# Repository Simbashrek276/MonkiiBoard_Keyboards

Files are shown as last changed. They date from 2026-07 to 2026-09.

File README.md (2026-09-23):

# MonkiiBoard Keyboards

Hi! This is the home for the MonkiiBoard keyboards, an open little family of boards you can build, flash and print yourself. There are five of them so far, and each one lives in its own folder with the Arduino code, a 3D printable case and a readme that walks you through it. Remember, for every build (aside from MonkiiPad16 and MonkiiBoard58), there will be 2 build pathways you can take, which are either handwiring or PCB-based builds. For starters, I would recommend choosing the handwiring option for certain keyboard builds, as it would make it much more easier to debug and fix using a multimeter and other tools as well!

## The boards

### MonkiiBoard58
MonkiiBoard58 is the newest and the most ambitious build here! This board packed fifty eight keys in a five by twelve ortholinear grid with a rotary encoder on the left, a ESP23 S3 WROOM U1 (Surface mounted component, not through hole) and no cable to the host at all since it runs wireless off a LiPo battery over Bluetooth (well of course we still have to charge the battery by pluggin the USB_C Receptacle in).

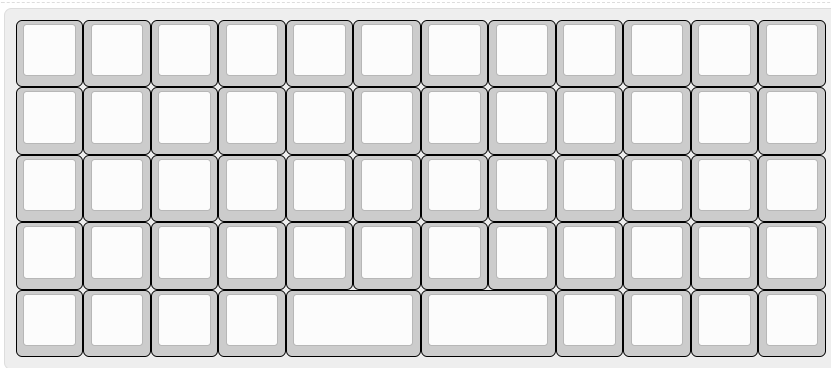
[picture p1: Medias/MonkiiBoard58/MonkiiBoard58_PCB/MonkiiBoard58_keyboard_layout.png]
MonkiiBoard58 layout only


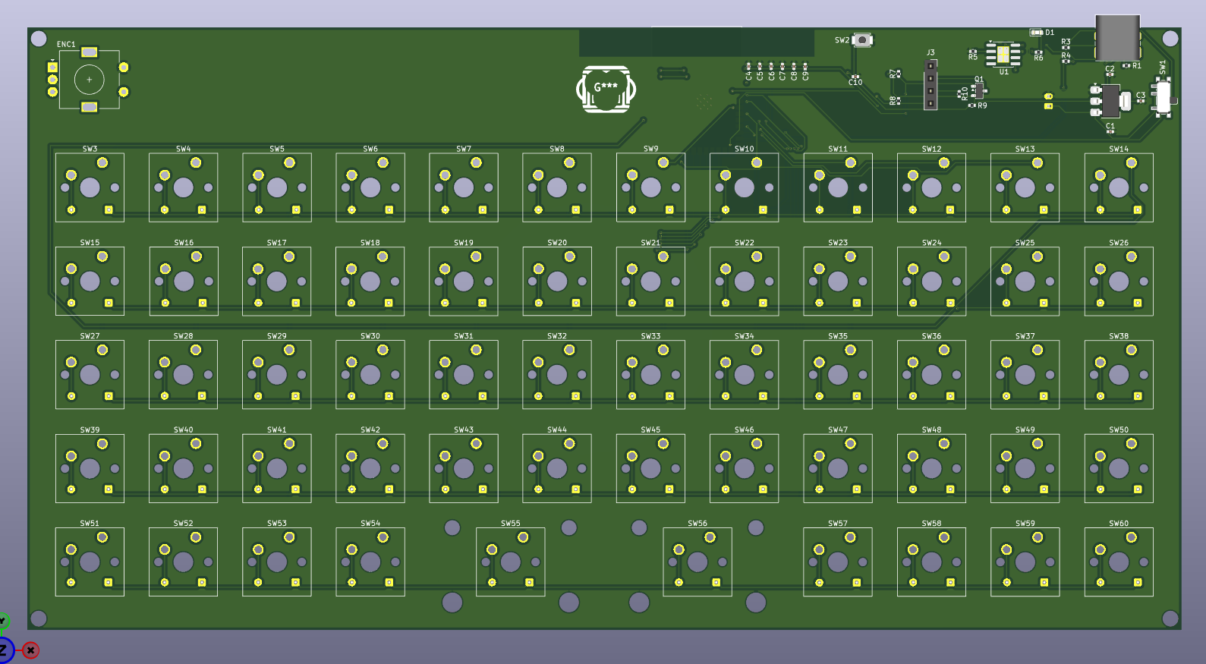
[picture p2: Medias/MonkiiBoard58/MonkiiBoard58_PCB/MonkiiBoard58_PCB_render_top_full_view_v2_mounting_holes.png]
The MonkiiBoard58 PCB rendered from the top, full grid with the OLED window and the encoder visible


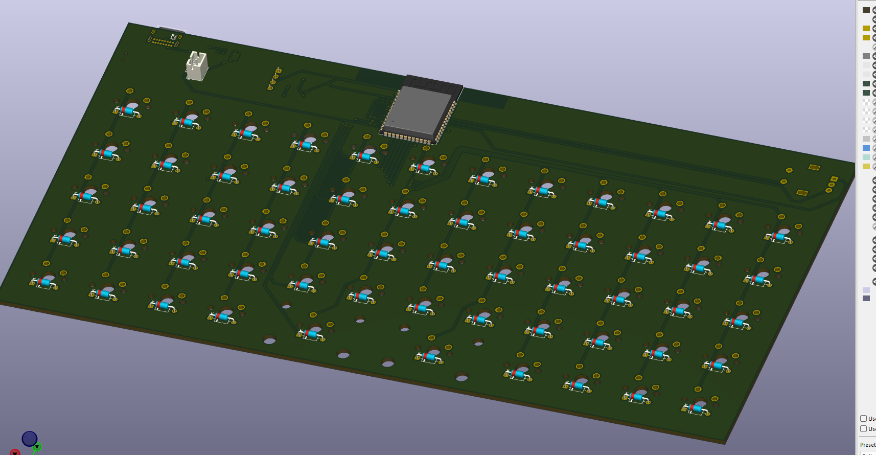
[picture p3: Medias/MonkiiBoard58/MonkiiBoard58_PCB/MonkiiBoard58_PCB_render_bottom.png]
The MonkiiBoard58 PCB rendered from the bottom with diodes (through hole), battery charge port (the white rising component, and the ESP32 S3 WROOM 1)


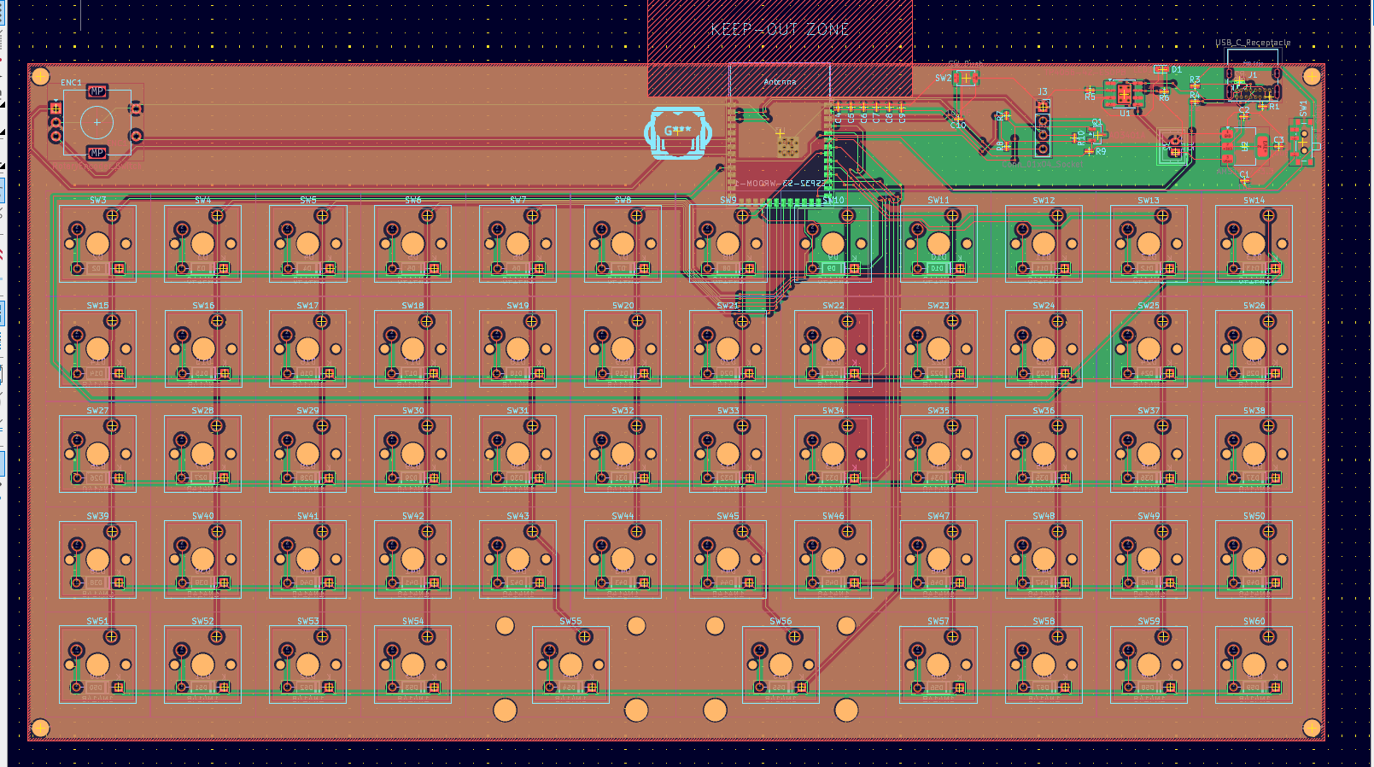
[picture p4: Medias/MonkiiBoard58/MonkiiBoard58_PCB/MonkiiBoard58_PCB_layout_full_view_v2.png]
MonkiiBoard58 PCB


Up to this point, this board only exists as a PCB, no hand wired version, since it carries its own LiPo charger, voltage regulator and a MOSFET power gate for the OLED right alongside the switch matrix. The schematic and layout are finished and the gerbers are ready, but the boards have not gone off to a manufacturer yet, so this is the one board here that has not actually been built in real life.

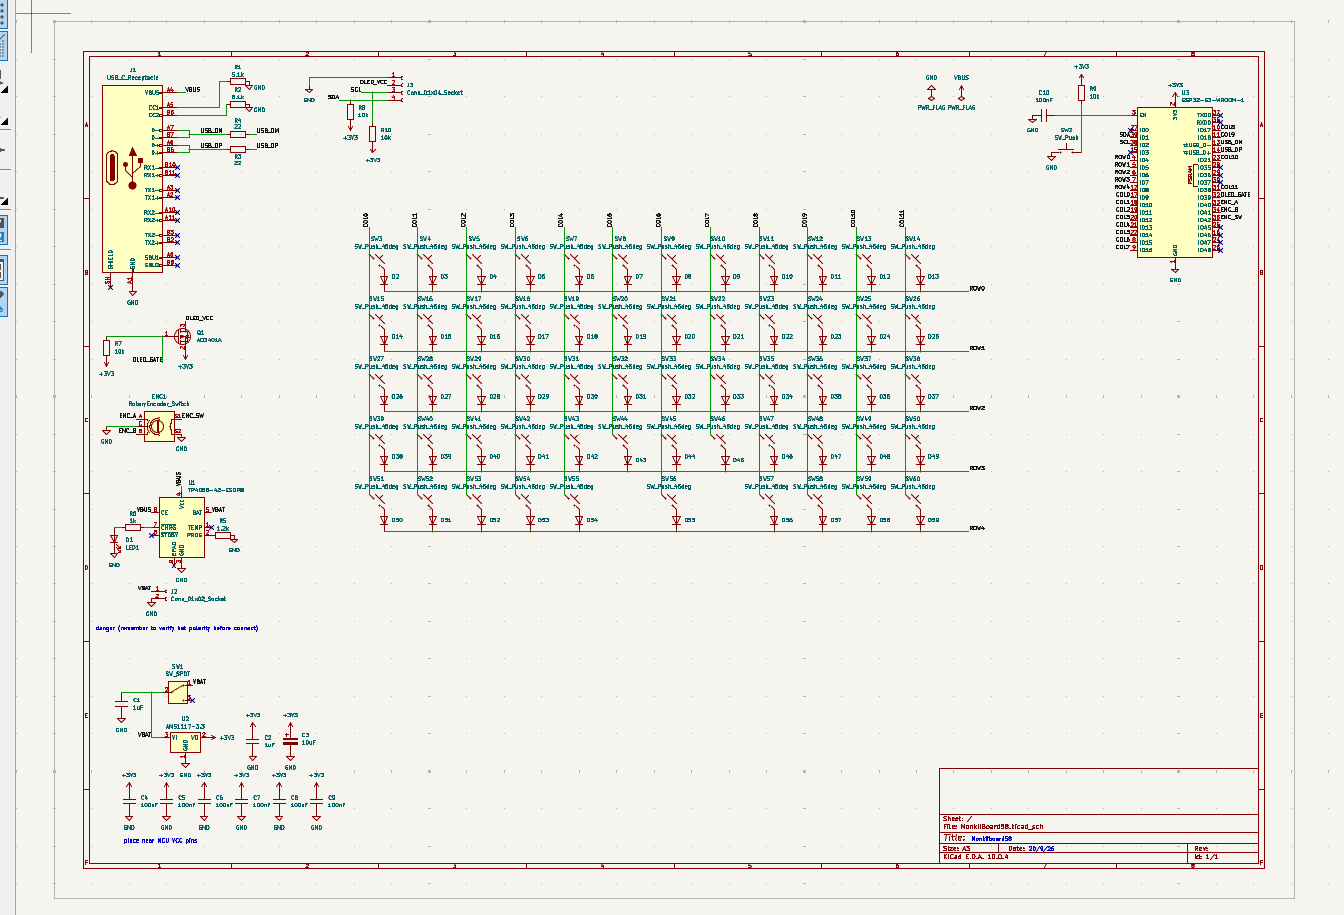
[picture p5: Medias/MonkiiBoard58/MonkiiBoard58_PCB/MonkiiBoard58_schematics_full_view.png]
The full schematic for MonkiiBoard58, matrix, ESP32 S3, OLED, encoder and the power section on one sheet


### MonkiiBoard39
MonkiiBoard39 is MonkiiBoard's second build. THis keyboard has thirty nine keys in a tidy ortholinear 40 percent layout, with sticky modifiers on the bottom row and a Windows key that pops the start menu on a double tap.

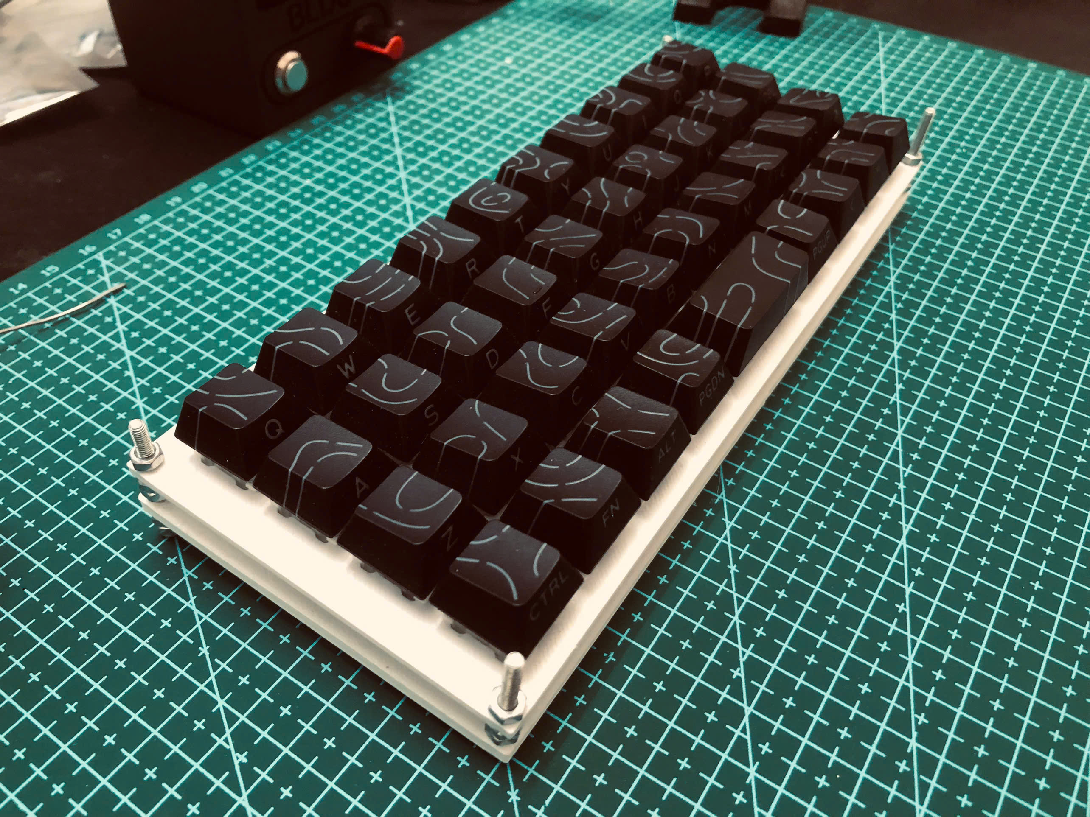
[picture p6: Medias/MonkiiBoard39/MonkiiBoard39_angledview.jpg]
The MonkiiBoard39 seen from an angle


MonkiiBoard39 has a PCB now too, no diodes on this one since the sticky modifiers never need more than one key held down at a time. The schematic below shows all thirty nine switches wired straight into the matrix, with the Pro Micro footprint sitting right in the middle of the board.

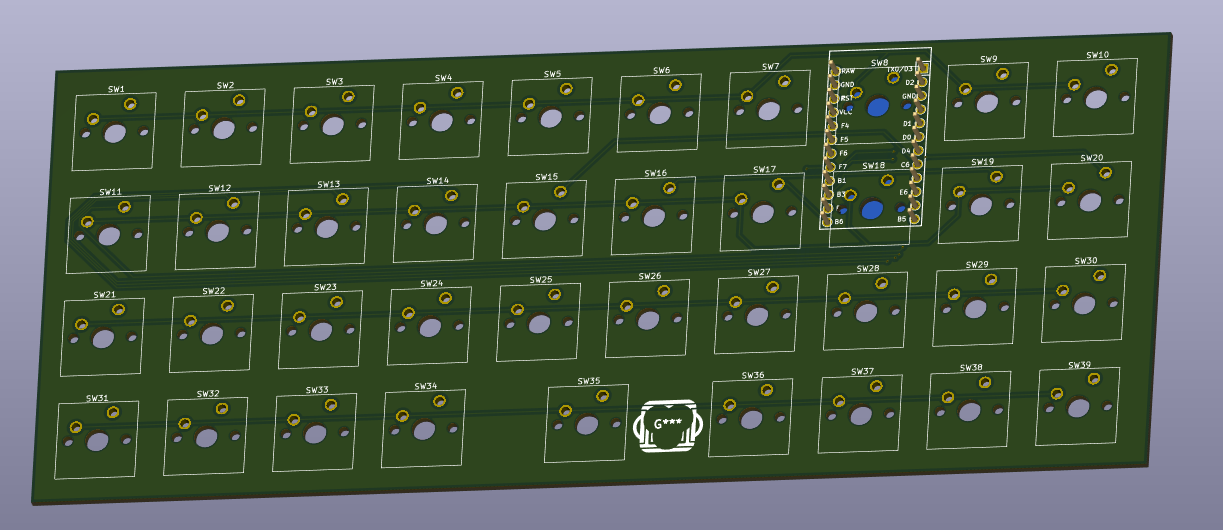
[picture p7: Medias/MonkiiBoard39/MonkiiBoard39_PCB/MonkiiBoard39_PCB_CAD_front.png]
The MonkiiBoard39 PCB rendered in KiCad, thirty nine switches around the Pro Micro footprint


### MonkiiPad20
MonkiiPad20 is our first keyboard with a OLED screen implemented. This macropad is a a twenty key macropad with an OLED screen, two switchable layers and a set of animated robot eyes that appear when you stop using it for a while (approximately 6 - 8 seconds). It is also the only board here that uses diodes (so far).

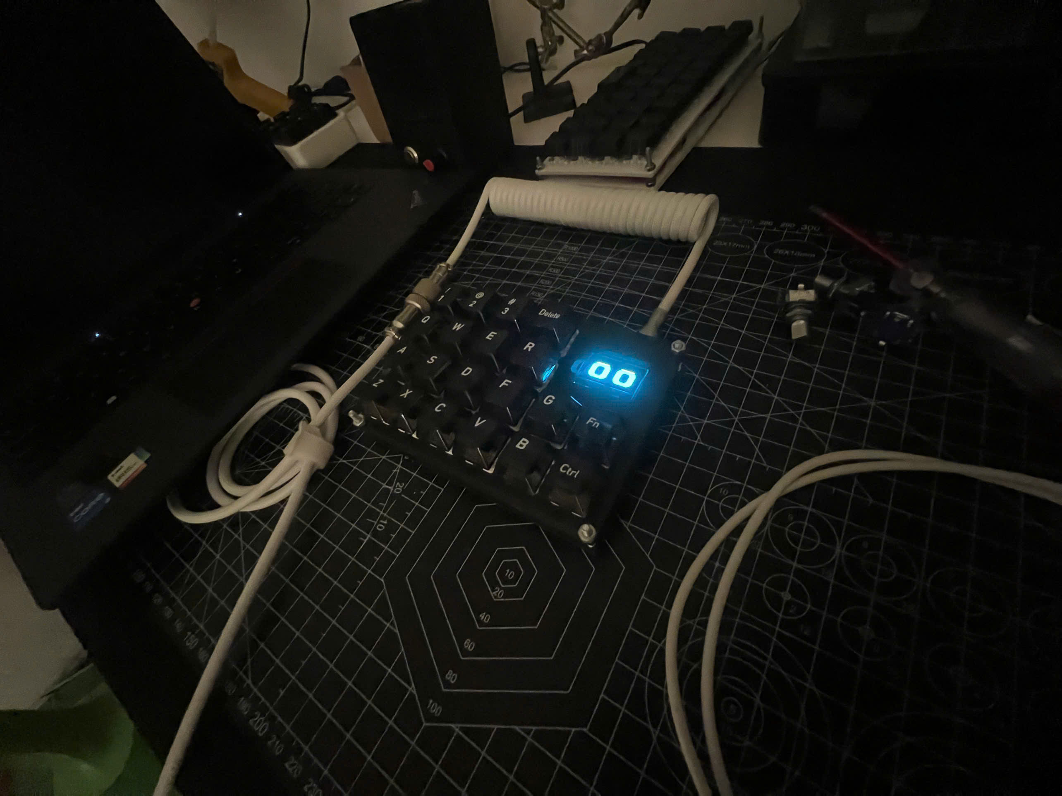
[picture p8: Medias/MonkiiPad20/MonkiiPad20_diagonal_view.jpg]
The MonkiiPad20 with its robot eyes glowing on the OLED


For the MonkiiPad20, we've also made our earliest PCB version 1 for this very macropad (if you choose to go the PCB path instead of the handwiring path)! The image below taken is the PCB, where you can see a silkscreen of our logo, MonkiiBoard, on the front layer.

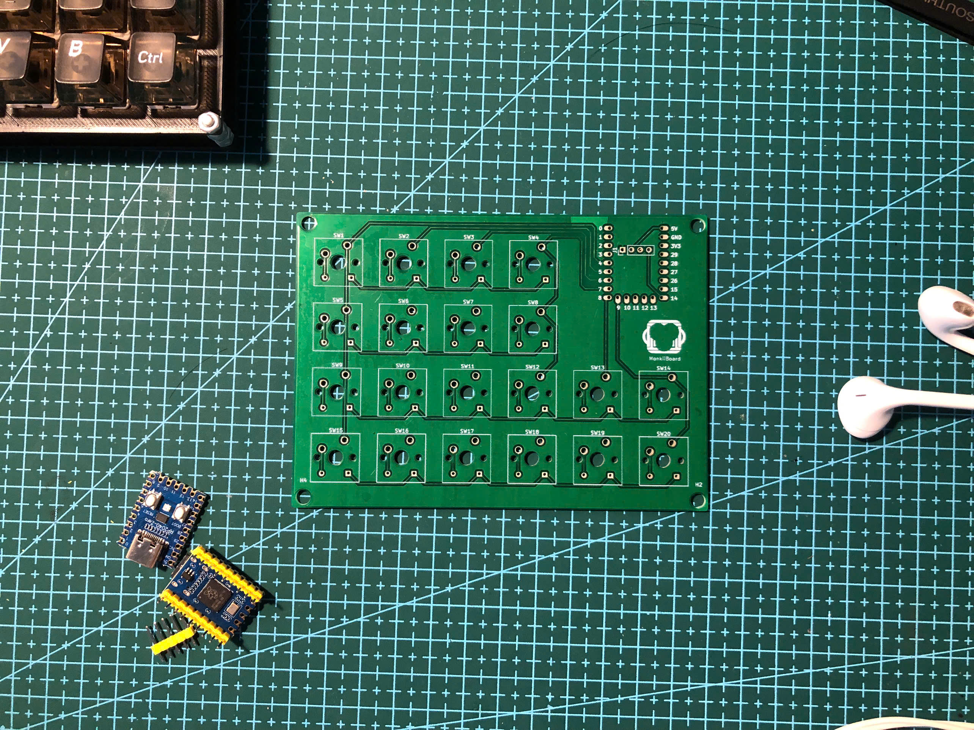
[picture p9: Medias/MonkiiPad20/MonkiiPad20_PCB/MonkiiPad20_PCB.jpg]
The MonkiiPad20's PCB top view


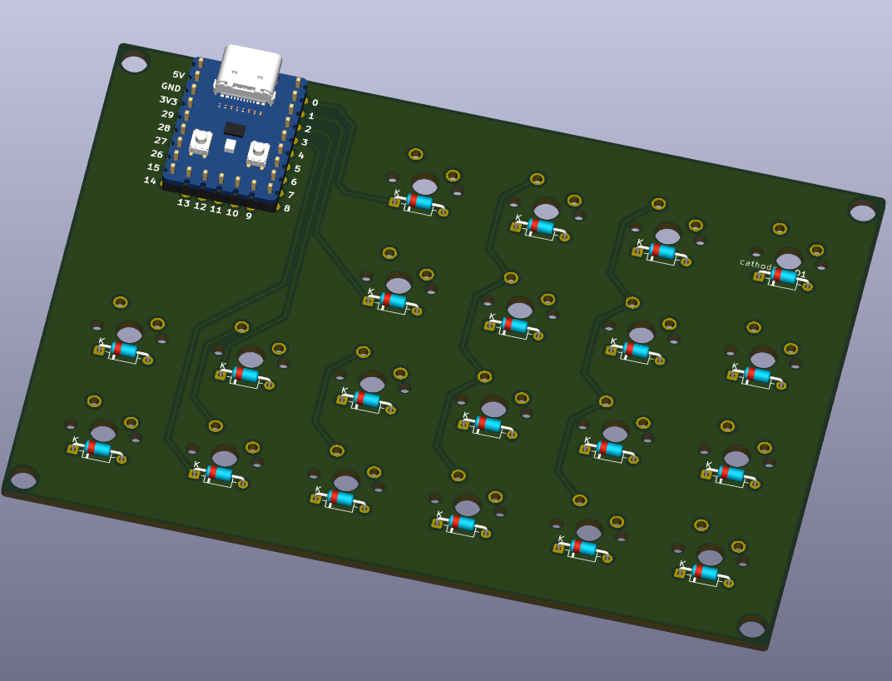
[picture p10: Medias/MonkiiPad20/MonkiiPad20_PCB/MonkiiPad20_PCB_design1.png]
The MonkiiPad20's PCB design on KiCad


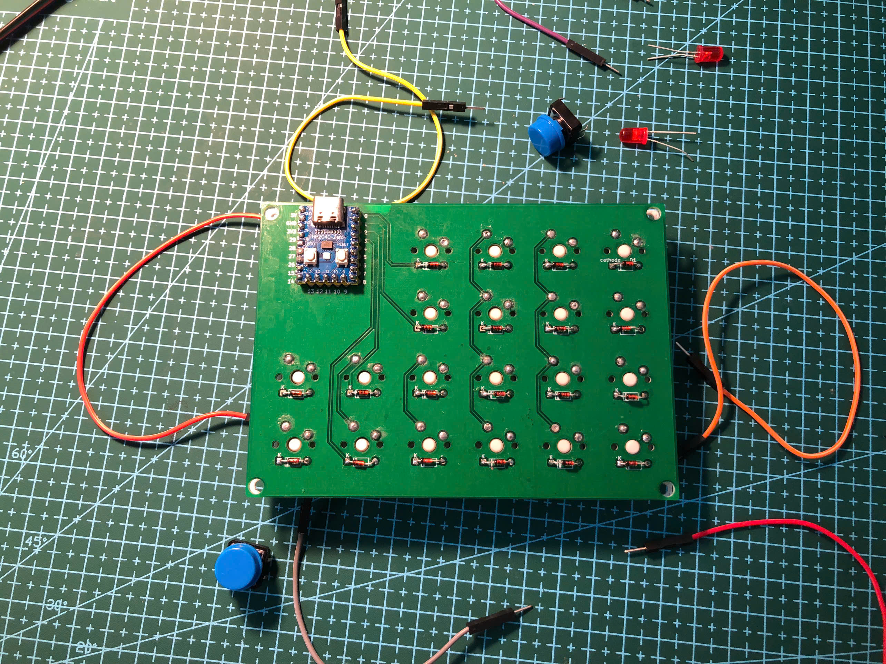
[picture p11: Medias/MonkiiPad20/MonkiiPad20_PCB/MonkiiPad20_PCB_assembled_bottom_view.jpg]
The MonkiiPad20's PCB assembled bottom view


### MonkiiBoard3x3
MonkiiPad3x3 is the first keyboard that we made!! It's a nine key pad that works as a plain number pad until you hold one key (the key "1") to flip it into a macro mode full of arrows and editing shortcuts.

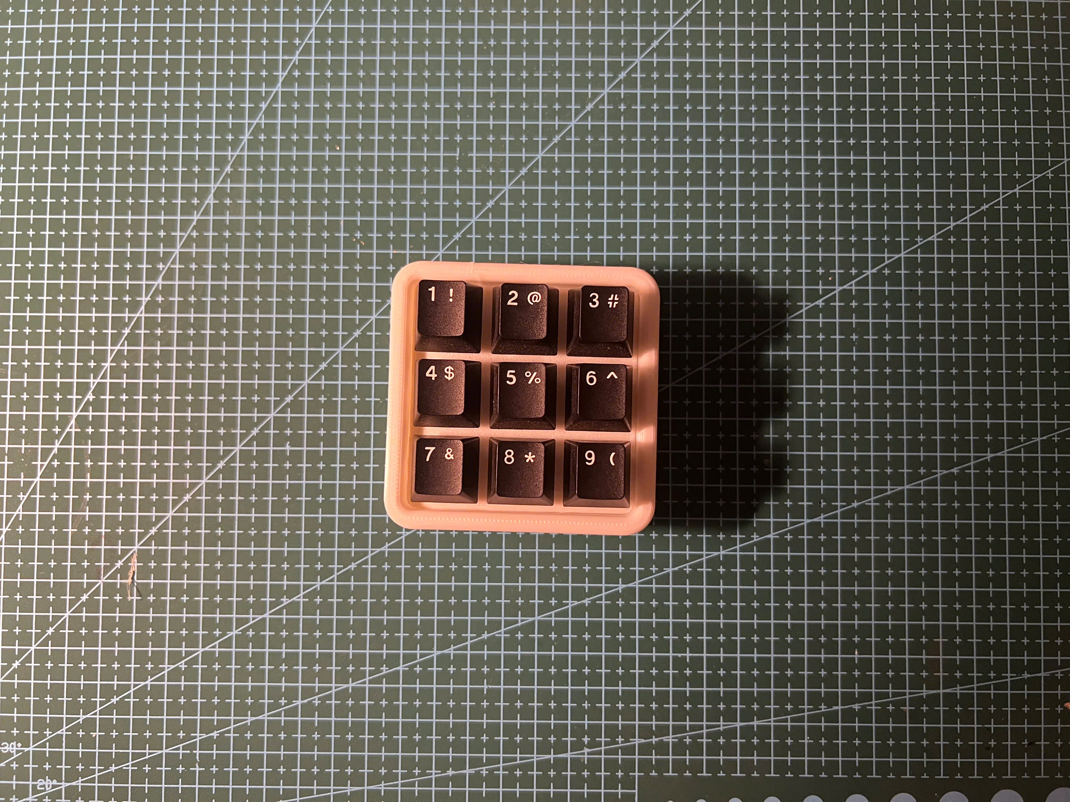
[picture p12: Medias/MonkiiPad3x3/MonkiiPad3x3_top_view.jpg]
The MonkiiPad3x3 numbered one to nine


MonkiiPad3x3 got the same treatment, a little PCB with all nine switches and the Pro Micro packed onto one small board, diode free just like MonkiiBoard39.

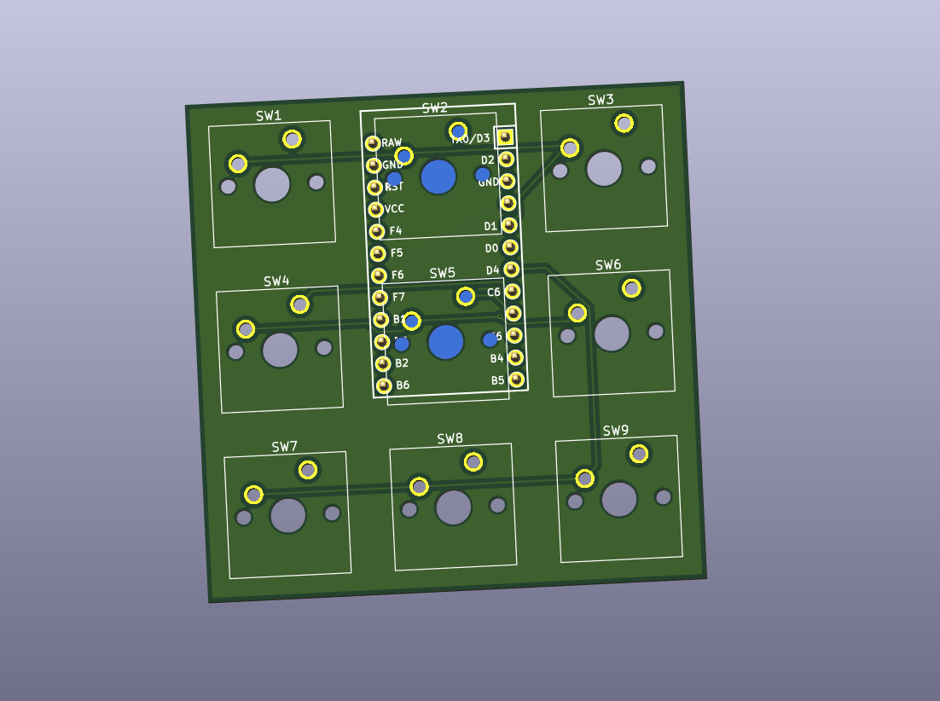
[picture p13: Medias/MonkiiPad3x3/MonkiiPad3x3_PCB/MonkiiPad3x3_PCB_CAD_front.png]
The MonkiiPad3x3 PCB rendered in KiCad, nine switches around the Pro Micro footprint


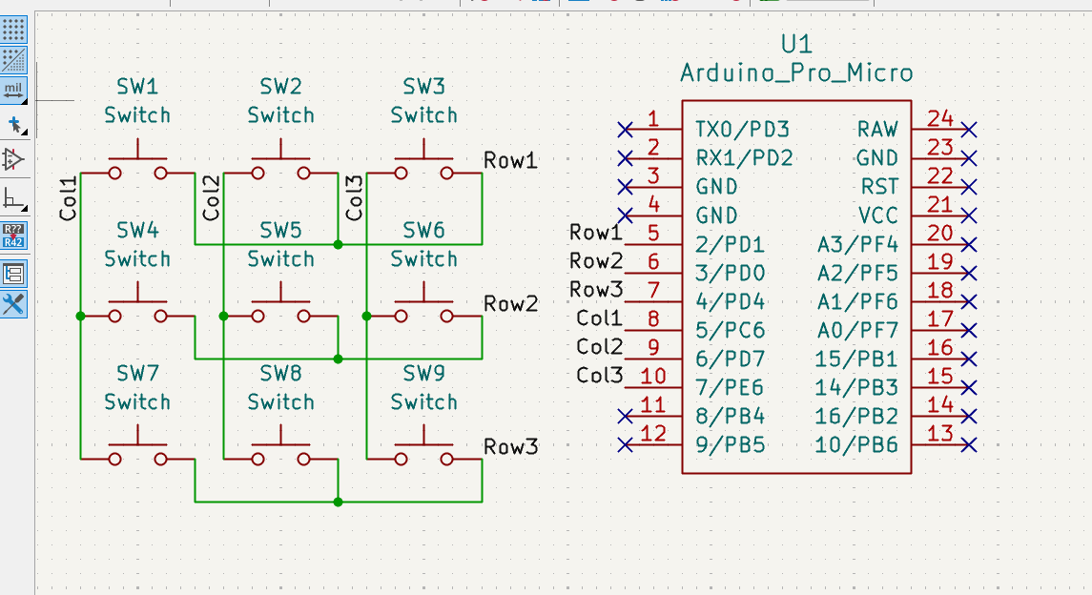
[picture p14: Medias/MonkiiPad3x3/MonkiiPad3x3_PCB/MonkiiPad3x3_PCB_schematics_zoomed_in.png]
The MonkiiPad3x3 schematic, nine switches wired into a three by three matrix with no diodes


### MonkiiPad16
MonkiiPad16 is our upgraded macropad, with a knob! This macropad has 16 keys and a rotary encoder, so instead of a second board or a held down FN key you just SPIN the knob to pick a layer, a numpad by default and a page of editing shortcuts one turn away.

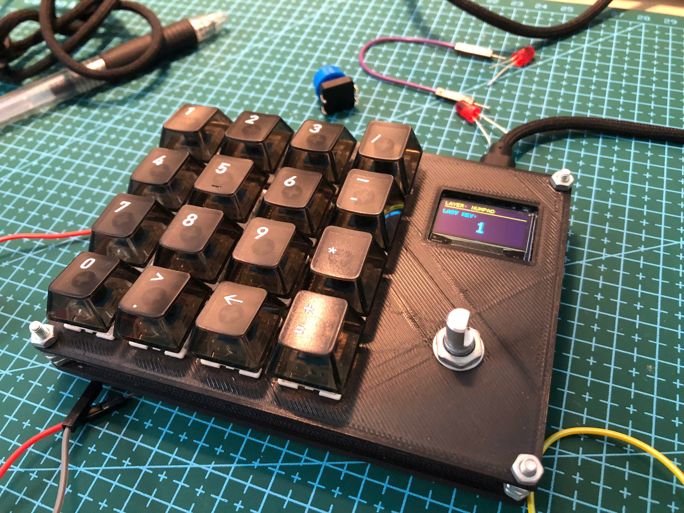
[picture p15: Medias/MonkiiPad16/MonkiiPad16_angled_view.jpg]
The MonkiiPad16 at an angle with the OLED lit up and the encoder knob beside it


## What is in each folder

Every folder is laid out the same way. There is a firmware folder with the Arduino sketch you flash onto the board, a case folder with the print ready STL plates you can drop straight into a slicer, and a readme that covers the wiring, the layout and whatever that particular board likes to do. MonkiiBoard58 is the exception for now, since it has not been built yet its folder only holds the PCB.

## Hand wired or PCB

We designed every board here except MonkiiPad16 and MonkiiBoard58 to be built either hand wired or on its PCB, same firmware and the same layout either way. Hand wiring asks a bit more of you on the materials side, thin gauge wire to run the rows and columns, insulating tape to keep the joints from touching each other, and a steadier hand while you solder everything point to point. The PCB skips all of that since the rows and columns are already routed for you, so it comes down to seating the parts and soldering them to the footprint.

| Needed for | Hand wired | PCB |
| --- | --- | --- |
| Soldering station | Yes | Yes |
| Multimeter | Yes | Yes |
| Solder | Yes | Yes |
| Switches | Yes | Yes |
| Controller board | Yes | Yes |
| Thin wire | Yes | No |
| Insulating tape | Yes | No |
| The PCB itself | No | Yes |

MonkiiPad20 and MonkiiBoard58 are the only boards that need diodes, both 1N4148s, one for every switch. MonkiiBoard39 and MonkiiPad3x3 skip them completely on both their hand wired and PCB builds, and we code the MCUs to enable toggling keys for combinations like Ctrl+C and Ctrl+V instead of holding Ctrl and then press the other button.

## A word on diodes

MonkiiPad20 and MonkiiBoard58 both have a diode sitting under each switch, which is what gives them a clean matrix and proper rollover. The other two boards skip the diodes to keep the build simple and cheap, so they are at their happiest when you press one or two keys at a time. Worth knowing before you start soldering, or before you order parts if MonkiiBoard58 is the one you are building.

## The PCBs at a glance

Four of the five boards now have a PCB option, all designed in KiCad as two layer boards. Here is how they compare.

| Board | Keys | Matrix | Diodes | Controller | Board size |
| --- | --- | --- | --- | --- | --- |
| MonkiiBoard39 | 39 | 4 by 10 | No | Pro Micro (ATmega32U4) | 195 by 80 mm |
| MonkiiPad20 | 20 | 4 by 6 | Yes | RP2040-Zero | 120 by 86 mm |
| MonkiiPad3x3 | 9 | 3 by 3 | No | Pro Micro (ATmega32U4) | 57 by 57 mm |
| MonkiiBoard58 | 58 | 5 by 12 | Yes | ESP32-S3-WROOM-1 N16R8 | 235.45 by 122.95 mm |

MonkiiBoard58 is also the only one of the four running wireless, with its own LiPo charging and voltage regulation on board, and the only one still waiting to actually be manufactured.

Each PCB folder has the full design story, the schematic, the gerbers to get one made, and the raw KiCad project if you want to tune or reroute your own version.

## Getting started

Pick the board you want, open its folder and read through its readme. Wire the matrix to match the pins listed there, flash the sketch from the Arduino IDE, print the plates from the case folder, and you have yourself a keyboard.

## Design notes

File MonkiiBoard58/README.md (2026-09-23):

# MonkiiBoard58

Hi everyone (again haha)! This is the most ambitious board in the family of MonkiiBoard so far. Fifty eight keys in a five row by twelve column ortholinear grid, a rotary encoder on the left, and no wire to the host at all, it runs wireless off a rechargeable LiPo battery over Bluetooth (though you still plug into the USB C receptacle whenever the battery needs a charge).

## PCB only, no hand wired version

Every other board in this family gives you the choice between hand wiring the matrix or ordering the PCB. MonkiiBoard58 does not, this one only exists as a PCB. With a LiPo charger, a voltage regulator, a MOSFET power switch for the OLED and a wireless module all sharing the same board, hand wiring something like this point to point was never really on the table. The schematic and layout are finished and the gerbers are ready, but the boards have not gone off to a manufacturer yet, so this is the one board in the whole family that has not actually been built in real life. Firmware and a case are next once boards are in hand. Like every other board here it is fully open source, so every file in this repository is free to build, copy or change however you like.

## The layout

There are 58 switches fill a 5x12 (row x column) grid, with two positions given up in the middle for the OLED cutout. The encoder sits on the left and a USB C receptacle in the top right corner handles charging.

The keyboard layout diagram showing every switch position across the grid, the OLED gap and the encoder

*This is the pre-rendered keyboard layout before building. I decided to go with 2 spacebars, each 2u in length to suits people who are still used to the normal row staggered layout*

We're planning to have three layers for the firmware. The base layer is a standard qwerty layout, the second is navigation with the arrow keys, home, end and page up and down, and the third holds the function row and media controls. The encoder gets its own behavior per layer too, volume by default, scrolling on the navigation layer and brightness on the function layer, with a push to mute.

## The schematics

I drew the matrix first, fifty eight switches each with their own 1N4148 diode, then moved on to the ESP32 S3 module, the OLED header, the encoder and the whole power section afterward.

The full schematic, every switch, diode, the ESP32 S3, the OLED header, the encoder and the power circuitry all in one sheet

*The board's full schematic*

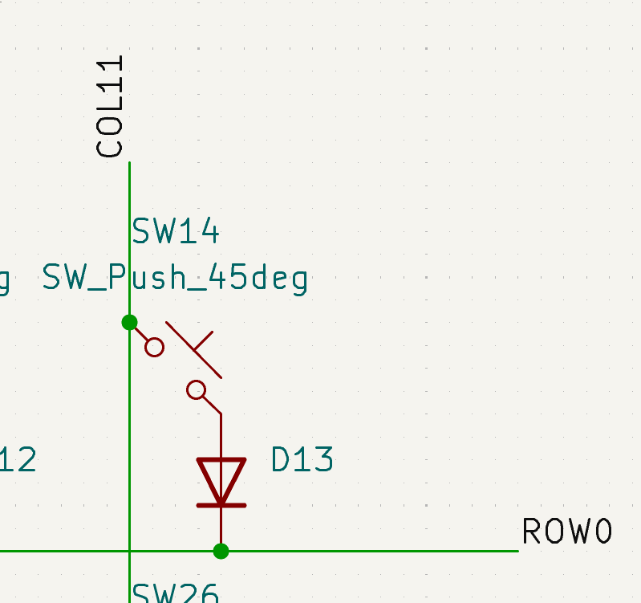
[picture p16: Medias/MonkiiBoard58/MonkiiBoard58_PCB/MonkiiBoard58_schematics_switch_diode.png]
One switch and its diode zoomed in, cathode facing the row line the way the rest of the matrix is wired


*A single switch among the 58 others. As seen, each is paired with a diode to prevent ghosting*

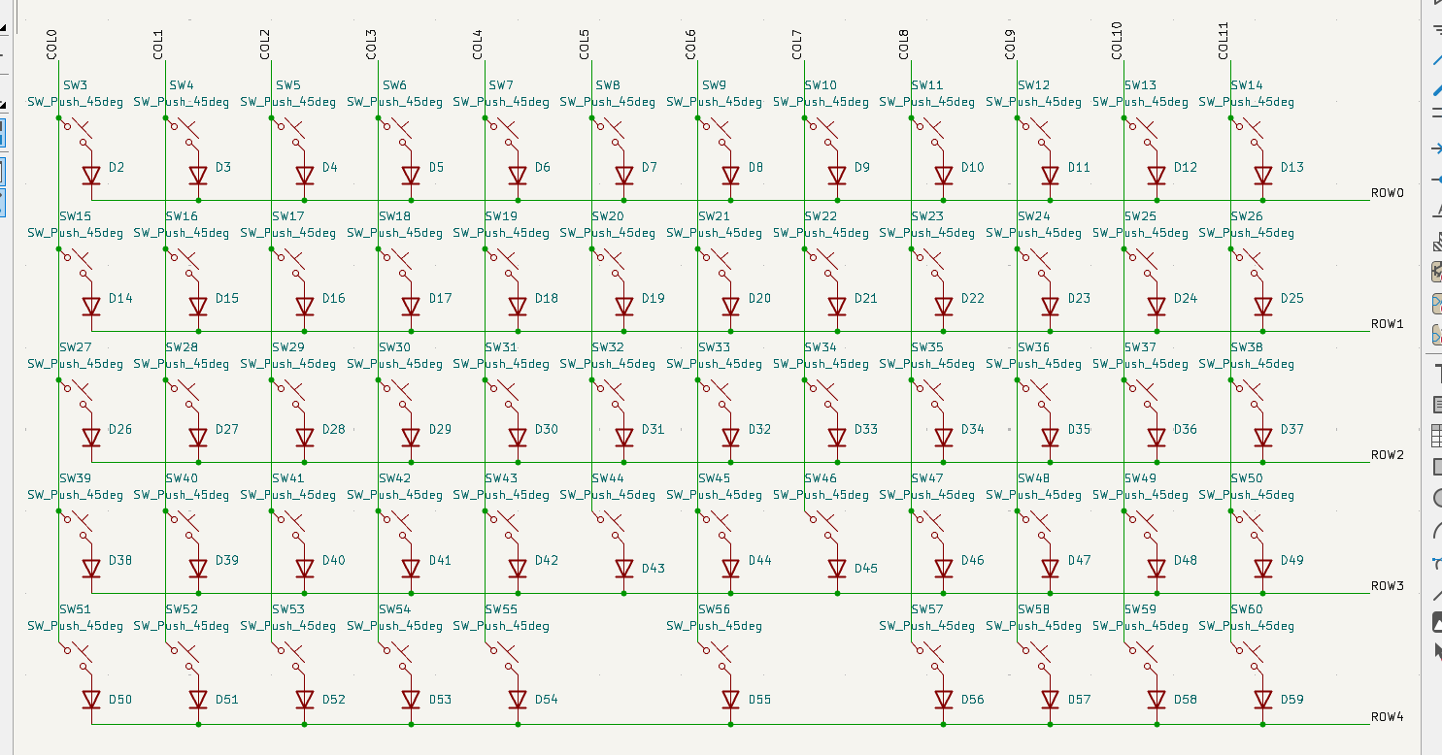
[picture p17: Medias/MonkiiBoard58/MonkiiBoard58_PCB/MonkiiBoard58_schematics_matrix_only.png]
Just the switch and diode matrix on its own sheet, fifty eight of them across five rows and twelve columns


*The switches and diodes matrix*

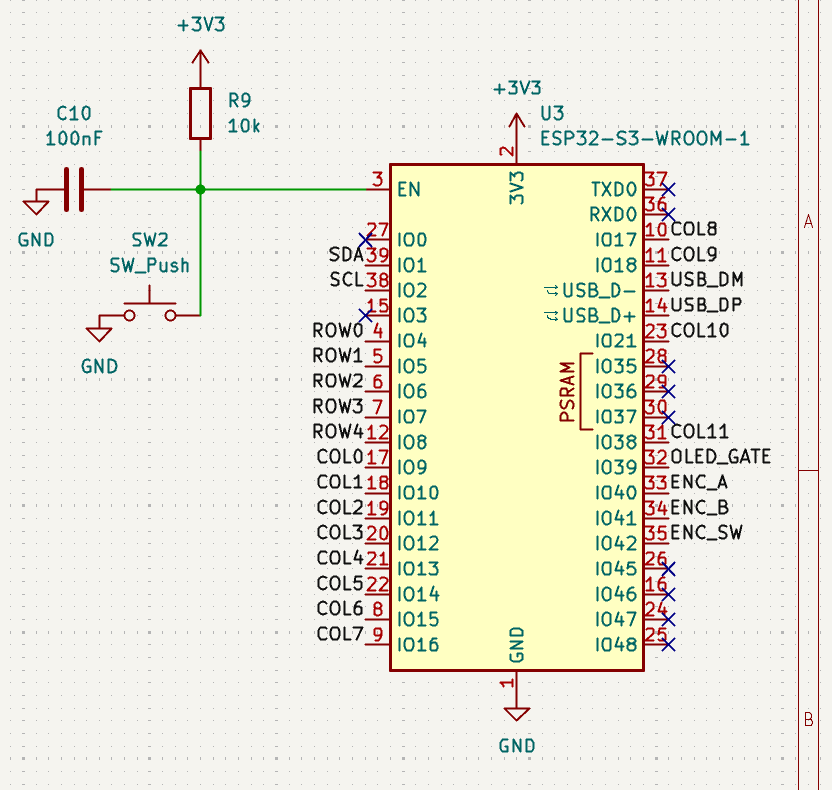
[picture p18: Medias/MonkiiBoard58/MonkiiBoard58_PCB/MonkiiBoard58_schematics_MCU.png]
The ESP32 S3 WROOM 1 module schematic with its decoupling caps and the antenna keep out area marked


*The ESP32 S3 module, a decoupling cap next to every VCC pin and the antenna keep out area marked off.*

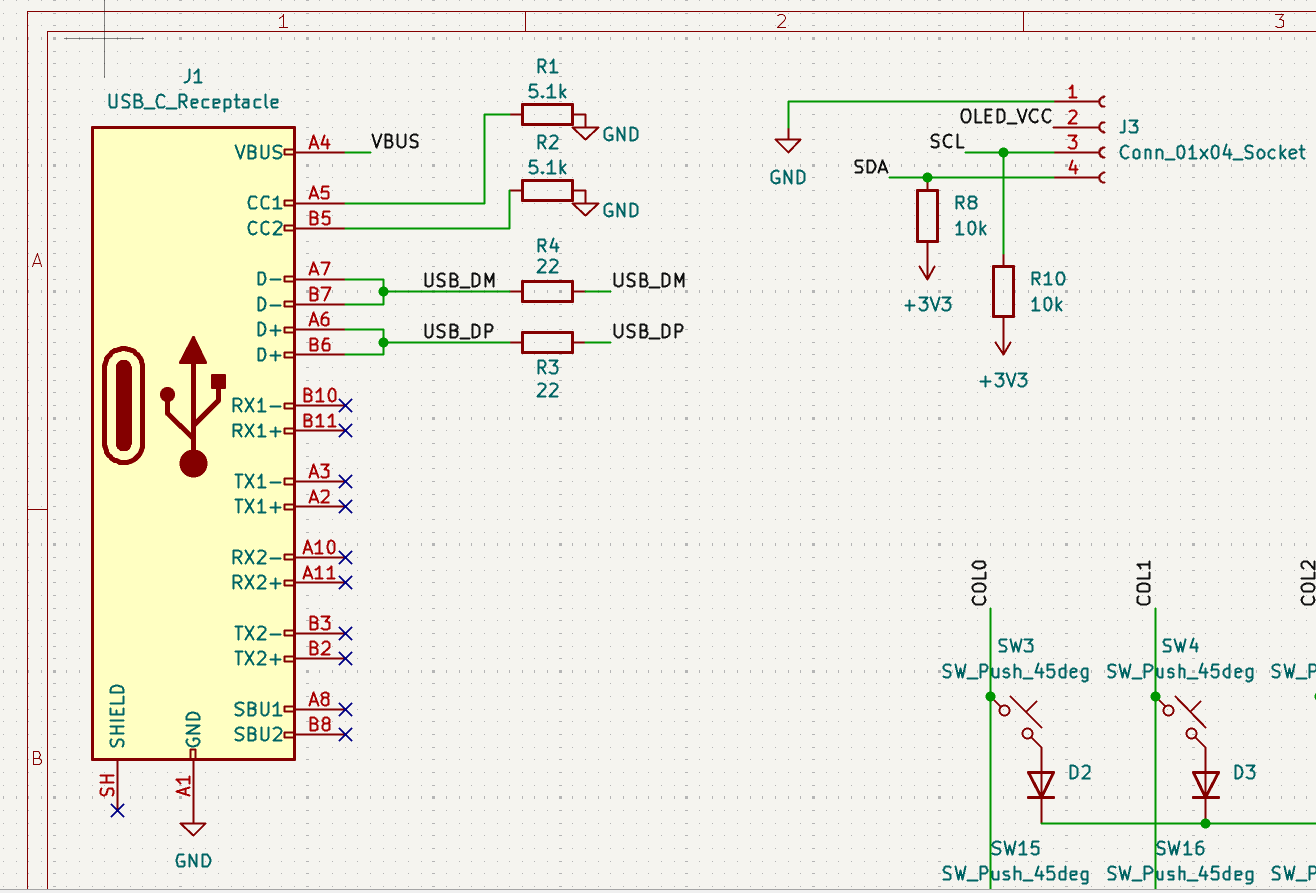
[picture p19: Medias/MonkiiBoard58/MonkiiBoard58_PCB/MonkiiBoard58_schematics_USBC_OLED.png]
The USB C receptacle and OLED header schematic, CC1 and CC2 each with their own pull down and the OLED on its four pin header


*USB C on one side with its own independent CC pull downs. The 4 pins on the top right corner are for the screen, which are for 0.91" OLED SSD1306 (its intake is SDA, SCL, VCC, and GND)*

The power side got its own sheet since there was too much going on to squeeze in next to the matrix. Battery connector, power switch, the AMS1117 regulator and its capacitors all sit together here.

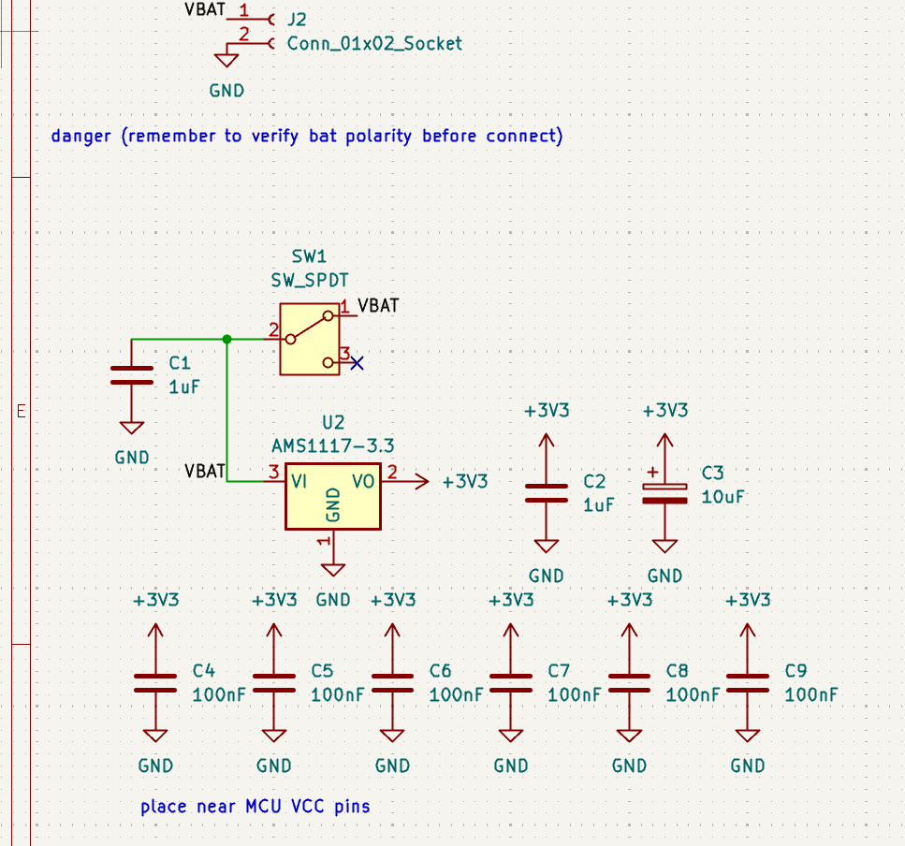
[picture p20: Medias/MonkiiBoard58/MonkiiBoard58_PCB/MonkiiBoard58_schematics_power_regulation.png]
The battery connector, slide power switch, AMS1117 LDO and its bypass capacitors


*Where the board actually gets its power from, the battery connector, the slide switch and the AMS1117 regulator with its capacitors.*

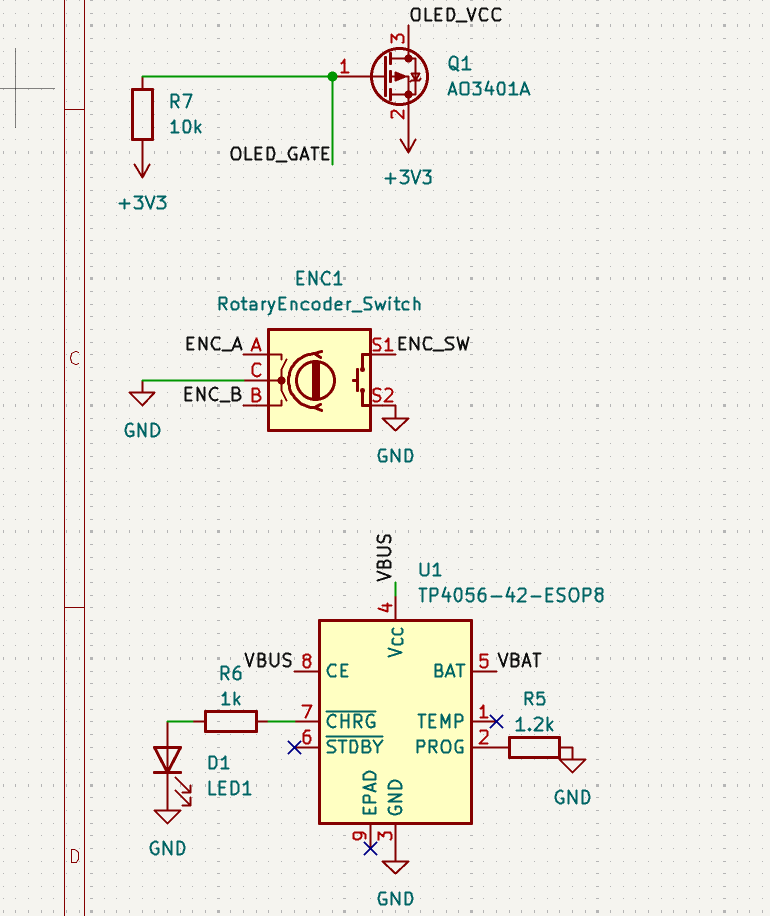
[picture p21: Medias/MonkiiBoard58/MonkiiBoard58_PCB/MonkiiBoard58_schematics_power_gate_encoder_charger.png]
The AO3401A power gate MOSFET, the EC11 encoder and the TP4056 charge circuit sharing one sheet


*The AO3401A that gates power to the OLED, the rotary encoder, and the TP4056 charge circuit all sharing the last sheet.*

## The parts before wiring

Before anything got soldered I laid every part out on the bench to check the footprints against the real components first.

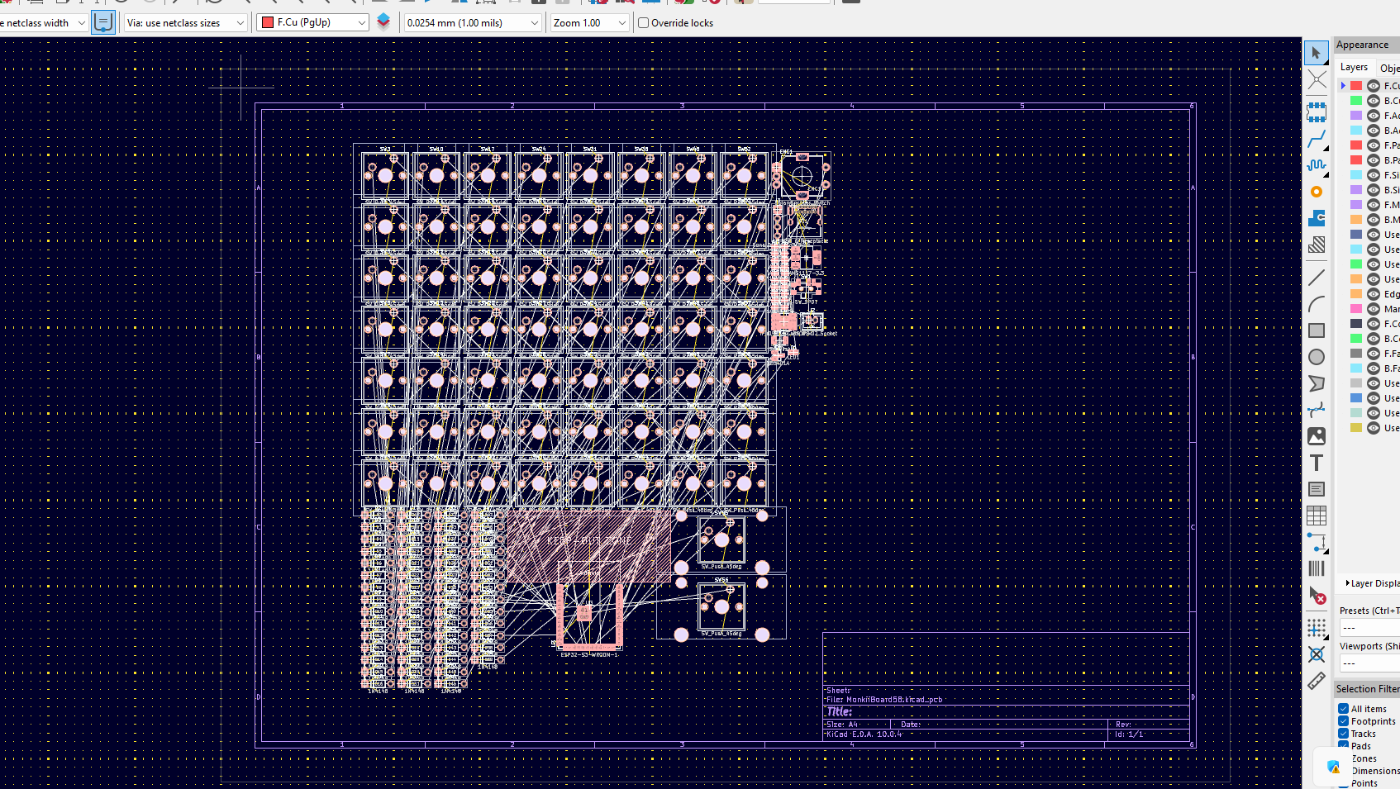
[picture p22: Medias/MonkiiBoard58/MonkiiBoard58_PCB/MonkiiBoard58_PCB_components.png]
Every component laid out before wiring and placing them onto the board


*Every part for this build laid out on the bench before a single one got soldered down.*

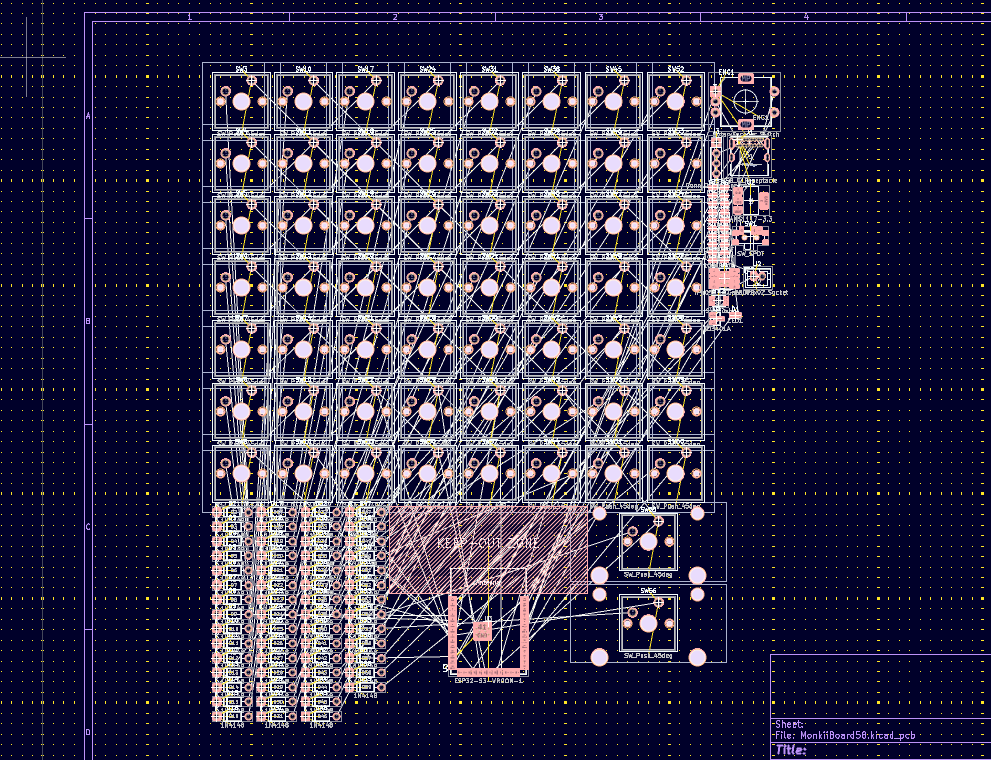
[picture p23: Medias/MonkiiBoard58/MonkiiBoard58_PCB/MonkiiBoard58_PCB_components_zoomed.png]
A closer look at the same parts, zoomed in


*The same layout zoomed in so the smaller SMD parts are actually readable.*

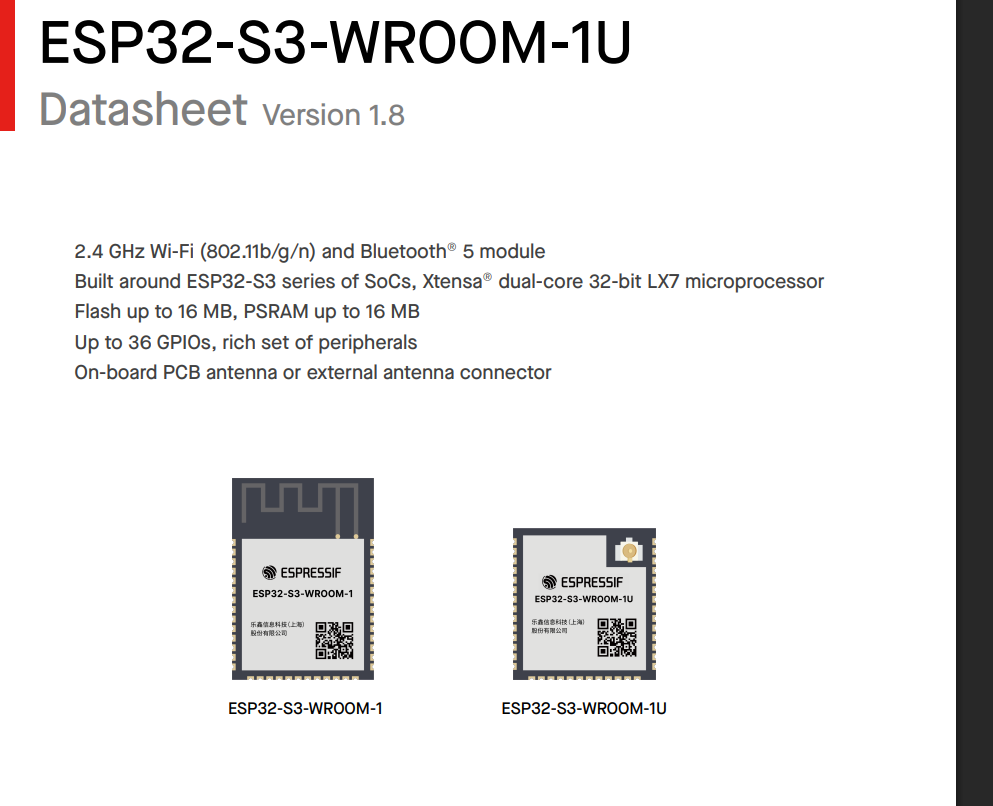
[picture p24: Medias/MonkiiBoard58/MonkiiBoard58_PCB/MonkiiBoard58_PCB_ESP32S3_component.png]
The ESP32 S3 WROOM 1 module itself, the SMD part that runs the whole board


*The ESP32 S3 WROOM 1 module by itself, the one part that everything else on this board answers to.*

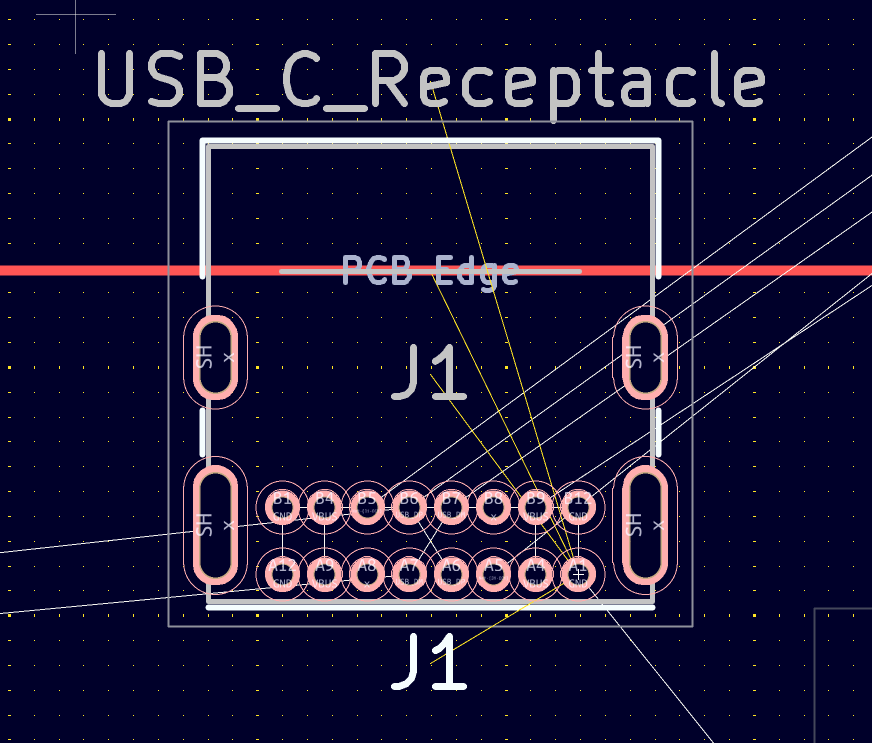
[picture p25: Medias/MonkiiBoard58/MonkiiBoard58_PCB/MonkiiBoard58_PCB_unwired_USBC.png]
The USB C receptacle sitting unwired before it gets connected in


*The USB C receptacle sitting loose, not yet connected to anything.*

## The PCB editor, wired

The first pass at routing did not have a single mounting hole anywhere on the board, which would have left no way to actually screw it into a case later. Version two added four of them, one in each corner.

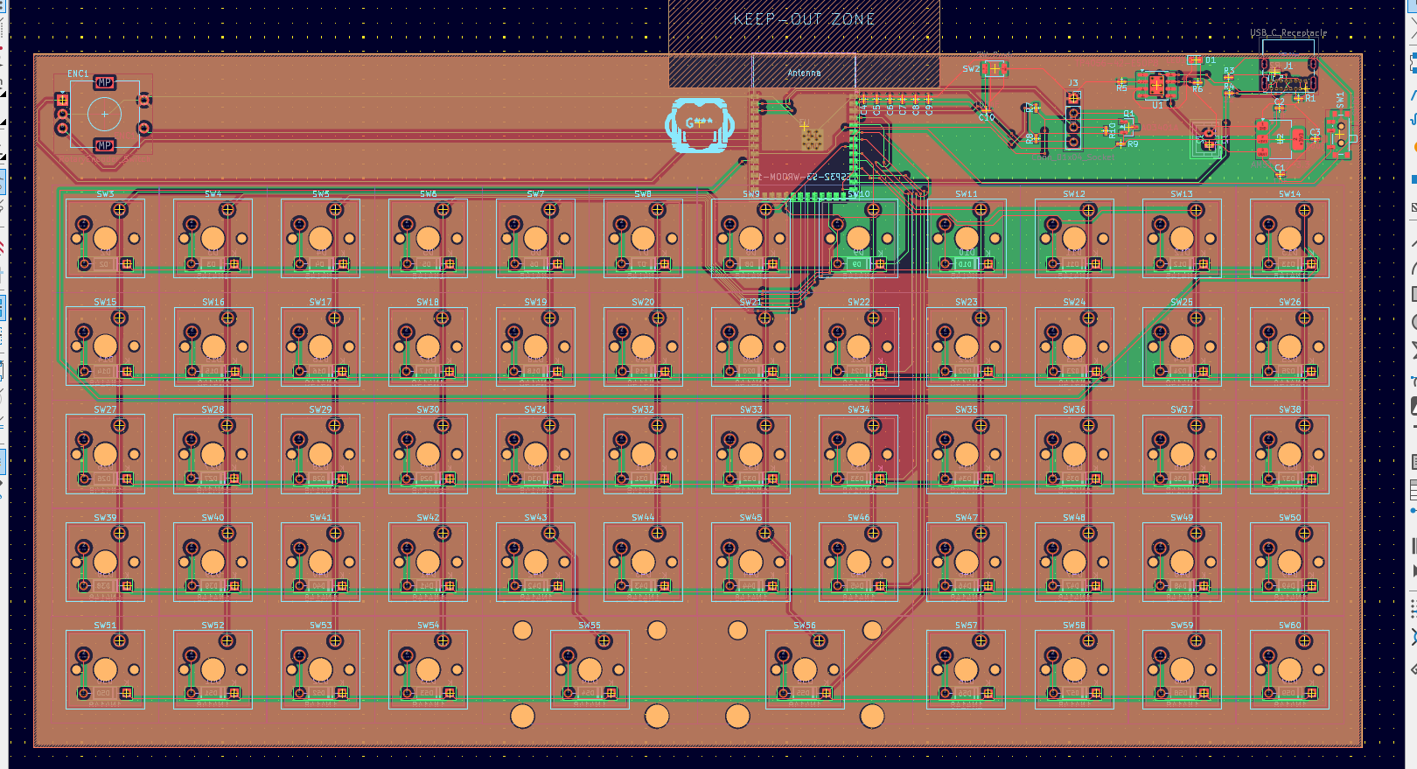
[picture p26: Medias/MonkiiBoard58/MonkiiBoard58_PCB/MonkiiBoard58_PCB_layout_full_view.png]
The routed PCB with GND fill turned on, no mounting holes yet in this version


*The first routed version, GND fill turned on, and not a single mounting hole in sight.*

The same layout with four mounting holes added in the corners

*The fixed version with four mounting holes added in the corners so this can actually be screwed into a case.*

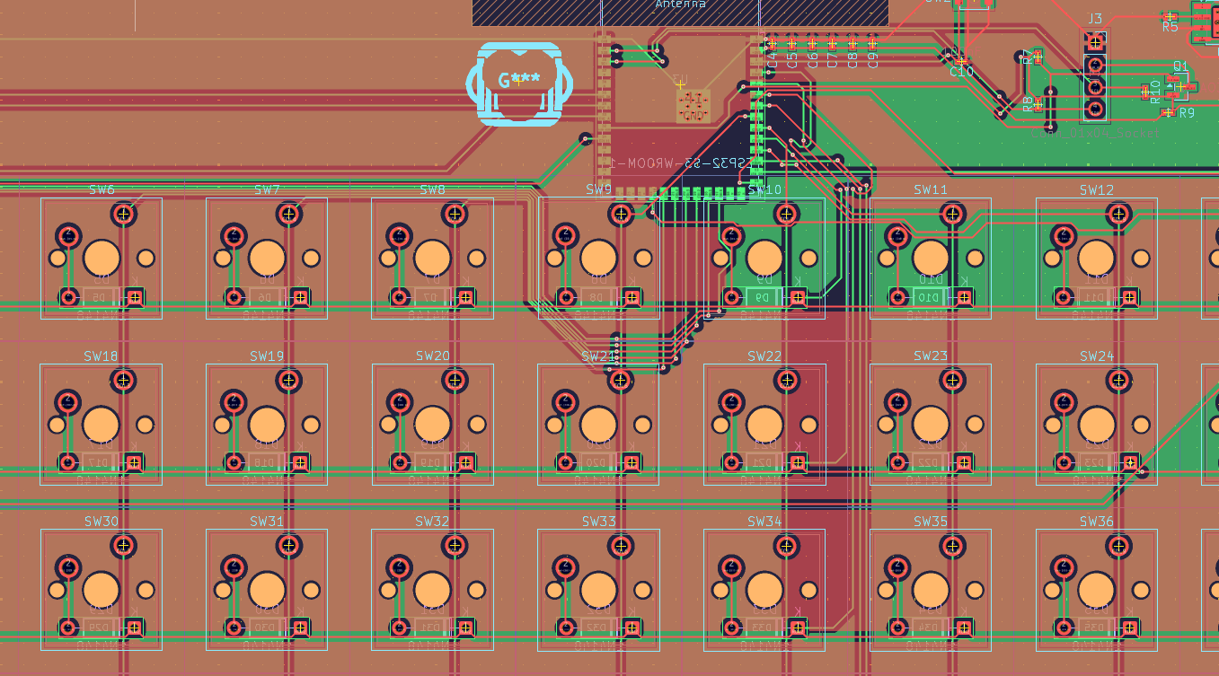
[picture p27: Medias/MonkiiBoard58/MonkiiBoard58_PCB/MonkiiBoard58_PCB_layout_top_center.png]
A closer look at the top center of the board where the ESP32 S3 module sits


*Zoomed into the top center where the ESP32 S3 footprint and its traces sit.*

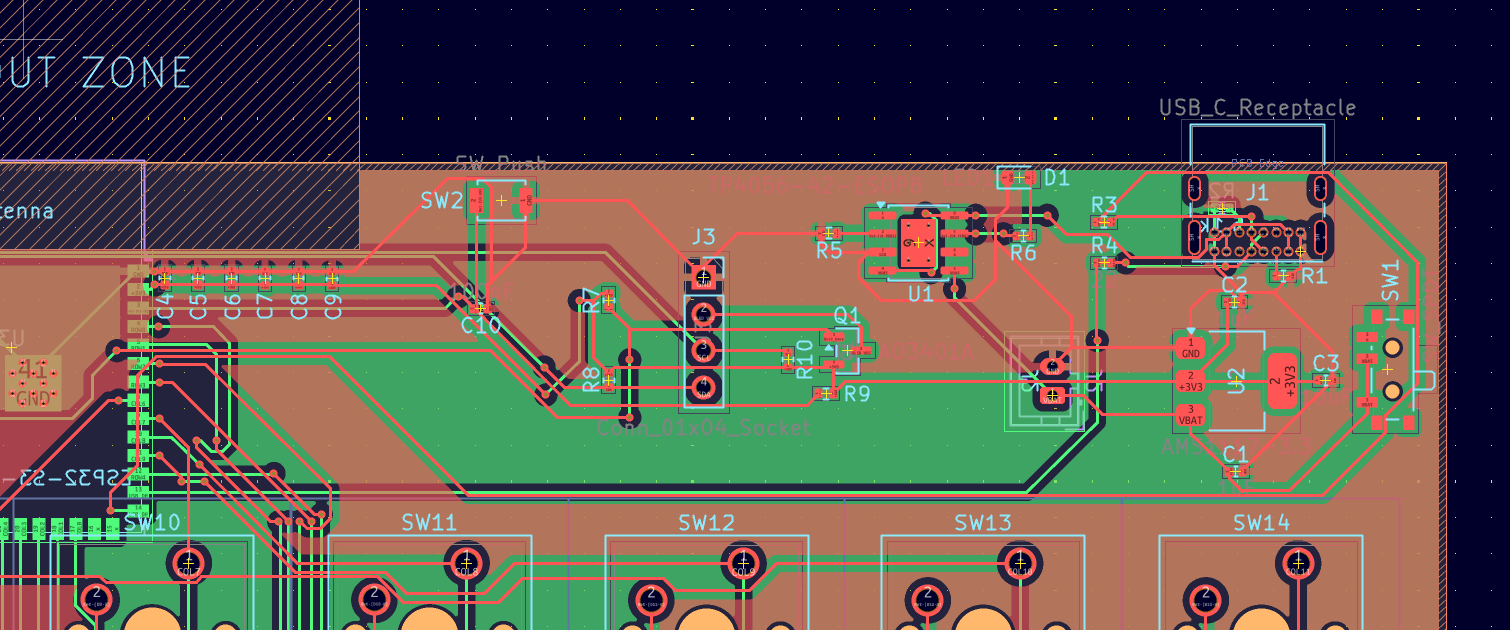
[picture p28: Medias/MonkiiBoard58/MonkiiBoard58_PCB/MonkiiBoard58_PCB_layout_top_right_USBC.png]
The top right corner of the board around the USB C receptacle


*The top right corner where the USB C receptacle and its traces are routed.*

With the routing settled I went back through and wired up each section for real, checking every connection against the schematic as I went.

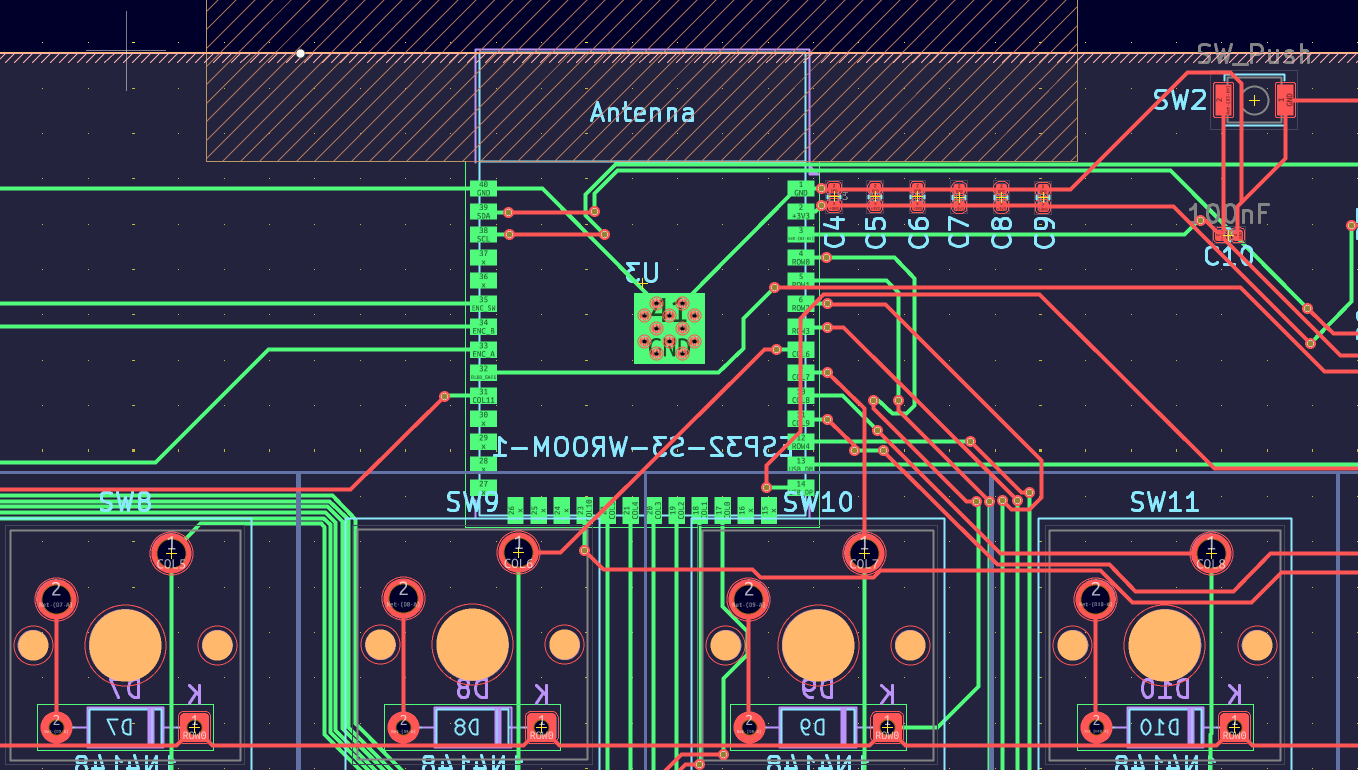
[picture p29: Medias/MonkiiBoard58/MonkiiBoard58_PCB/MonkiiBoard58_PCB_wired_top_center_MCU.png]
The top center area wired up with the ESP32 S3 footprint in focus


*The ESP32 S3 area after the real wiring pass, checked against the schematic connection by connection.*

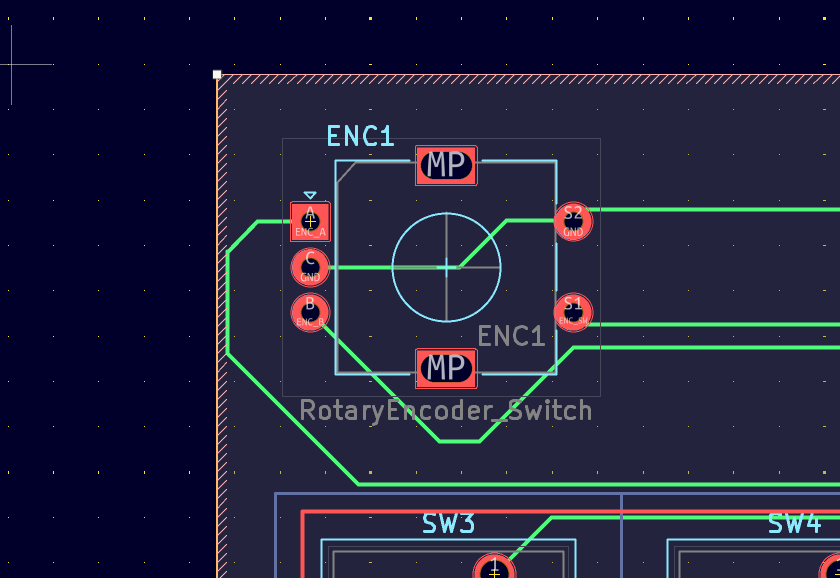
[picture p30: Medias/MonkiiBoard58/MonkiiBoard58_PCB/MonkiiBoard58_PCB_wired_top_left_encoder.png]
The top left corner wired up around the EC11 rotary encoder


*The rotary encoder corner once its connections were wired in for real.*

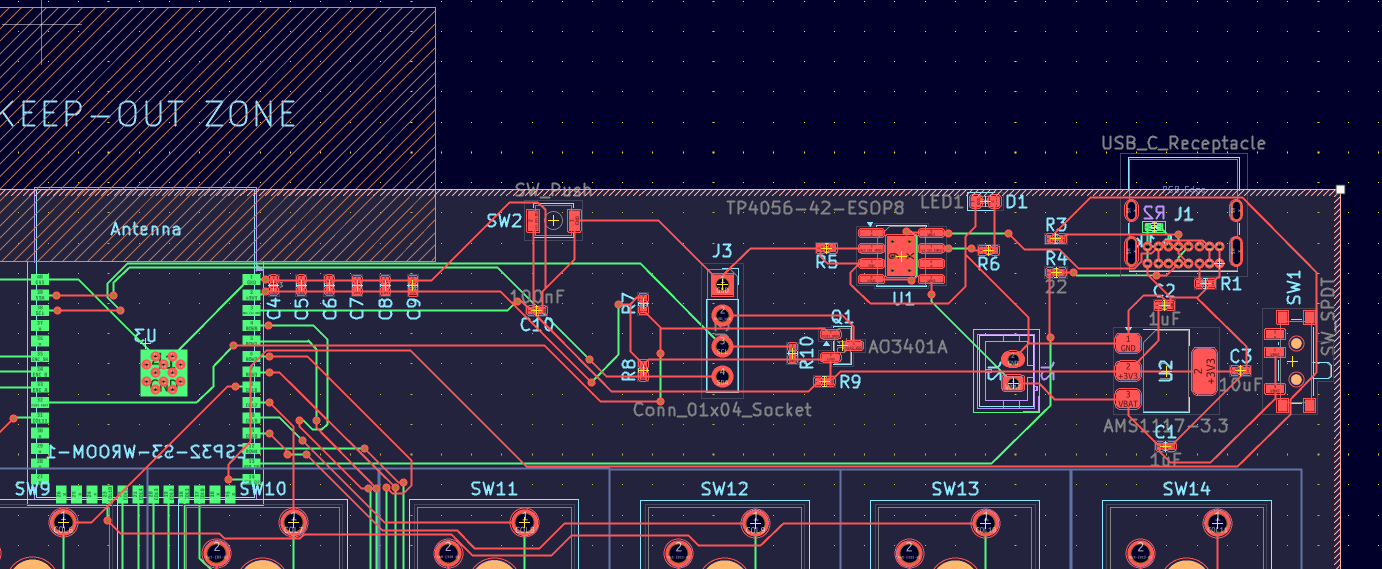
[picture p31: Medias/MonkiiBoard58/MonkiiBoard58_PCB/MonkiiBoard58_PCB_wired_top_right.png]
The top right corner wired up, no GND fill so the individual traces are easy to follow


*The USB C corner with GND fill turned off so every individual trace is easy to follow.*

## The PCB, rendered

Once the routing was done I pulled it into KiCad's 3D viewer to see the actual board rather than just traces on a grid.

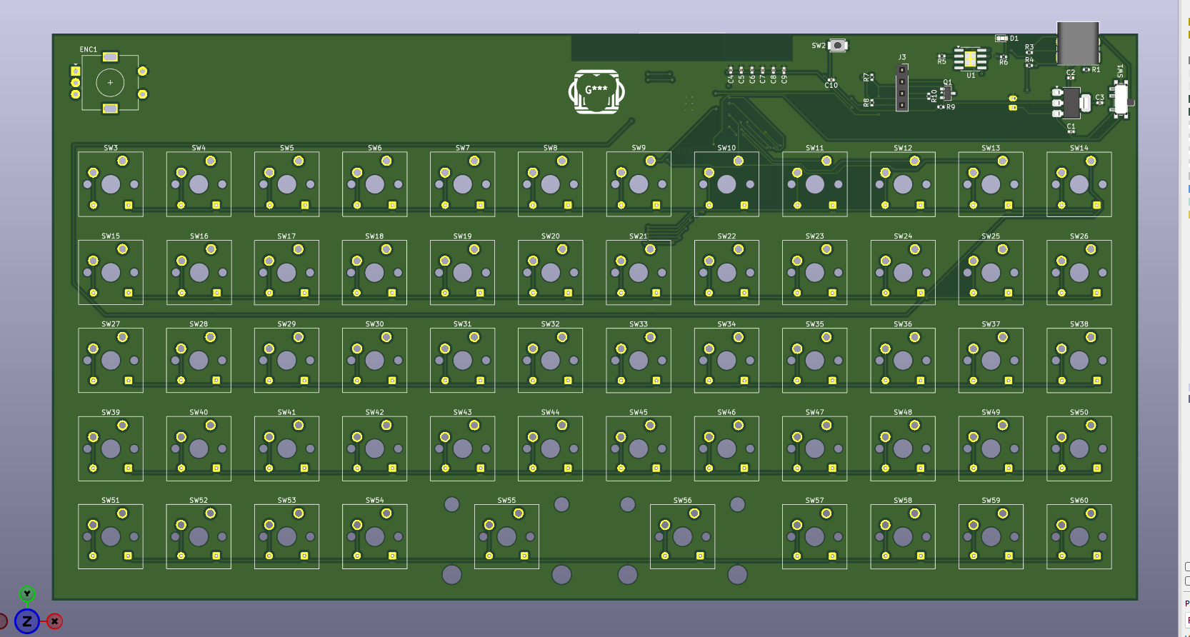
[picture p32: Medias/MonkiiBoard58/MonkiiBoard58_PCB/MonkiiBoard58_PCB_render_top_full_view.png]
The finished PCB rendered from the top, full view


*The board rendered from directly above, from before the mounting holes were added.*

The same top view after version two added the four mounting holes

*The same top down render after the four mounting holes went in, this is the current version.*

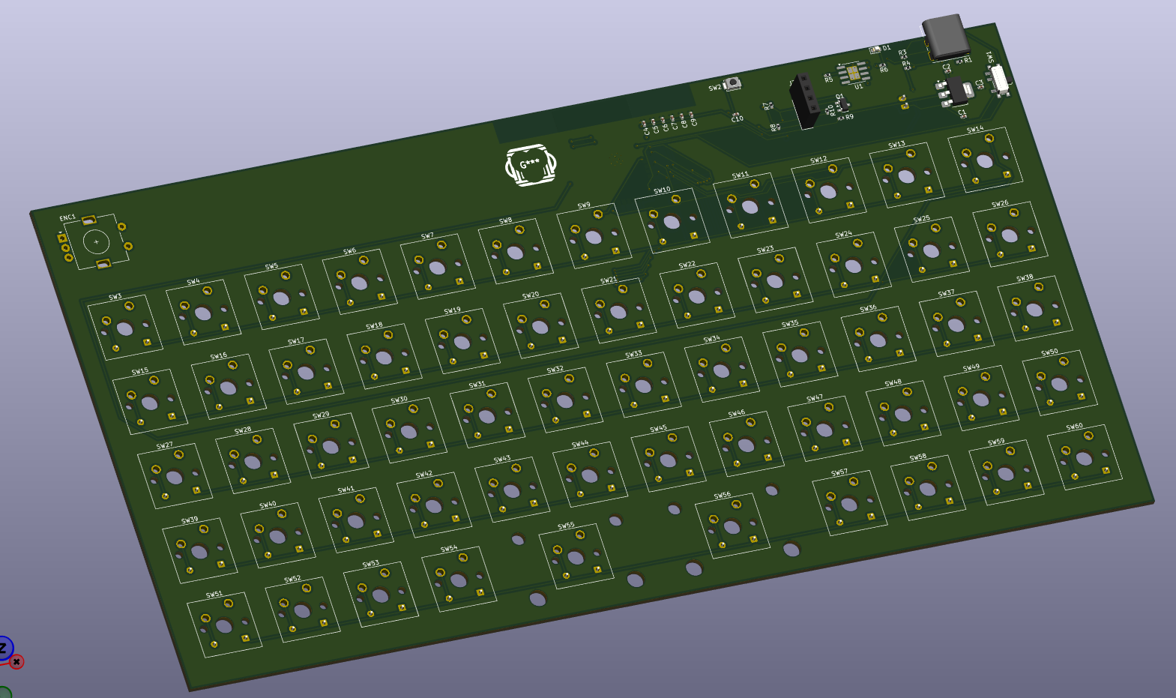
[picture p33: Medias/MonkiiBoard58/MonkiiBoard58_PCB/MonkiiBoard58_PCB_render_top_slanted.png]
The top of the board at a slanted angle


*The top of the board from an angle instead of straight on, easier to get a feel for the actual size.*

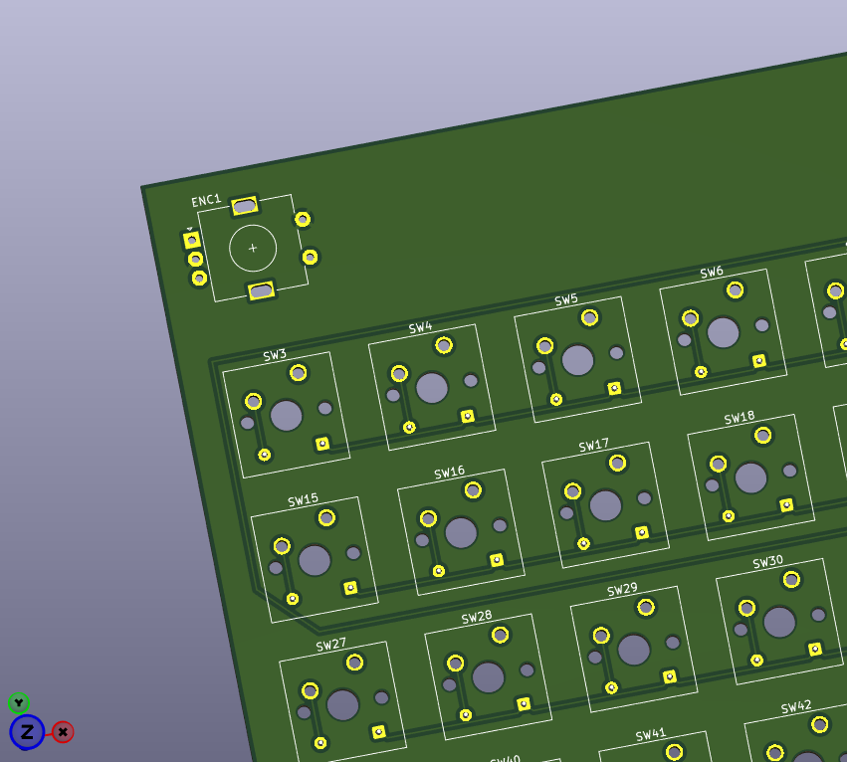
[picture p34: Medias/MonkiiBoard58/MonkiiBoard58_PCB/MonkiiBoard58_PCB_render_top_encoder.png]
A closer look at the rotary encoder from the top render


*A closer render of the rotary encoder corner.*

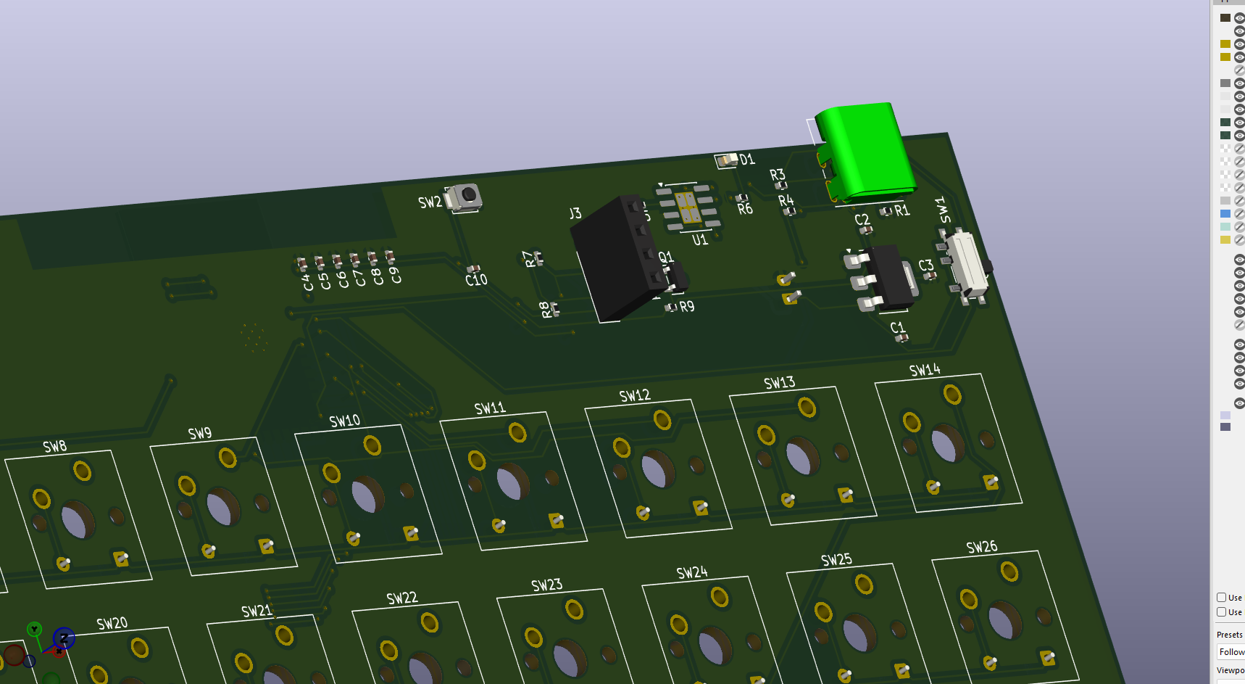
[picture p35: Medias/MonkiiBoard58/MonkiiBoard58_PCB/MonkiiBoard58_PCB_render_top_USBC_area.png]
The top right corner of the render around the USB C receptacle


*A closer render of the USB C receptacle corner.*

The bottom face of the board rendered in full

*The underside of the board rendered in full.*

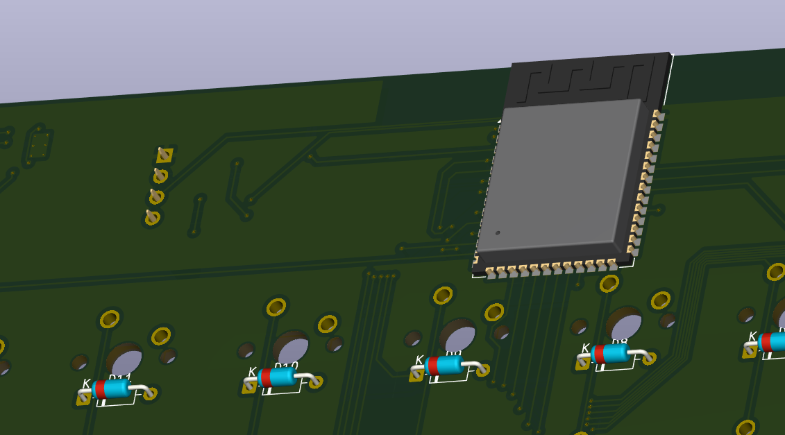
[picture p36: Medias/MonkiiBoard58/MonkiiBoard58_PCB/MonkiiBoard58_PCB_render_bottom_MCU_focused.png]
The bottom face with the ESP32 S3 module in focus


*The underside zoomed toward the ESP32 S3 module.*

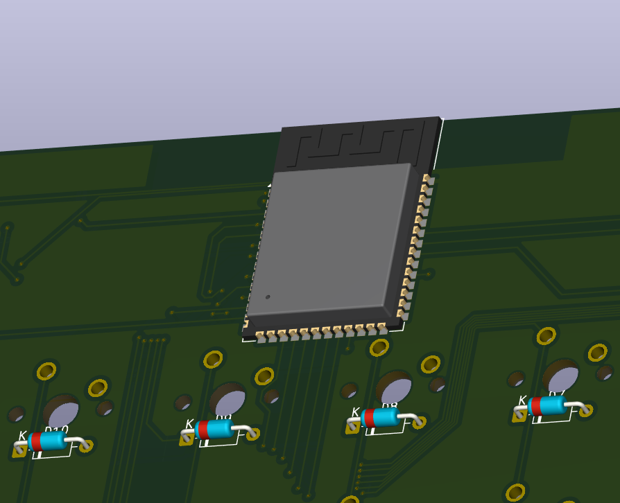
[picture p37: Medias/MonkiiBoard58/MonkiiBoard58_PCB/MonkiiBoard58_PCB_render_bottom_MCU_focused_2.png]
A second angle on the bottom face, still focused on the ESP32 S3 module


*A second angle on the same area, still centered on the ESP32 S3 module.*

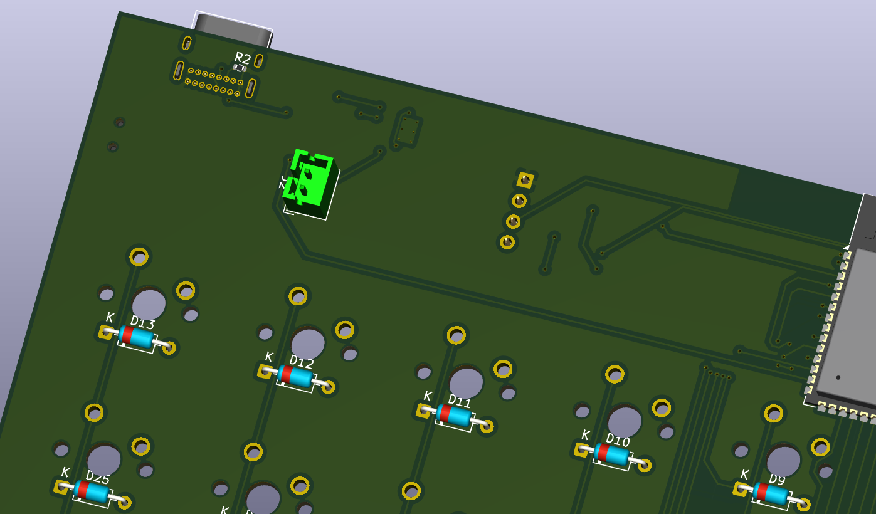
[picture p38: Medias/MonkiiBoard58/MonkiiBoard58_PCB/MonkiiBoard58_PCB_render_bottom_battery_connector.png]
The bottom face with the battery connector area highlighted in green, this is where the LiPo plugs in


*The underside with the battery connector area highlighted in green, this is where the LiPo plugs in.*

## The power system

This is the part that sets MonkiiBoard58 apart from the rest of the family. USB C brings in five volts, the TP4056 uses that to charge the LiPo battery, and everything downstream of the power switch runs off the AMS1117 regulator at a steady 3.3 volts.

| Stage | Part | Job |
| --- | --- | --- |
| Charging | TP4056 | Charges the LiPo off USB C, current set by a 1.2 kilo ohm PROG resistor, up to one amp |
| Regulation | AMS1117 3.3 | Takes the battery voltage and holds a steady 3.3 volt rail for everything else |
| OLED gating | AO3401A | P channel MOSFET that cuts power to the OLED completely when the ESP32 S3 pulls the gate high |

The OLED gate is the part I am proudest of. Instead of just dimming the screen in software, the ESP32 S3 can cut its power rail entirely after thirty seconds of no key presses, so there is zero standby draw from the display while the board sits idle.

## The switches

All fifty eight switches get their own 1N4148 diode, cathode facing the row line, the same anti ghosting setup you would find on a wired board. This is the only board in the family besides MonkiiPad20 that uses diodes, and the only one running a full five by twelve matrix worth of them.

## The pinout

| Function | ESP32 S3 GPIO |
| --- | --- |
| Row 0 | GPIO4 |
| Row 1 | GPIO5 |
| Row 2 | GPIO6 |
| Row 3 | GPIO7 |
| Row 4 | GPIO8 |
| Col 0 | GPIO9 |
| Col 1 | GPIO10 |
| Col 2 | GPIO11 |
| Col 3 | GPIO12 |
| Col 4 | GPIO13 |
| Col 5 | GPIO14 |
| Col 6 | GPIO15 |
| Col 7 | GPIO16 |
| Col 8 | GPIO17 |
| Col 9 | GPIO18 |
| Col 10 | GPIO21 |
| Col 11 | GPIO38 |
| OLED SDA | GPIO1 |
| OLED SCL | GPIO2 |
| OLED power gate | GPIO39 |
| Encoder A | GPIO40 |
| Encoder B | GPIO41 |
| Encoder switch | GPIO42 |

## The controller

As you've noticed, there's an ESP32 S3 WROOM 1 N16R8 module sits at the top center of the board, antenna facing out toward the edge with a keep out zone underneath it so nothing on any layer sits under or around the antenna. The S3 has a native USB PHY, so the USB C lines wire straight into it with no separate USB to serial chip needed, and it talks Bluetooth 5 for the wireless side once the firmware is flashed.

## What the board is

| Spec | Value |
| --- | --- |
| Layers | 2 |
| Thickness | 1.6 mm |
| Size | 235.45 by 122.95 mm |
| Finish | None |

## Where things stand right now

The schematic, layout and 3D render are all done, but I have not sent the boards off to a manufacturer yet, so nothing shown above has actually been built or tested on real hardware. Once boards land, firmware and a case are next. Full design story, the gerbers to get one made and the raw KiCad project all live in the [PCB folder](PCB/).

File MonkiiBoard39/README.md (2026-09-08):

# MonkiiBoard39

The full keyboard of the family. Thirty nine keys packed into a tidy ortholinear 40 percent layout, running on a Pro Micro style ATmega32U4 board. It shows up to your computer as an ordinary USB keyboard, so there are no drivers to chase and nothing to set up on the host side.

The MonkiiBoard39 seen from an angle, black keycaps on a white plate

## How it is wired

The switches sit in a grid of four rows and ten columns. The rows go to pins A3, A2, A1 and A0, and the columns go to pins 9, 8, 7, 6, 5, 4, 10, 16, 14 and 15. The firmware pulls one row low at a time and reads the columns through their internal pull up resistors, so a pressed key drags its column low and the scanner knows exactly which switch moved. There is a thirty millisecond debounce on every key so a single press only ever registers once.

This board runs without diodes. That keeps the build cheap and simple, and it is perfectly happy for everyday typing where you are hitting one or two keys at a time. Press a bunch of keys at once that happen to line up in the grid and you can get the usual ghosting any diodeless board has, so it is not the board for mashing five keys together.

## Two ways to build it

You can hand wire the whole thing to the pins listed above, same as I did with the very first one, or you can order the PCB I designed for it and solder onto that instead. Both run the same firmware and land on the exact same pins, no diodes either way.

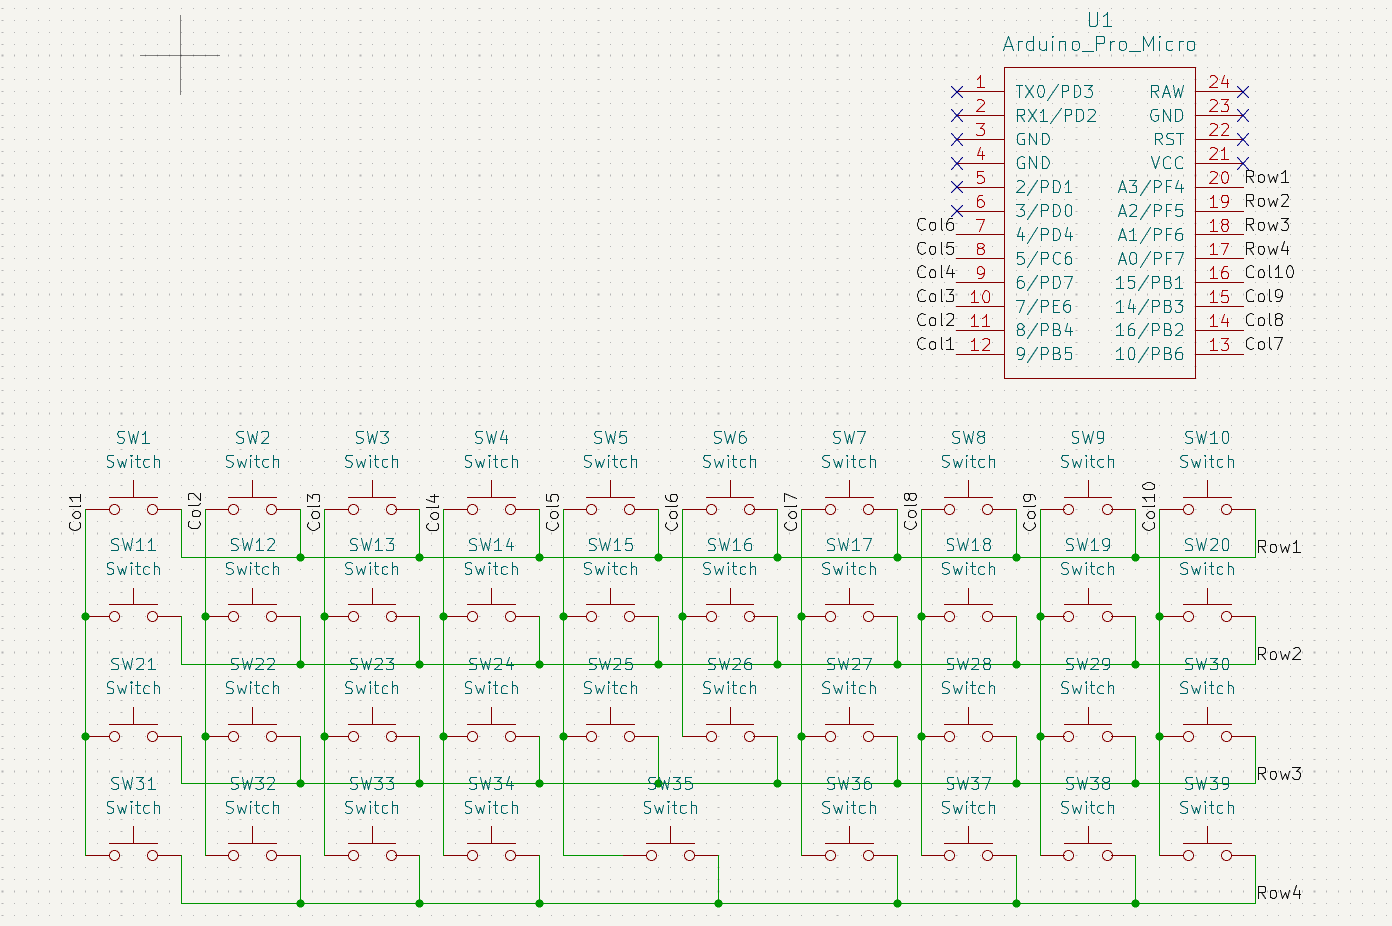
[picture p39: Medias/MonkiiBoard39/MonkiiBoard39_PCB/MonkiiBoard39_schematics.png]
The schematic for the MonkiiBoard39, thirty nine switches wired into a four by ten matrix with no diodes, plus the Arduino Pro Micro pinout


The full story of how that board came together, along with the files to get one made, lives in the [PCB folder](PCB/).

## The layout

Top down view of the MonkiiBoard39 showing the full key layout

The three upper rows carry a familiar qwerty arrangement. The top row runs q across to p, the home row runs a across to l and finishes with backspace, and the lower letter row runs z through the comma and the period and finishes with enter.

The bottom row is where the fun is, and the firmware handles it by hand instead of pulling from the keymap table.

## Sticky modifiers

Control, shift and alt live on the first three keys of the bottom row, and they work as sticky modifiers. Tap one and it arms itself quietly, then the next key you press comes through with that modifier held, and the moment you let that key go the modifier clears itself again. So you can fire something like control and c without ever holding two keys down at the same time, which sits nicely with the diodeless matrix.

## The double tap Windows key

The fourth key on the bottom row is the Windows key, and it carries a little extra smarts. A single tap arms it as a sticky modifier just like the others, so you can build combos such as Windows and d. Tap it twice quickly, inside about a third of a second, and it fires the Windows key on its own to pop the start menu open.

## The spacebar

The space stretches across the middle of the bottom row as a wide 2u key. It is wired to two columns, five and six, so it registers a space no matter which side of the bar you happen to press.

## The case

Side profile of the MonkiiBoard39 showing the plate and standoffs

The case folder holds the print ready plates for this board, a top plate that the switches clip into and a bottom plate that closes everything up. Drop them into your slicer as they are, no modelling needed. They come out nicely in PLA or PETG at around 0.2 millimeter layers with a few walls for a bit of stiffness.

## Flashing it

Open the sketch in the Arduino IDE, pick the Arduino Leonardo or SparkFun Pro Micro board and hit upload. It only needs the Keyboard library that already ships with the IDE, so there is nothing extra to install.

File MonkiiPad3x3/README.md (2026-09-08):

# MonkiiPad3x3

The smallest board in the family, a nine key pad in a simple three by three grid. It is a Pro Micro style board that turns up as an ordinary keyboard, and despite its size it hides a whole second personality behind a long press.

Top down view of the MonkiiPad3x3, nine black keycaps numbered one to nine in a pink printed case

## How it is wired

Nine switches sit in a grid of three rows and three columns. The rows go to pins 2, 3 and 4, and the columns go to pins 5, 6 and 7. Like the MonkiiBoard39 it runs without diodes, so it is built for tapping one key at a time rather than holding a fistful of them down together, which suits a little number pad just fine.

Inside the MonkiiPad3x3 showing the switches and hand wiring

## Two ways to build it

You can hand wire it to the pins above like the original, or order the PCB I designed and solder onto that instead. Same firmware, same pins, no diodes either way.

The schematic for the MonkiiPad3x3, nine switches wired into a three by three matrix with no diodes, plus the Arduino Pro Micro pinout

The design story and the files to get one made live in the [PCB folder](PCB/).

## Two pads in one

Fresh out of the box the pad is a number pad. The nine keys send 1 through 9 laid out exactly how you would picture them, top left down to bottom right.

The top left key is the one to watch. A quick tap sends a 1 like any other key. Hold it down for a second and a half though, and the pad flips into macro mode, and holding it again flips you straight back. It is a neat way to pack twice the function into nine keys without adding a single extra button.

## Macro mode

Once you are in macro mode the layout turns into an editing and navigation cluster. The four keys around the middle become arrow keys, laid out as a cross, with up on the top key and left, down and right across the middle row.

The bottom row becomes editing commands. The bottom left key fires undo, the middle one fires redo, and the bottom right sends delete.

One quick heads up if you go reading the code. The little comments next to those two bottom keys say copy and paste, but what the keys actually send is undo, as control and z, and redo, as control and y. The behavior is the undo and redo pair, the comments just did not keep up with the code.

## The case

Side view of the MonkiiPad3x3 printed case

The case folder holds the print ready plates for the pad, filed under the VOID9 name. There are a few flavours to pick from. The top comes in a plain flat version and a softer filleted version, and the bottom comes flat or gently angled if you like the pad to sit on a slight tilt. Print whichever top and bottom pair you fancy, then clip the switches into place.

## Flashing it

Open the sketch in the Arduino IDE, choose the Arduino Leonardo or SparkFun Pro Micro board and upload. It only uses the built in Keyboard library, so there is nothing else to install.

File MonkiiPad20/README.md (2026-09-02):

# MonkiiPad20

Hi ! This is a twenty key macropad with a bit of personality. It has an OLED screen, two switchable layers and a pair of animated robot eyes that wake up and look around when you step away. This is also the one board in the family that runs a diode under every switch, which gives it a clean matrix and lets you press keys together without any ghosting.

The MonkiiPad20 in a dark room with its robot eyes glowing blue on the OLED

## The hardware

This pad runs on a Waveshare RP2040-Zero. The reason for that choice is the screen, since the code drives the OLED over the second I2C bus and that dual bus setup is an RP2040 feature. The board is small enough to tuck away neatly, which helps in a build this size.

The switches form a matrix of four rows and six columns, with the rows on pins 0, 1, 2 and 3 and the columns on pins 4, 10, 6, 7, 8 and 9. Twenty of those matrix spots carry keys and the leftover spots stay empty. Every switch has its own diode, so the board reads presses cleanly and handles proper rollover when several keys go down together. Each key is debounced over twenty milliseconds so presses stay crisp.

The display is a 128 by 64 SSD1306 wired to the second I2C bus, with data on pin 14 and clock on pin 15.

## Two ways to build it

There are two roads to a finished MonkiiPad20, and neither one is more correct than the other. You can hand wire the whole thing, or you can order the PCB I designed and solder onto that. Same firmware, same layout, same result. Pick whichever suits your patience and your parts drawer.

### Hand wiring

The scrappy way, and the one I built first. Everything gets soldered point to point, with a diode bridged straight across the legs of each switch and thin wire tying the rows and columns together. The RP2040 and the OLED just get wired in and tucked at the top. It costs almost nothing and you can start tonight, but it is fiddly and the back is a bit of a jungle by the end, so take your time and keep every diode facing the same way.

Inside the hand wired MonkiiPad20 with a diode soldered across each switch and the RP2040 and OLED tucked at the top

The back of the hand wired build with the row and column wires running between the switches

### The PCB

The tidy way. I laid out a board with a labelled spot for every switch, a diode footprint beside each one and a marked header for the controller and the screen, so there is no loose wire to trace and no guesswork about which pin goes where. You do have to wait for it to ship, but soldering it up is quick and the finished board is far cleaner. The files and full instructions live in the [PCB folder](PCB/), and if you just want to get one made, grab the `MonkiiPad20_PCB.zip` in there and hand that to a fab house as is.

The MonkiiPad20 PCB on a cutting mat with every switch pad labelled and the controller pin header down the side

The back of the PCB showing the diode footprints, each marked with a K for the cathode, and the controller pin map in the corner

And here is that same board fully populated, switches, diodes and the RP2040-Zero all soldered in! Again, more build photos and the full write up are in the [PCB folder](PCB/).

The MonkiiPad20 PCB fully assembled, every switch socketed and the RP2040-Zero soldered onto its header

Before any of that got routed, it started life as a schematic, twenty switches each with their own diode wired into the matrix, along with the OLED header and the RP2040-Zero pinout. The [PCB folder](PCB/) has the full story of how it got from there to a finished board.

The KiCad schematic for the MonkiiPad20, twenty switches each with a diode wired into a 4x6 matrix, plus the OLED header and the RP2040-Zero pinout

## Two layers

Top down view of the MonkiiPad20 and its keys

The pad boots into a layer called Shortcuter, which is tuned for firing off shortcuts and macros, and you can flip over to a second layer called Typist that types everything straight through. Both layers keep the FN key and the control key in the same spot, so your muscle memory carries over when you switch.

Switching is done with the FN key. Hold it for one full second and the board swaps layers, lets go of anything it was holding so nothing gets stuck down, and refreshes the screen straight away. The FN key sits at row 2 column 5 and the control key sits at row 3 column 5.

## The screen

While you are using the pad the OLED keeps you in the loop. Across the top it prints MONKIIBOARD, in the middle it shows which layer you are on in big letters, either Shortcuter or Typist, and along the bottom it shows the last key you pressed so you always get a little feedback.

## The robot eyes

Leave the pad alone for five seconds and the screen turns into a pair of rounded robot eyes. The pupils glide left and right, and every so often the eyes give a blink, all animated smoothly at around thirty frames a second. Touch any key and the eyes vanish. That first press only wakes the screen back up rather than typing anything, and you are right back on the layer display.

## The special keys

A handful of keys do more than send a letter. The DEL key sends a backspace, the CTRL key holds left control, and the FN key runs the layer switching described above. Everything else on the Shortcuter layer is yours to map to whatever shortcuts you reach for the most.

## What you need to build it

The firmware leans on a few libraries beyond the standard Keyboard one. You will want the Adafruit GFX library and the Adafruit SSD1306 library for the display, plus the Wire library for I2C, and all three install straight from the Arduino library manager. If your editor flags those includes as missing before you install them, that is just the editor and not the code. Flash the sketch with an RP2040 board core selected and you are away.

## The case

The case folder holds the print ready plates for the pad, a top plate and a bottom plate. Slice and print them as they are. Take your time seating the board so the screen lines up cleanly behind the top plate before you close it up.

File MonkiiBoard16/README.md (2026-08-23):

# MonkiiPad16

A sixteen key macropad with a rotary encoder and a little OLED screen. It boots as a plain number pad, and when you want something different you spin the knob to pick another layer. Right now there are two layers, a numpad and a page of editing shortcuts, with room to grow.

The MonkiiPad16 at an angle showing its sixteen keys, the encoder knob and the OLED screen

## The hardware

This pad runs on an RP2040 board, the same Waveshare RP2040-Zero style controller as the MonkiiPad20, and like that board it drives the OLED over the second I2C bus, which is an RP2040 feature.

The keys sit in a four by four matrix, with the rows on pins 4, 5, 6 and 7 and the columns on pins 0, 1, 2 and 3. Every key is debounced over twenty milliseconds so presses stay clean. The rotary encoder uses pins 10 and 11 for the two rotation signals and pin 8 for its push button. The screen is a 128 by 64 SSD1306 on the second I2C bus, with data on pin 14 and clock on pin 15.

Close up on the rotary encoder knob, the OLED glowing just behind it

## The two layers

The pad starts on the numpad layer. It is a normal number pad, digits zero through nine, a decimal point, the four maths symbols and an enter key, so you can punch in figures without reaching across your main keyboard.

Spin the encoder or press it in and a menu appears on the screen listing the layers, with the one you are on marked by a star and your current pick highlighted. Keep turning to move the highlight, then press the knob to jump to that layer. If you change your mind, just leave it alone and the menu closes itself after three seconds.

Turning the encoder to bring up the layer menu, NUMPAD starred as the active layer with SHORTCUTS waiting below it

The second layer is a set of editing shortcuts, the ones you reach for all day. Undo and redo, copy and paste, save, find and select all, bold, italic and underline, comment a line, duplicate a line, and indent left or right. Each one fires the matching key combination for you, so a single tap does the work of a chord.

Close look at the MonkiiPad16 keys and the rotary encoder

## The screen

While you are working the OLED keeps you posted. Across the top it shows the layer you are on, and filling the rest of the screen in big letters it shows the last key you pressed, either the digit itself on the numpad or a short label like COPY or SAVE on the shortcuts layer. When the layer menu is open the screen switches over to that instead.

The OLED reading LAYER: SHORTCUTS and LAST KEY: UNDO after a tap on the shortcuts layer

## What you need to build it

The firmware uses a few libraries on top of the standard Keyboard one. You will want the Adafruit GFX library and the Adafruit SSD1306 library for the display, plus the Wire library for I2C, and all of them install straight from the Arduino library manager. If your editor marks those includes as missing before you install them, that is just the editor and not the code. Flash the sketch with an RP2040 board core selected and you are set.

## The case

The case folder holds the print ready plates, a top plate and a bottom plate. Slice and print them as they are. Take your time seating the board and the encoder so everything lines up behind the top plate before you close it up.

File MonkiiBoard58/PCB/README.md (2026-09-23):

# MonkiiBoard58 PCB

MonkiiBoard58 is the first board in the family that only exists as a PCB. There is no hand wired version of this one. Fifty eight switches, a rotary encoder and an OLED screen all packed onto one board, running wireless off a LiPo battery instead of a USB cable to the host.

The MonkiiBoard58 PCB rendered in KiCad from the top, full ortholinear grid with the OLED cut out in the middle and the encoder in the corner

## The layout

Fifty eight keys sit in a five row by twelve column ortholinear grid, sixty switch positions in total with two given up in the middle for the OLED window. An EC11 rotary encoder lives on the left side and a USB C receptacle sits in the top right corner for charging.

The full keyboard layout, showing every switch position across the five by twelve grid with the OLED gap and the encoder marked

## How I designed it

I drew the matrix first, fifty eight switches each with their own 1N4148 diode, then moved on to the ESP32 S3 module, the OLED header, the encoder and the whole power section afterward.

The full schematic, every switch, diode, the ESP32 S3, the OLED header, the encoder and the power circuitry all in one sheet

One switch and its diode zoomed in, cathode facing the row line the way the rest of the matrix is wired

Just the switch and diode matrix on its own sheet, fifty eight of them across five rows and twelve columns

The ESP32 S3 WROOM 1 module schematic with its decoupling caps and the antenna keep out area marked

The USB C receptacle and OLED header schematic, CC1 and CC2 each with their own pull down and the OLED on its four pin header

The power side got its own sheet since there was too much going on to squeeze in next to the matrix. Battery connector, power switch, the AMS1117 regulator and its capacitors all sit together here.

The battery connector, slide power switch, AMS1117 LDO and its bypass capacitors

The AO3401A power gate MOSFET, the EC11 encoder and the TP4056 charge circuit sharing one sheet

## Laying it out

The first pass at routing did not have a single mounting hole anywhere on the board, which would have left no way to actually screw it into a case later. Version two added four of them, one in each corner.

The routed PCB with GND fill turned on, no mounting holes yet in this version

The same layout with four mounting holes added in the corners

A closer look at the top center of the board where the ESP32 S3 module sits

The top right corner of the board around the USB C receptacle

## Placing and wiring the parts

Before anything got soldered I laid every part out on the bench to check the footprints against the real components first.

Every component laid out before wiring and placing them onto the board

The ESP32 S3 WROOM 1 module itself, the SMD part that runs the whole board

The USB C receptacle before it gets wired in

The top left corner wired up around the EC11 rotary encoder

The top center area wired up with the ESP32 S3 footprint in focus

## The power system

This is the part that sets MonkiiBoard58 apart from the rest of the family. USB C brings in five volts, the TP4056 uses that to charge the LiPo battery, and everything downstream of the power switch runs off the AMS1117 regulator at a steady 3.3 volts.

| Stage | Part | Job |
| --- | --- | --- |
| Charging | TP4056 | Charges the LiPo off USB C, current set by a 1.2 kilo ohm PROG resistor, up to one amp |
| Regulation | AMS1117 3.3 | Takes the battery voltage and holds a steady 3.3 volt rail for everything else |
| OLED gating | AO3401A | P channel MOSFET that cuts power to the OLED completely when the ESP32 S3 pulls the gate high |

The OLED gate is the part I am proudest of. Instead of just dimming the screen in software, the ESP32 S3 can cut its power rail entirely after thirty seconds of no key presses, so there is zero standby draw from the display while the board sits idle.

## The switches

All fifty eight switches sit in a five row by twelve column matrix, and unlike MonkiiBoard39 or MonkiiPad3x3 this one does use a diode per switch, a 1N4148 with the cathode facing the row line. With sixty positions on a wireless board meant for real typing, full rollover mattered enough to spend the extra part on every switch.

## The pinout

| Function | ESP32 S3 GPIO |
| --- | --- |
| Row 0 | GPIO4 |
| Row 1 | GPIO5 |
| Row 2 | GPIO6 |
| Row 3 | GPIO7 |
| Row 4 | GPIO8 |
| Col 0 | GPIO9 |
| Col 1 | GPIO10 |
| Col 2 | GPIO11 |
| Col 3 | GPIO12 |
| Col 4 | GPIO13 |
| Col 5 | GPIO14 |
| Col 6 | GPIO15 |
| Col 7 | GPIO16 |
| Col 8 | GPIO17 |
| Col 9 | GPIO18 |
| Col 10 | GPIO21 |
| Col 11 | GPIO38 |
| OLED SDA | GPIO1 |
| OLED SCL | GPIO2 |
| OLED power gate | GPIO39 |
| Encoder A | GPIO40 |
| Encoder B | GPIO41 |
| Encoder switch | GPIO42 |

## The controller

An ESP32 S3 WROOM 1 N16R8 sits at the top center of the board, antenna facing out toward the edge with a keep out zone underneath it so nothing on any layer sits under or around the antenna. The S3 has a native USB PHY, so the USB C lines wire straight into it with no separate USB to serial chip needed, and it talks Bluetooth 5 for the wireless side once the firmware is flashed.

## What the board is

| Spec | Value |
| --- | --- |
| Layers | 2 |
| Thickness | 1.6 mm |
| Size | 235.45 by 122.95 mm |
| Finish | None |

## Downloading the files

`MonkiiBoard58_PCB.zip` in this folder has the copper, mask, paste and silkscreen layers for both sides along with the edge cuts and the job file. There is no drill file in there yet, so pull that from the KiCad project in `KiCad_files` and add it before sending this off to a fab house.

## Tuning your own PCB

If you want to design or tune your own version of this board, the raw KiCad project sits in `KiCad_files` right next to the gerbers. Download those three files, open the `.kicad_pro` in KiCad, and you get the schematic and the board exactly as I left them. Edit the schematic, move footprints, reroute traces, whatever your build actually needs, then export your own gerbers when you are happy with it.

## Where things stand right now

This one is still ahead of the rest of the pack in age but behind everyone else in progress. The schematic and layout are done and the gerbers are ready, but I have not sent the boards off to a manufacturer yet, so nothing has actually been built or tested on real hardware. Firmware and a case are next once boards are in hand. Like every other board here it is fully open source, so the KiCad project and every file in this folder are free to build, copy or change however you like.

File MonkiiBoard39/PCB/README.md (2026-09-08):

# MonkiiBoard39 PCB

This is the circuit board I designed for the MonkiiBoard39. It takes the whole thirty nine key matrix off a nest of loose wire and puts it on one board with a socket for the Pro Micro sitting right in the middle of the layout.

The MonkiiBoard39 PCB rendered in KiCad, thirty nine switch footprints laid out four rows by ten columns with the Pro Micro footprint sitting between rows one and two

## How I designed it

I started from a schematic with all thirty nine switches wired straight into a four by ten matrix, no diodes anywhere, just rows and columns running into the Pro Micro.

The schematic for the MonkiiBoard39, thirty nine switches wired into a four by ten matrix with no diodes, plus the Arduino Pro Micro pinout

My first attempt at placing the Pro Micro sat it too deep in the middle of the board, which crowded the traces around it and caused a pile of routing problems.

An early layout of the MonkiiBoard39 PCB where the Pro Micro footprint sits too deep among the switches, causing routing problems

Moving it up a little and giving it more room cleared that right up.

The fixed MonkiiBoard39 PCB layout with the Pro Micro moved and every trace routed with no violations

Here is the same layout with the copper fill turned off, which makes it easier to see exactly which switch connects to which row and column.

The MonkiiBoard39 PCB layout with the copper pour hidden, showing the bare row and column traces between switches

By the end the design rule checker came back with zero errors and only silkscreen warnings left, which just means a few text labels overlap slightly and nothing electrical is wrong.

KiCad's design rule checker showing zero errors and forty three warnings, all of them silkscreen related

The back of the finished MonkiiBoard39 PCB with the Pro Micro footprint and its traces running out to every column

## Downloading the files

The zip in this folder has the copper layers, the silkscreen and the job file, but I have not exported the drill file yet, so pull that from the KiCad project in `KiCad_files` before you send this off to be made. Most fab houses want the drill data included alongside the gerbers, so add it to the zip or upload it as a separate file depending on what your fab asks for.

## What the board is

| Spec | Value |
| --- | --- |
| Layers | 2 |
| Thickness | 1.6 mm |
| Size | 195 by 80 mm |
| Finish | None |

Nothing unusual about the stack, so any regular fab house will take it.

## The switches

All thirty nine switches sit in a four row by ten column matrix and there is no diode anywhere on this board. I designed it that way on purpose. The firmware never asks for true rollover here since the sticky modifiers work by tapping one key and then hitting the next one after, rather than holding several keys down together, so skipping the diodes never gets in the way of a combo. You still get your control, shift, alt and the double tap windows key, they just arrive one key at a time instead of all at once.

## The pinout

Here is exactly how the matrix is wired, in case you want to check it against your own build or reroute something later.

| Signal | Pin |
| --- | --- |
| Row1 | A3 |
| Row2 | A2 |
| Row3 | A1 |
| Row4 | A0 |
| Col1 | 9 |
| Col2 | 8 |
| Col3 | 7 |
| Col4 | 6 |
| Col5 | 5 |
| Col6 | 4 |
| Col7 | 10 |
| Col8 | 16 |
| Col9 | 14 |
| Col10 | 15 |

## The controller

The Pro Micro sits in the middle of the board with its own silkscreen pin labels printed right underneath it, so you can check the columns and rows line up before you solder it down.

The back of the MonkiiBoard39 PCB with the actual Pro Micro module seated on its footprint

## Tuning your own PCB

If you want to design or tune your own version of this board, the raw KiCad project sits in `KiCad_files` right next to the gerbers. Download those three files, open the `.kicad_pro` in KiCad, and you get the schematic and the board exactly as I left them. Edit the schematic, move footprints, reroute traces, whatever your build actually needs, then export your own gerbers when you are happy with it.

## Getting it made

Send the gerbers and the drill file to whichever fab you like, two layers and 1.6 mm as above. When the boards land there are no diodes to worry about, so it is just the switches and the Pro Micro, then you are ready to flash the firmware and drop it into the case.

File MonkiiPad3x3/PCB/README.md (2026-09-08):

# MonkiiPad3x3 PCB

This is the circuit board I designed for the MonkiiPad3x3. It fits all nine switches and a Pro Micro onto one small board instead of the tangle of wire the original hand wired version needed.

The MonkiiPad3x3 PCB rendered in KiCad, nine switch footprints around a Pro Micro footprint in the middle of the board

## How I designed it

I drew up a schematic with the nine switches wired straight into a three by three matrix, no diodes, running into the Pro Micro.

The schematic for the MonkiiPad3x3, nine switches wired into a three by three matrix with no diodes, plus the Arduino Pro Micro pinout

From there I laid the switches out around the Pro Micro and routed the rows and columns between them.

The routed MonkiiPad3x3 PCB layout in the KiCad editor, showing the row and column traces running between the nine switches

Here is the same board with the Pro Micro actually seated on its footprint, USB port and all.

The back of the MonkiiPad3x3 PCB with the Pro Micro module seated in the middle, its USB port poking out over the edge

## The switches

All nine switches sit in a three row by three column matrix and there is no diode on this board either. I designed it that way on purpose, same as the MonkiiBoard39. Holding the first key still flips the pad between the plain number pad and the arrow and editing macros, and since that switch is only ever pressed on its own to trigger the toggle, there is nothing here that ever needed true rollover in the first place.

## The pinout

| Signal | Pin |
| --- | --- |
| Row1 | 2 |
| Row2 | 3 |
| Row3 | 4 |
| Col1 | 5 |
| Col2 | 6 |
| Col3 | 7 |

## The controller

The Pro Micro sits right in the middle of the board, taking up roughly the space of two switch footprints, with its USB port lined up against the edge so it stays reachable once the board is in a case.

## Downloading the files

Grab `MonkiiPad3x3_PCB.zip` if you just want this board made. It holds the copper, mask, paste and silkscreen layers for both sides plus the edge cuts and the job file, but I have not exported a drill file for it yet, so pull that from the KiCad project in `KiCad_files` and add it in before you send this off to a fab house.

## What the board is

| Spec | Value |
| --- | --- |
| Layers | 2 |
| Thickness | 1.6 mm |
| Size | 57 by 57 mm |
| Finish | None |

Small enough that shipping costs more than the board itself most of the time.

## Tuning your own PCB

If you want to design or tune your own version of this board, the raw KiCad project sits in `KiCad_files` right next to the gerbers. Download those three files, open the `.kicad_pro` in KiCad, and you get the schematic and the board exactly how we left them. Edit the schematic, move footprints, reroute traces, whatever your build actually needs, then export your own gerbers when you are happy with it.

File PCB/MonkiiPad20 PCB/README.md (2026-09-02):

# MonkiiPad20 PCB

This is the circuit board I designed for the MonkiiPad20. It turns the pile of switches, diodes and a controller into one tidy piece instead of a nest of hand wiring. Twenty switch spots, a diode under each one, an RP2040 footprint in the corner and a little header for the OLED, all on a two layer board.

The finished MonkiiPad20 board on a cutting mat, switch pads labelled SW1 through SW20 with the RP2040 pin header down the right side

## How I designed it

I started with the components themselves, dropping down footprints for the switches before anything was wired up.

Early 3D render of the board with just the switch footprints placed, nothing routed yet

Another early pass, with the OLED header added in but the diodes and the controller still to come.

Another early render of the board with the OLED header footprint added but no diodes or controller placed yet

From there I looked back at how I'd hand wired the original MonkiiPad20 and turned that into a proper schematic, the full matrix with a diode on every switch, the OLED header and the RP2040-Zero pinout all laid out.

The KiCad schematic for the MonkiiPad20, twenty switches each with a diode wired into a 4x6 matrix, plus the OLED header and the RP2040-Zero pinout

A good stretch of PCB designing followed, placing the diodes and the controller and figuring out where everything could actually sit.

3D render with the diodes placed on the back of the board and the RP2040-Zero footprint dropped in, USB-C and all

Checking the RP2040-Zero footprint up close against the board edge and a mounting hole

That period of designing is what led to design 2, the first version with every trace actually routed end to end.

Design 2, the PCB editor view with every trace routed between the switches, diodes and the controller header

Design 5 is the one that actually became this board, a second pass over design 2 with a handful of routing tweaks to clear up bugs and errors before sending it off to be made.

Design 5, the routing cleaned up from design 2 to fix a handful of bugs before this went off to be made

## Downloading the files

If you just want to get this board made, **grab `MonkiiPad20_PCB.zip`**. That one zip holds everything a fab house needs, all the Gerber layers plus the two drill files, and most manufacturers want it handed over exactly like that, as a single archive. Drop the zip into their site, pick your options and you are done.

The loose `.gbr` and `.drl` files sitting next to the zip are the same data unpacked. They are there if you want to peek at a layer or load it into a Gerber viewer, but for ordering you only need the zip.

## What the board is

It came out of KiCad as a two layer board, 120 by 86 millimetres, 1.6 mm thick, with green soldermask. Nothing exotic in there, so any of the usual cheap fab houses will run it without complaint.

The back of the board showing the diode footprints, each marked with a K for the cathode, and the RP2040 pin map in the corner

## The switches and diodes

The twenty switch positions are laid out four rows by six columns and numbered SW1 through SW20 on the silkscreen, so you always know which one you are looking at. Every switch gets its own diode, and the footprint sits right beside it with the cathode end marked K. That little mark matters, since diodes only go one way, so line the band on the diode up with the K and you will not have to desolder anything later. The diodes are what give the pad its clean matrix and let you mash several keys at once without ghosting.

A close angle across the board with the diode outlines and the row and column traces running between the switches

## The controller

Up in the corner is the footprint for the Waveshare RP2040-Zero. I printed the pin names right onto the silkscreen, the power pins down one side as 5V, GND and 3V3, and the GPIO numbers running around the rest, so you can seat the controller and check your wiring against the board itself instead of digging out a pinout. There is also a small header broken out for the OLED so the screen has a clean place to land.

The controller footprint up close with the pin labels reading 5V, GND, 3V3 and the numbered GPIO pins printed on the board

## Getting it made

Send the zip to whichever fab you like, the defaults are fine, two layers and 1.6 mm as above. When the boards land, solder the diodes first while the board is still flat and easy to work on, watching that K mark, then the switches, then the controller and the OLED header. After that you are ready to flash the firmware and drop it into the case.

The board catching the light at an angle with the MonkiiBoard logo printed on the silkscreen

## What it looks like built

Here is one I actually populated, every switch socketed and the OLED window sitting flush in the corner.

The assembled MonkiiPad20 PCB with every switch socket filled and the OLED window mounted at the top right

A closer look at the diodes once they are actually soldered down instead of just sitting as a footprint. Every one bent flat and facing the same way, matching the K printed beside it.

Close up on a row of soldered diodes on the back of the assembled board, each one seated flat and facing the same direction

The RP2040-Zero seated on its header, its own silkscreened pin labels lining up right against the ones printed on the board underneath.

The RP2040-Zero controller soldered onto the board, its own pin labels matching the ones printed on the board's silkscreen

And the whole back once everything is in, controller and every diode soldered.

The back of the fully assembled board with the RP2040-Zero and every diode soldered in place

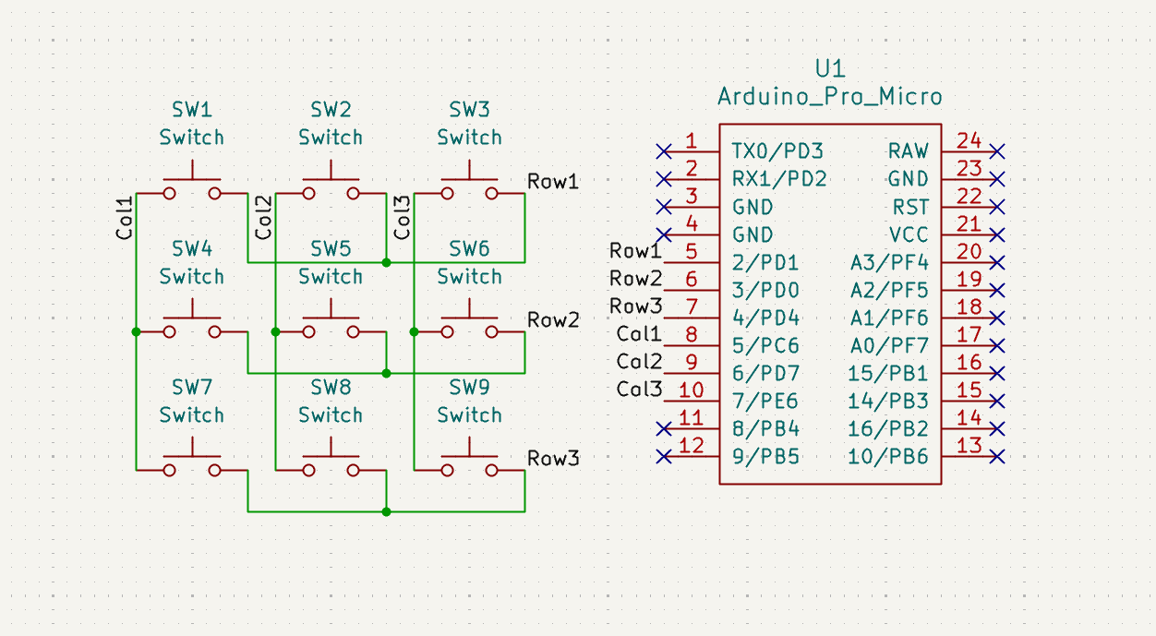
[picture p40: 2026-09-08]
Medias/MonkiiPad3x3/MonkiiPad3x3_PCB/MonkiiPad3x3_PCB_schematics.png

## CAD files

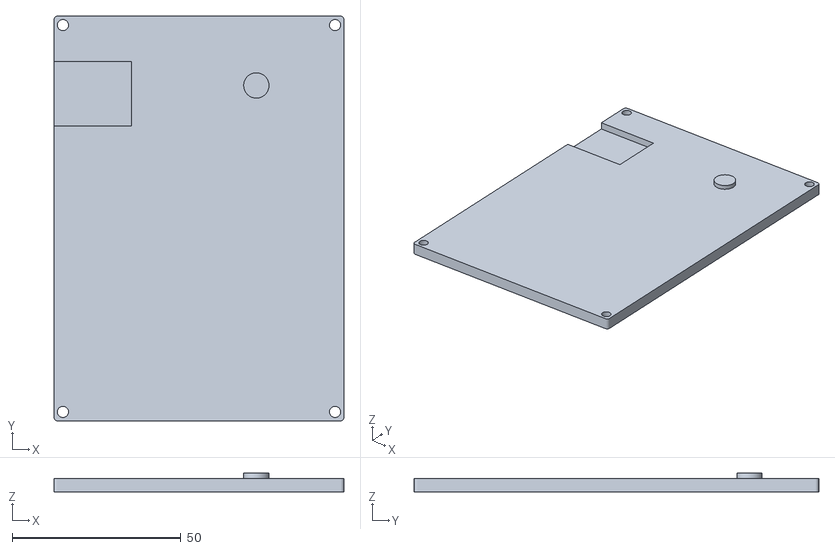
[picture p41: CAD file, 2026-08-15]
MonkiiBoard16/case/MonkiiPad16_bottom_plate.stl
86.0 x 120.0 x 5.50

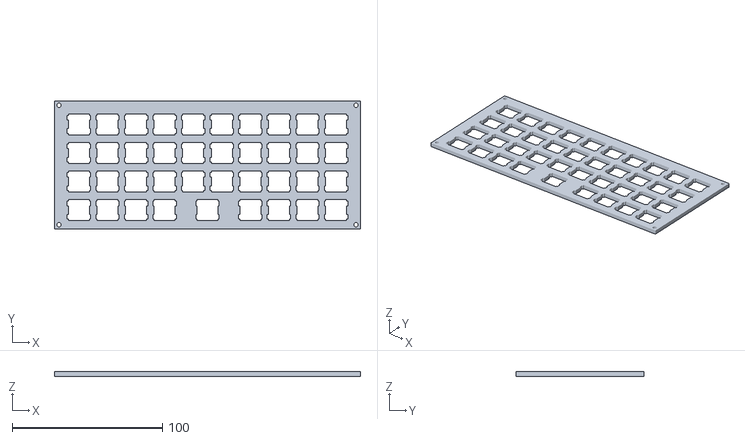
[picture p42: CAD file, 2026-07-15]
MonkiiBoard39/case/4x10_top_plate.stl
204.0 x 85.6 x 3.00

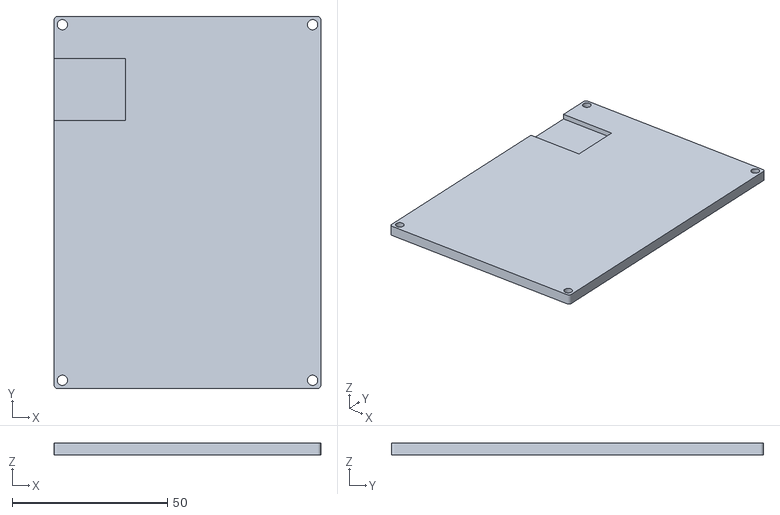
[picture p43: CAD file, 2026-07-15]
MonkiiPad20/case/MonkiiPad20_bottom_plate.stl
86.0 x 120.0 x 4.00

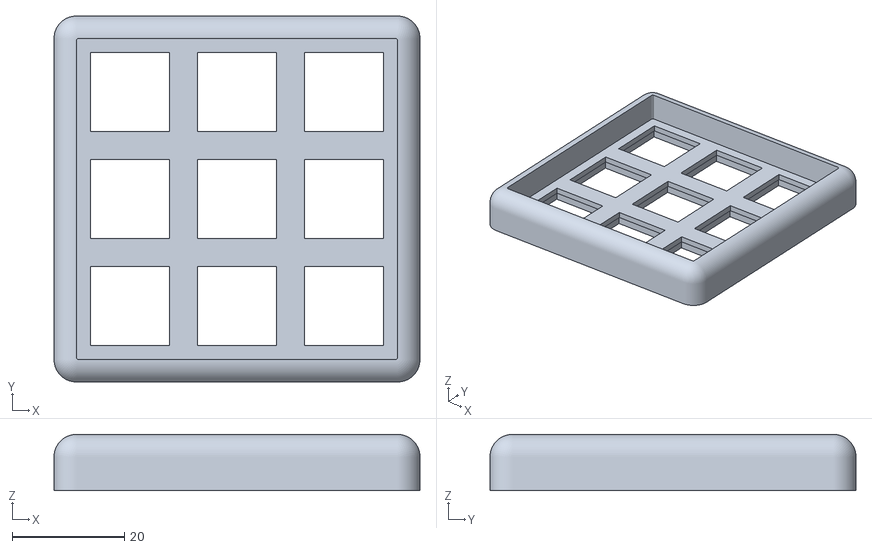
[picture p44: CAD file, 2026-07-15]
MonkiiPad3x3/case/VOID9_-_Top_-_Fillet.stl
65.2 x 65.1 x 10.0

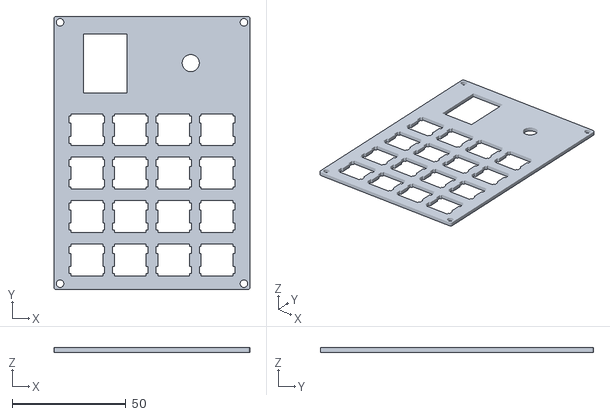
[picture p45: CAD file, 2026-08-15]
MonkiiBoard16/case/MonkiiPad16_top_plate.stl
86.0 x 120.0 x 2.00

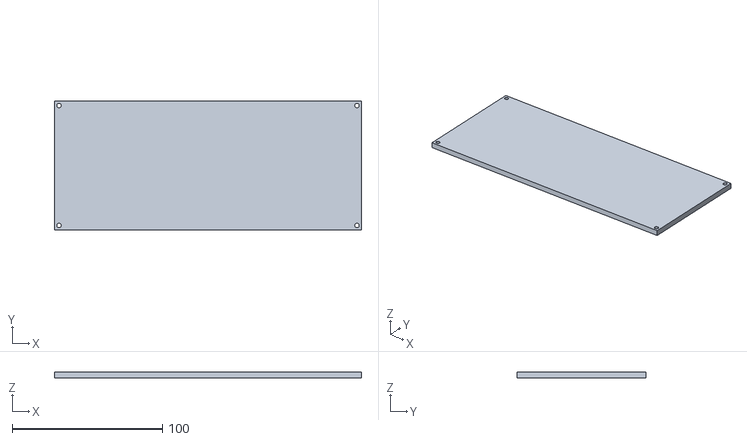
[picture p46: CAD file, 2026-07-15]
MonkiiBoard39/case/4x10_bottom_plate.stl
204.0 x 85.6 x 4.00

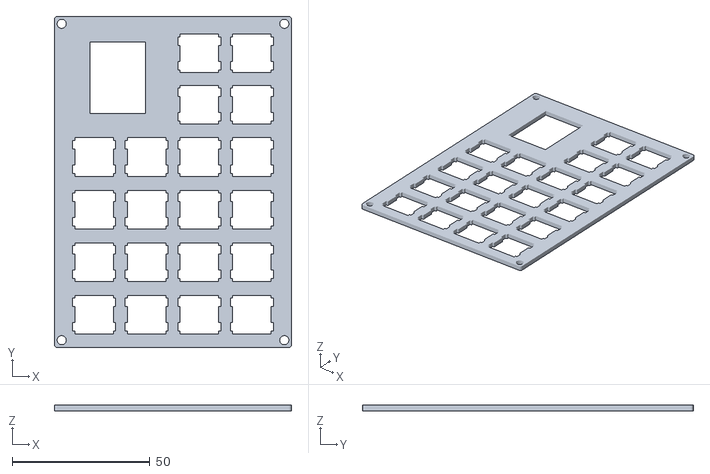
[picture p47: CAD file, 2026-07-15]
MonkiiPad20/case/MonkiiPad20_top_plate.stl
86.0 x 120.0 x 2.00

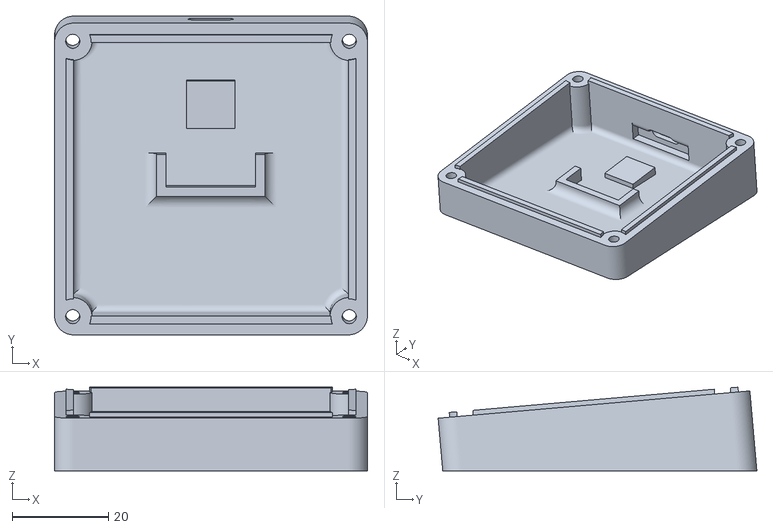
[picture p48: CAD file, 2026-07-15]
MonkiiPad3x3/case/VOID9_-_Bottom_-_Angled.stl
65.2 x 66.4 x 17.4

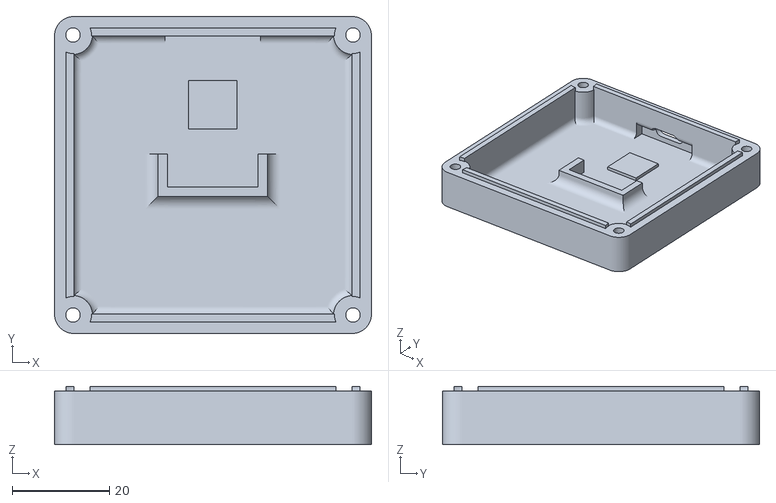
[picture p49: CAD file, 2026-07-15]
MonkiiPad3x3/case/VOID9_-_Bottom_-_Flat.stl
65.2 x 65.1 x 12.0

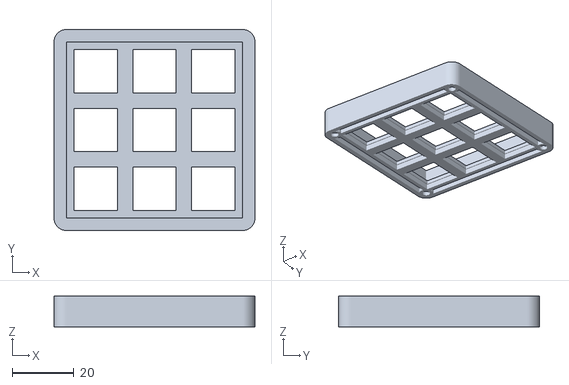
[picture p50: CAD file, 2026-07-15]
MonkiiPad3x3/case/VOID9_-_Top_-_Flat.stl
65.2 x 65.1 x 10.0

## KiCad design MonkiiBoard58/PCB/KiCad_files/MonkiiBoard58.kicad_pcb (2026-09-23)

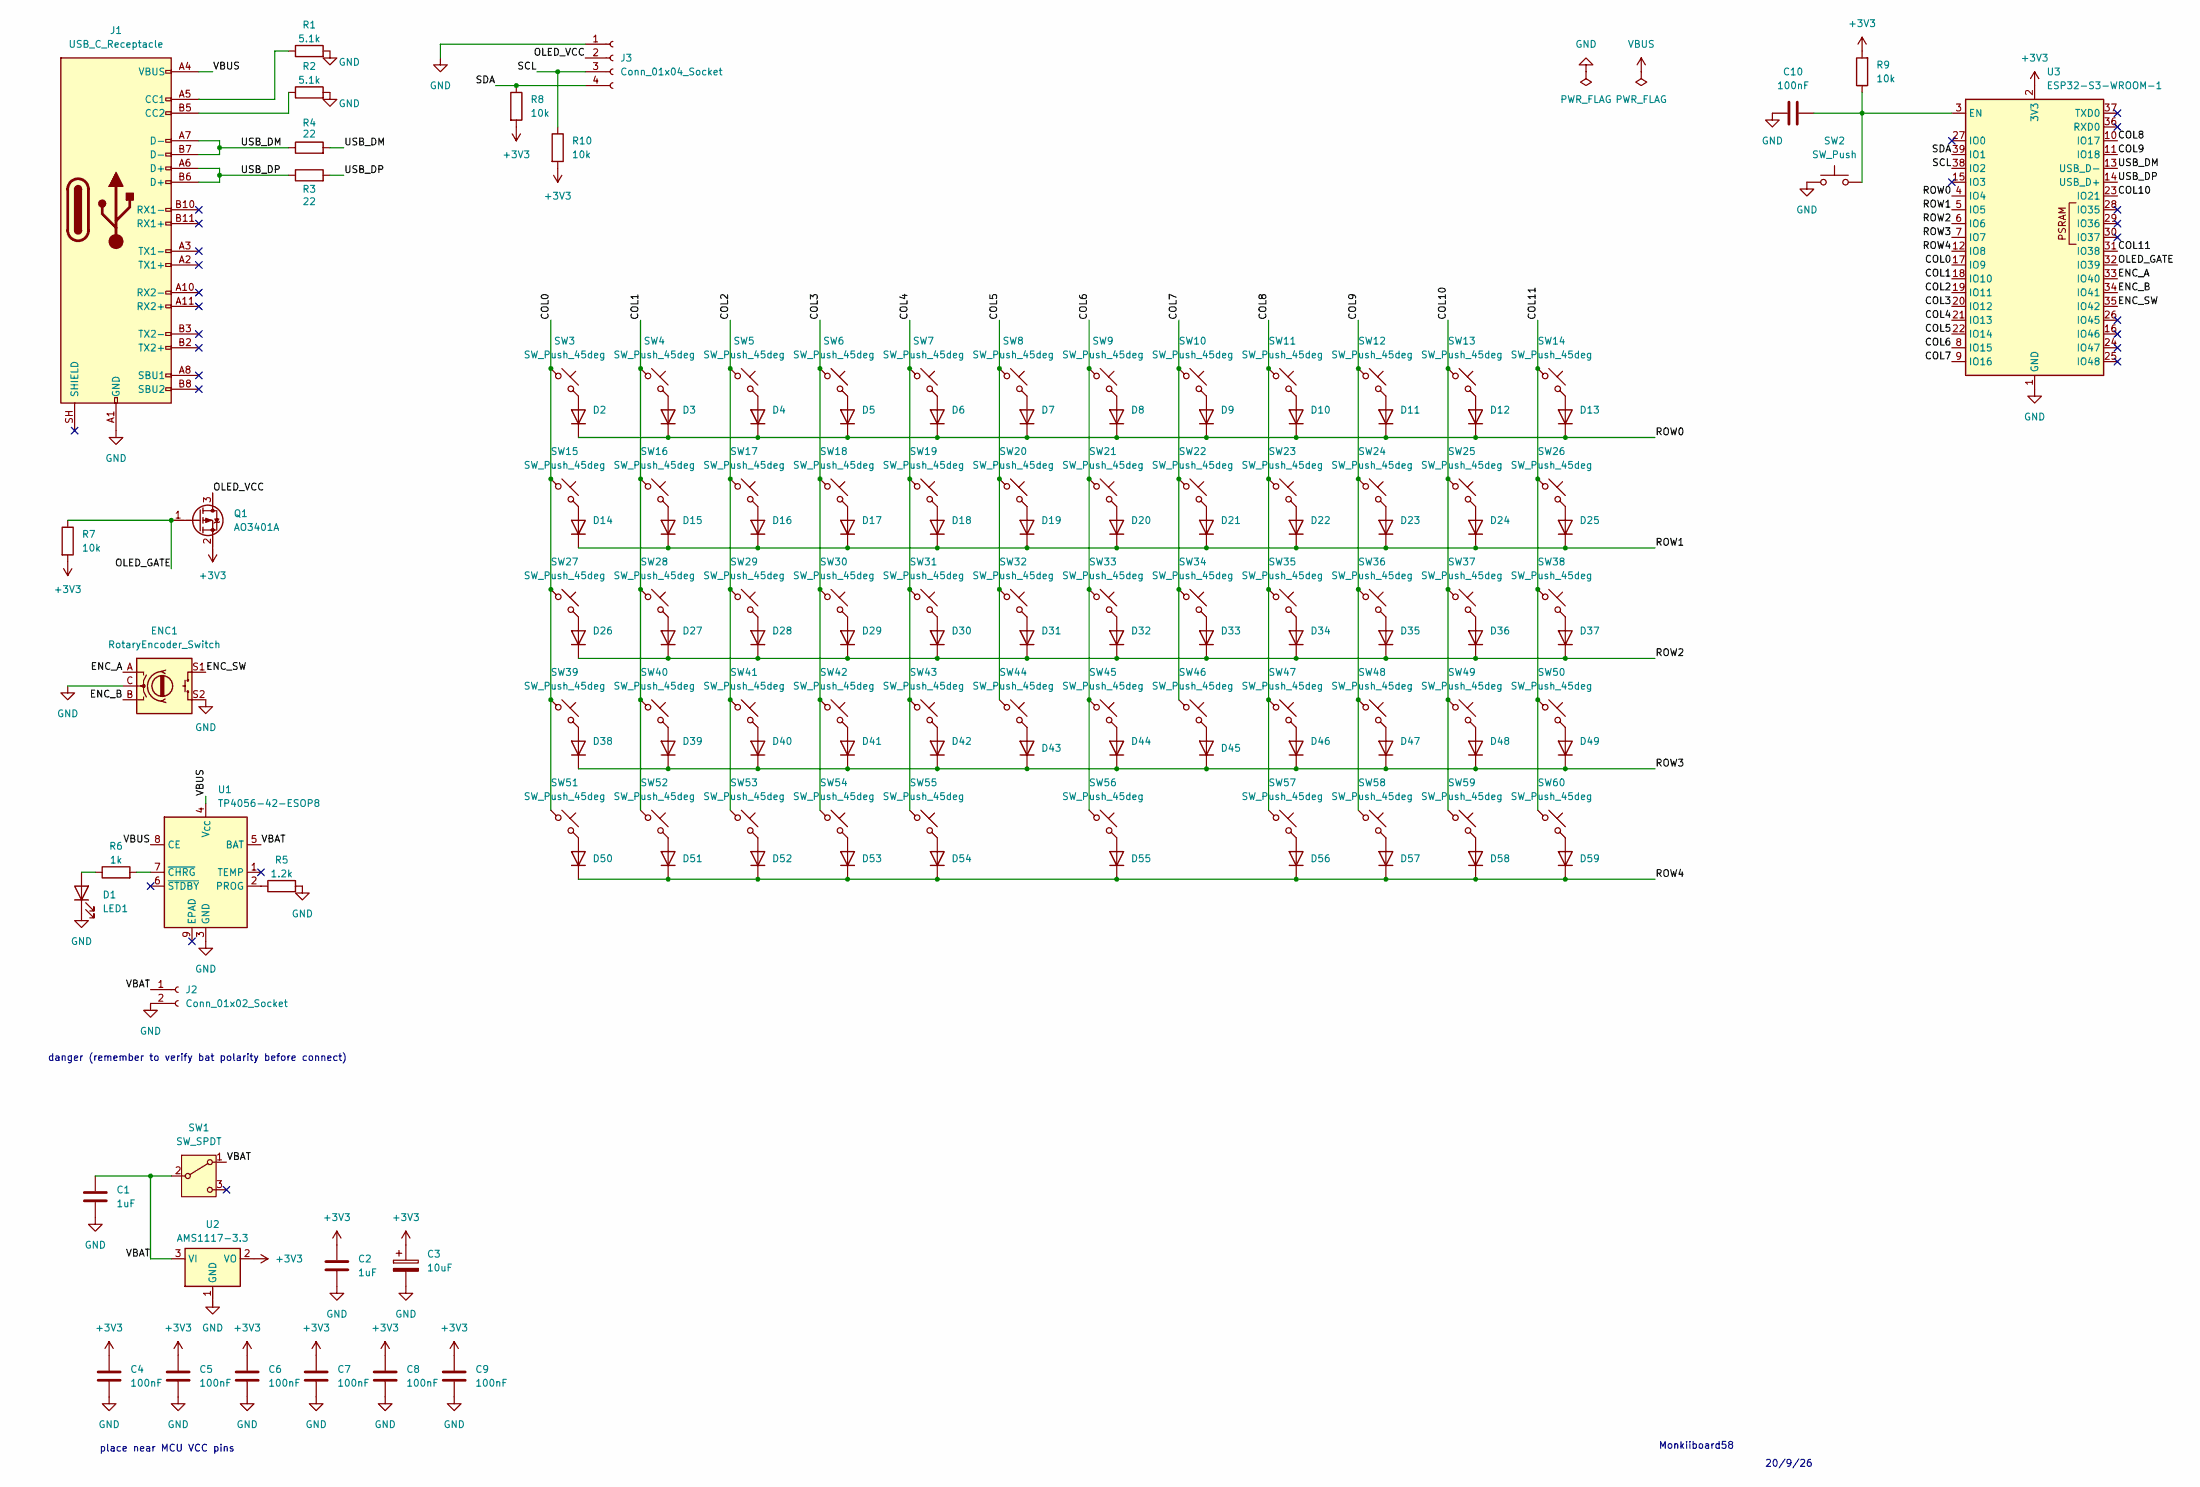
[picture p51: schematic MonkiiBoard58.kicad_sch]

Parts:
C1, C2: 1uF; C_0402_1005Metric
C3: 10uF; C_0402_1005Metric
C4, C5, C6, C7, C8, C9, C10: 100nF; C_0402_1005Metric
D1: LED1; LED_0603_1608Metric
D2, D3, D4, D5, D6, D7, D8, D9, D10, D11, D12, D13, D14, D15, D16, D17, D18, D19, D20, D21, D22, D23, D24, D25, D26, D27, D28, D29, D30, D31, D32, D33, D34, D35, D36, D37, D38, D39, D40, D41, D42, D43, D44, D45, D46, D47, D48, D49, D50, D51, D52, D53, D54, D55, D56, D57, D58, D59: 1N4148; D_DO-35_SOD27_P7.62mm_Horizontal
ENC1: RotaryEncoder_Switch; RotaryEncoder_Alps_EC11E-Switch_Vertical_H20mm
J1: USB_C_Receptacle; USB_C_Receptacle_GCT_USB4085
J2: Conn_01x02_Socket; JST_PH_B2B-PH-K_1x02_P2.00mm_Vertical
J3: Conn_01x04_Socket; PinSocket_1x04_P2.54mm_Vertical
Q1: AO3401A; SOT-23
R1, R2: 5.1k; R_0402_1005Metric
R3, R4: 22; R_0402_1005Metric
R5: 1.2k; R_0402_1005Metric
R6: 1k; R_0402_1005Metric
R7, R8, R9, R10: 10k; R_0402_1005Metric
SW1: SW_SPDT; SW_SPDT_PCM12
SW2: SW_Push; SW_SPST_B3U-1000P
SW3, SW4, SW5, SW6, SW7, SW8, SW9, SW10, SW11, SW12, SW13, SW14, SW15, SW16, SW17, SW18, SW19, SW20, SW21, SW22, SW23, SW24, SW25, SW26, SW27, SW28, SW29, SW30, SW31, SW32, SW33, SW34, SW35, SW36, SW37, SW38, SW39, SW40, SW41, SW42, SW43, SW44, SW45, SW46, SW47, SW48, SW49, SW50, SW51, SW52, SW53, SW54, SW57, SW58, SW59, SW60: SW_Push_45deg; SW_Cherry_MX_1.00u_PCB
SW55, SW56: SW_Push_45deg; SW_Cherry_MX_2.00u_PCB
U1: TP4056-42-ESOP8; SOIC-8-1EP_3.9x4.9mm_P1.27mm_EP2.41x3.3mm_ThermalVias
U2: AMS1117-3.3; SOT-223-3_TabPin2
U3: ESP32-S3-WROOM-1

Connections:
+3V3: C2.1, C3.1, C4.1, C5.1, C6.1, C7.1, C8.1, C9.1, Q1.2 (S), R7.2, R8.2, R9.2, R10.2, U2.2 (VO), U3.2 (3V3)
/COL0: SW3.1, SW15.1, SW27.1, SW39.1, SW51.1, U3.17 (IO9)
/COL1: SW4.1, SW16.1, SW28.1, SW40.1, SW52.1, U3.18 (IO10)
/COL2: SW5.1, SW17.1, SW29.1, SW41.1, SW53.1, U3.19 (IO11)
/COL3: SW6.1, SW18.1, SW30.1, SW42.1, SW54.1, U3.20 (IO12)
/COL4: SW7.1, SW19.1, SW31.1, SW43.1, SW55.1, U3.21 (IO13)
/COL5: SW8.1, SW20.1, SW32.1, SW44.1, U3.22 (IO14)
/COL6: SW9.1, SW21.1, SW33.1, SW45.1, SW56.1, U3.8 (IO15)
/COL7: SW10.1, SW22.1, SW34.1, SW46.1, U3.9 (IO16)
/COL8: SW11.1, SW23.1, SW35.1, SW47.1, SW57.1, U3.10 (IO17)
/COL9: SW12.1, SW24.1, SW36.1, SW48.1, SW58.1, U3.11 (IO18)
/COL10: SW13.1, SW25.1, SW37.1, SW49.1, SW59.1, U3.23 (IO21)
/COL11: SW14.1, SW26.1, SW38.1, SW50.1, SW60.1, U3.31 (IO38)
/ENC_A: ENC1.A, U3.33 (IO40)
/ENC_B: ENC1.B, U3.34 (IO41)
/ENC_SW: ENC1.S1, U3.35 (IO42)
/OLED_GATE: Q1.1 (G), R7.1, U3.32 (IO39)
/OLED_VCC: J3.2, Q1.3 (D)
/ROW0: D2.1 (K), D3.1 (K), D4.1 (K), D5.1 (K), D6.1 (K), D7.1 (K), D8.1 (K), D9.1 (K), D10.1 (K), D11.1 (K), D12.1 (K), D13.1 (K), U3.4 (IO4)
/ROW1: D14.1 (K), D15.1 (K), D16.1 (K), D17.1 (K), D18.1 (K), D19.1 (K), D20.1 (K), D21.1 (K), D22.1 (K), D23.1 (K), D24.1 (K), D25.1 (K), U3.5 (IO5)
/ROW2: D26.1 (K), D27.1 (K), D28.1 (K), D29.1 (K), D30.1 (K), D31.1 (K), D32.1 (K), D33.1 (K), D34.1 (K), D35.1 (K), D36.1 (K), D37.1 (K), U3.6 (IO6)
/ROW3: D38.1 (K), D39.1 (K), D40.1 (K), D41.1 (K), D42.1 (K), D43.1 (K), D44.1 (K), D45.1 (K), D46.1 (K), D47.1 (K), D48.1 (K), D49.1 (K), U3.7 (IO7)
/ROW4: D50.1 (K), D51.1 (K), D52.1 (K), D53.1 (K), D54.1 (K), D55.1 (K), D56.1 (K), D57.1 (K), D58.1 (K), D59.1 (K), U3.12 (IO8)
/SCL: J3.3, R10.1, U3.38 (IO2)
/SDA: J3.4, R8.1, U3.39 (IO1)
/USB_DM: J1.A7 (D-), J1.B7 (D-), R4.1, R4.2, U3.13 (USB_D-)
/USB_DP: J1.A6 (D+), J1.B6 (D+), R3.1, R3.2, U3.14 (USB_D+)
/VBAT: C1.1, J2.1, SW1.1 (A), SW1.2 (B), U1.5 (BAT), U2.3 (VI)
GND: C1.2, C2.2, C3.2, C4.2, C5.2, C6.2, C7.2, C8.2, C9.2, C10.1, D1.1 (K), ENC1.C, ENC1.S2, J1.A1 (GND), J1.A12 (GND), J1.B1 (GND), J1.B12 (GND), J2.2, J3.1, R1.2, R2.2, R5.2, SW2.1, U1.3 (GND), U2.1 (GND), U3.1 (GND), U3.40 (GND), U3.41 (GND)
unnamed: D1.2 (A), R6.1
unnamed: D2.2 (A), SW3.2
unnamed: D3.2 (A), SW4.2
unnamed: D4.2 (A), SW5.2
unnamed: D5.2 (A), SW6.2
unnamed: D6.2 (A), SW7.2
unnamed: D7.2 (A), SW8.2
unnamed: D8.2 (A), SW9.2
unnamed: D9.2 (A), SW10.2
unnamed: D10.2 (A), SW11.2
unnamed: D11.2 (A), SW12.2
unnamed: D12.2 (A), SW13.2
unnamed: D13.2 (A), SW14.2
unnamed: D14.2 (A), SW15.2
unnamed: D15.2 (A), SW16.2
unnamed: D16.2 (A), SW17.2
unnamed: D17.2 (A), SW18.2
unnamed: D18.2 (A), SW19.2
unnamed: D19.2 (A), SW20.2
unnamed: D20.2 (A), SW21.2
unnamed: D21.2 (A), SW22.2
unnamed: D22.2 (A), SW23.2
unnamed: D23.2 (A), SW24.2
unnamed: D24.2 (A), SW25.2
unnamed: D25.2 (A), SW26.2
unnamed: D26.2 (A), SW27.2
unnamed: D27.2 (A), SW28.2
unnamed: D28.2 (A), SW29.2
unnamed: D29.2 (A), SW30.2
unnamed: D30.2 (A), SW31.2
unnamed: D31.2 (A), SW32.2
unnamed: D32.2 (A), SW33.2
unnamed: D33.2 (A), SW34.2
unnamed: D34.2 (A), SW35.2
unnamed: D35.2 (A), SW36.2
unnamed: D36.2 (A), SW37.2
unnamed: D37.2 (A), SW38.2
unnamed: D38.2 (A), SW39.2
unnamed: D39.2 (A), SW40.2
unnamed: D40.2 (A), SW41.2
unnamed: D41.2 (A), SW42.2
unnamed: D42.2 (A), SW43.2
unnamed: D43.2 (A), SW44.2
unnamed: D44.2 (A), SW45.2
unnamed: D45.2 (A), SW46.2
unnamed: D46.2 (A), SW47.2
unnamed: D47.2 (A), SW48.2
unnamed: D48.2 (A), SW49.2
unnamed: D49.2 (A), SW50.2
unnamed: D50.2 (A), SW51.2
unnamed: D51.2 (A), SW52.2
unnamed: D52.2 (A), SW53.2
unnamed: D53.2 (A), SW54.2
unnamed: D54.2 (A), SW55.2
unnamed: D55.2 (A), SW56.2
unnamed: D56.2 (A), SW57.2
unnamed: D57.2 (A), SW58.2
unnamed: D58.2 (A), SW59.2
unnamed: D59.2 (A), SW60.2
unnamed: J1.A5 (CC1), R1.1
unnamed: J1.B5 (CC2), R2.1
unnamed: R5.1, U1.2 (PROG)
unnamed: R6.2, U1.7 (~CHRG)
unnamed: C10.2, R9.1, SW2.2, U3.3 (EN)
VBUS: J1.A4 (VBUS), J1.A9 (VBUS), J1.B4 (VBUS), J1.B9 (VBUS), U1.4 (V_{CC}), U1.8 (CE)

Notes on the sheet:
Monkiiboard58
danger (remember to verify bat polarity before connect)
place near MCU VCC pins
20/9/26

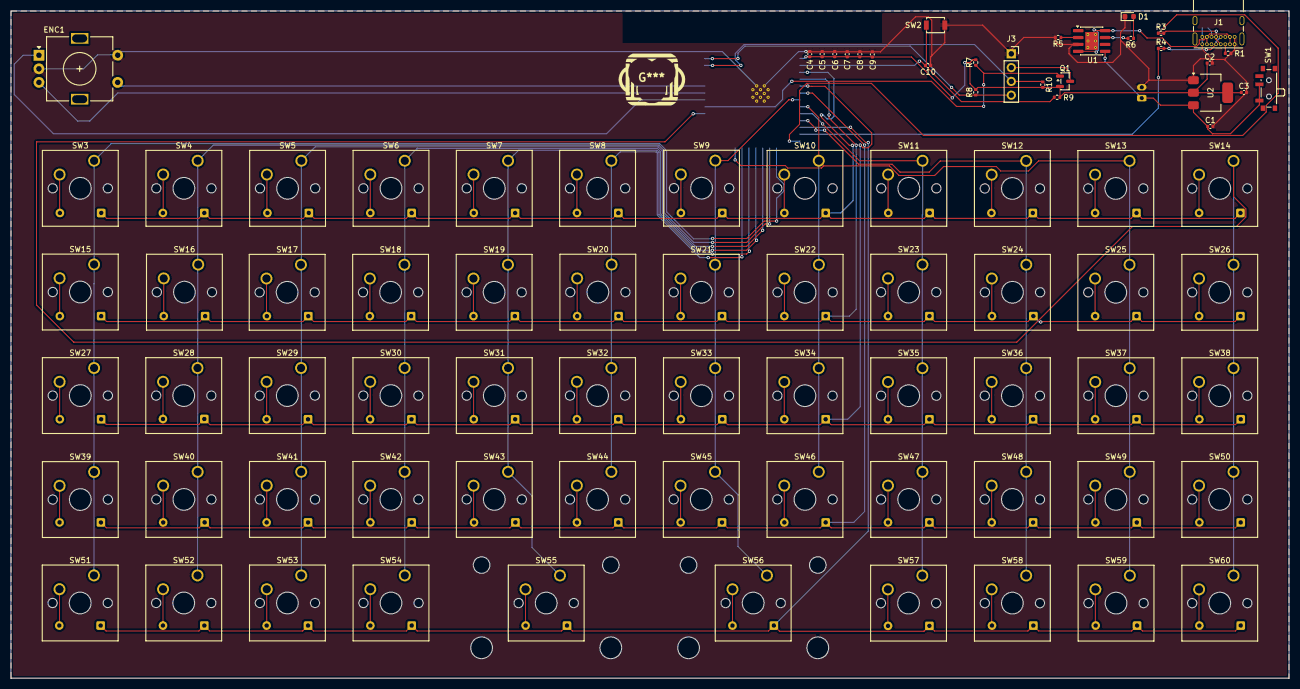
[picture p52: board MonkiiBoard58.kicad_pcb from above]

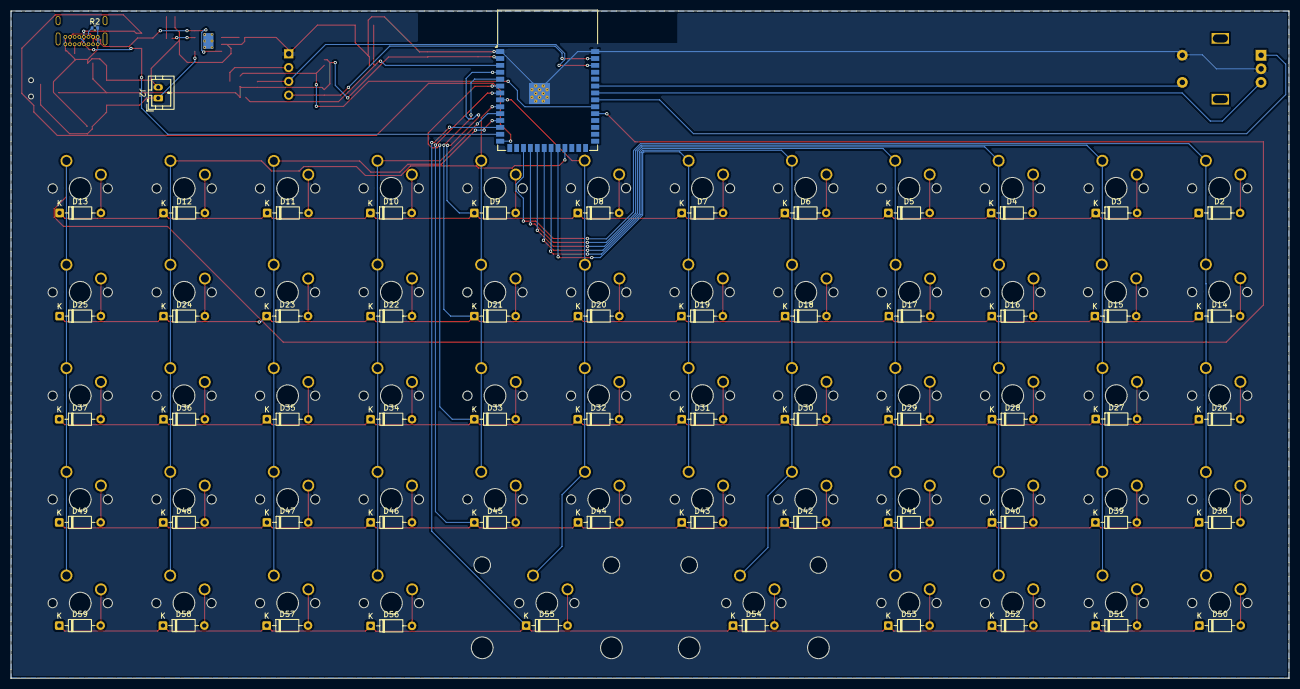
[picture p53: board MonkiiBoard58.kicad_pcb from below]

Board: 2 copper layers, 235.4 x 122.9 mm, 147 parts (61 on the bottom side), 94 nets.

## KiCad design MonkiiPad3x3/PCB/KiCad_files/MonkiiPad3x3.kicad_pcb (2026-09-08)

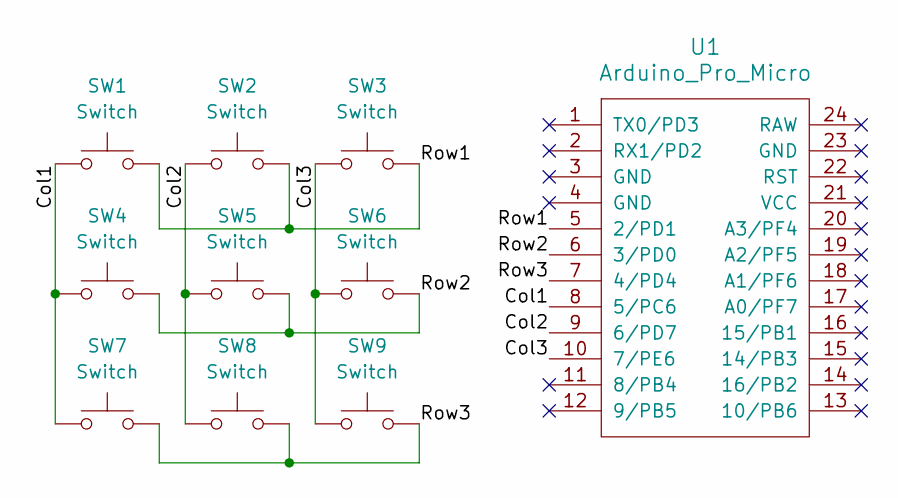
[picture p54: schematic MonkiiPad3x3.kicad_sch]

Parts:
SW1, SW2, SW3, SW4, SW5, SW6, SW7, SW8, SW9: Switch; SW_Cherry_MX_1.00u_PCB
U1: Arduino_Pro_Micro

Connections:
/Col1: SW1.1, SW4.1, SW7.1, U1.8 (5/PC6)
/Col2: SW2.1, SW5.1, SW8.1, U1.9 (6/PD7)
/Col3: SW3.1, SW6.1, SW9.1, U1.10 (7/PE6)
/Row1: SW1.2, SW2.2, SW3.2, U1.5 (2/PD1)
/Row2: SW4.2, SW5.2, SW6.2, U1.6 (3/PD0)
/Row3: SW7.2, SW8.2, SW9.2, U1.7 (4/PD4)

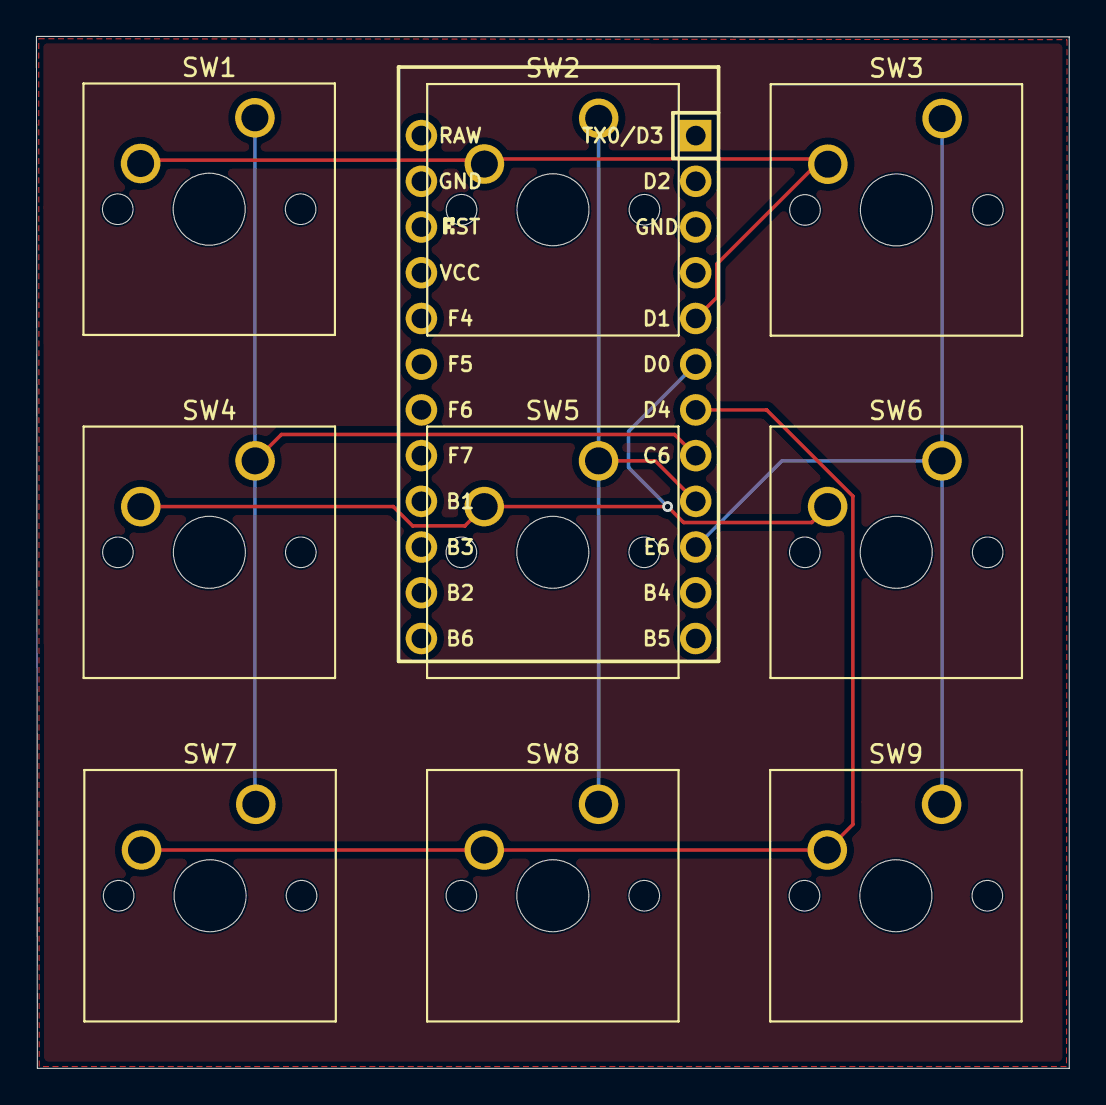
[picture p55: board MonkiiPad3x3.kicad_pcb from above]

Board: 2 copper layers, 57.4 x 57.3 mm, 10 parts (1 on the bottom side), 6 nets.

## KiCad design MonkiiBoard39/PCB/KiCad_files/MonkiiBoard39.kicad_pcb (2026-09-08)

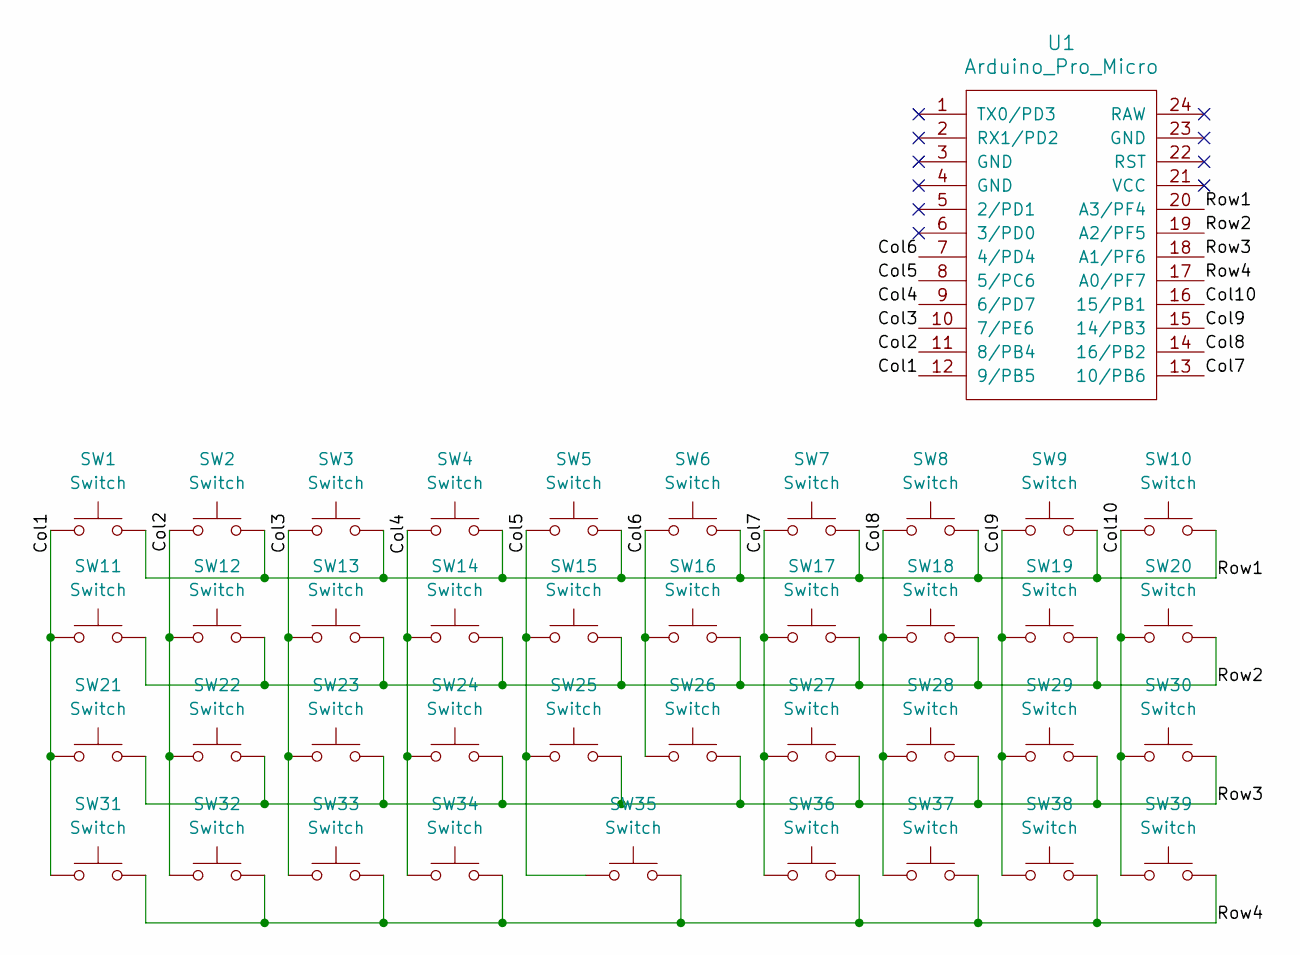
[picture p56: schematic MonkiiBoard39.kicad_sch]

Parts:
SW1, SW2, SW3, SW4, SW5, SW6, SW7, SW8, SW9, SW10, SW11, SW12, SW13, SW14, SW15, SW16, SW17, SW18, SW19, SW20, SW21, SW22, SW23, SW24, SW25, SW26, SW27, SW28, SW29, SW30, SW31, SW32, SW33, SW34, SW35, SW36, SW37, SW38, SW39: Switch; SW_Cherry_MX_1.00u_PCB
U1: Arduino_Pro_Micro

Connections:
/Col1: SW1.1, SW11.1, SW21.1, SW31.1, U1.12 (9/PB5)
/Col2: SW2.1, SW12.1, SW22.1, SW32.1, U1.11 (8/PB4)
/Col3: SW3.1, SW13.1, SW23.1, SW33.1, U1.10 (7/PE6)
/Col4: SW4.1, SW14.1, SW24.1, SW34.1, U1.9 (6/PD7)
/Col5: SW5.1, SW15.1, SW25.1, SW35.1, U1.8 (5/PC6)
/Col6: SW6.1, SW16.1, SW26.1, U1.7 (4/PD4)
/Col7: SW7.1, SW17.1, SW27.1, SW36.1, U1.13 (10/PB6)
/Col8: SW8.1, SW18.1, SW28.1, SW37.1, U1.14 (16/PB2)
/Col9: SW9.1, SW19.1, SW29.1, SW38.1, U1.15 (14/PB3)
/Col10: SW10.1, SW20.1, SW30.1, SW39.1, U1.16 (15/PB1)
/Row1: SW1.2, SW2.2, SW3.2, SW4.2, SW5.2, SW6.2, SW7.2, SW8.2, SW9.2, SW10.2, U1.20 (A3/PF4)
/Row2: SW11.2, SW12.2, SW13.2, SW14.2, SW15.2, SW16.2, SW17.2, SW18.2, SW19.2, SW20.2, U1.19 (A2/PF5)
/Row3: SW21.2, SW22.2, SW23.2, SW24.2, SW25.2, SW26.2, SW27.2, SW28.2, SW29.2, SW30.2, U1.18 (A1/PF6)
/Row4: SW31.2, SW32.2, SW33.2, SW34.2, SW35.2, SW36.2, SW37.2, SW38.2, SW39.2, U1.17 (A0/PF7)

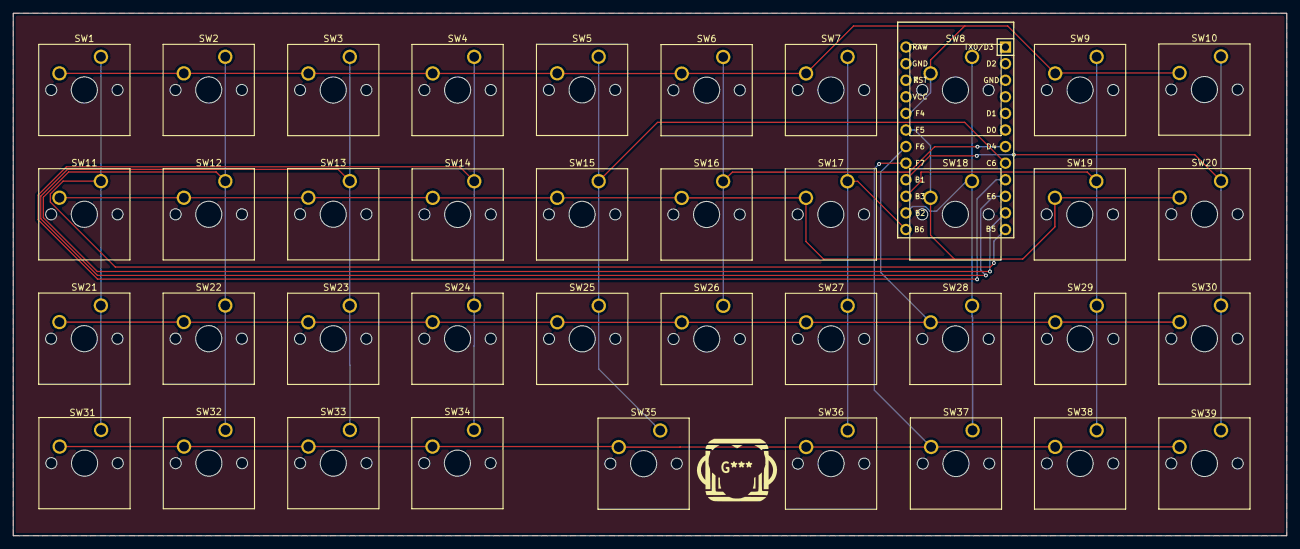
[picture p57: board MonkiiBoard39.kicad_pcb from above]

Board: 2 copper layers, 195.0 x 80.0 mm, 40 parts (1 on the bottom side), 14 nets.

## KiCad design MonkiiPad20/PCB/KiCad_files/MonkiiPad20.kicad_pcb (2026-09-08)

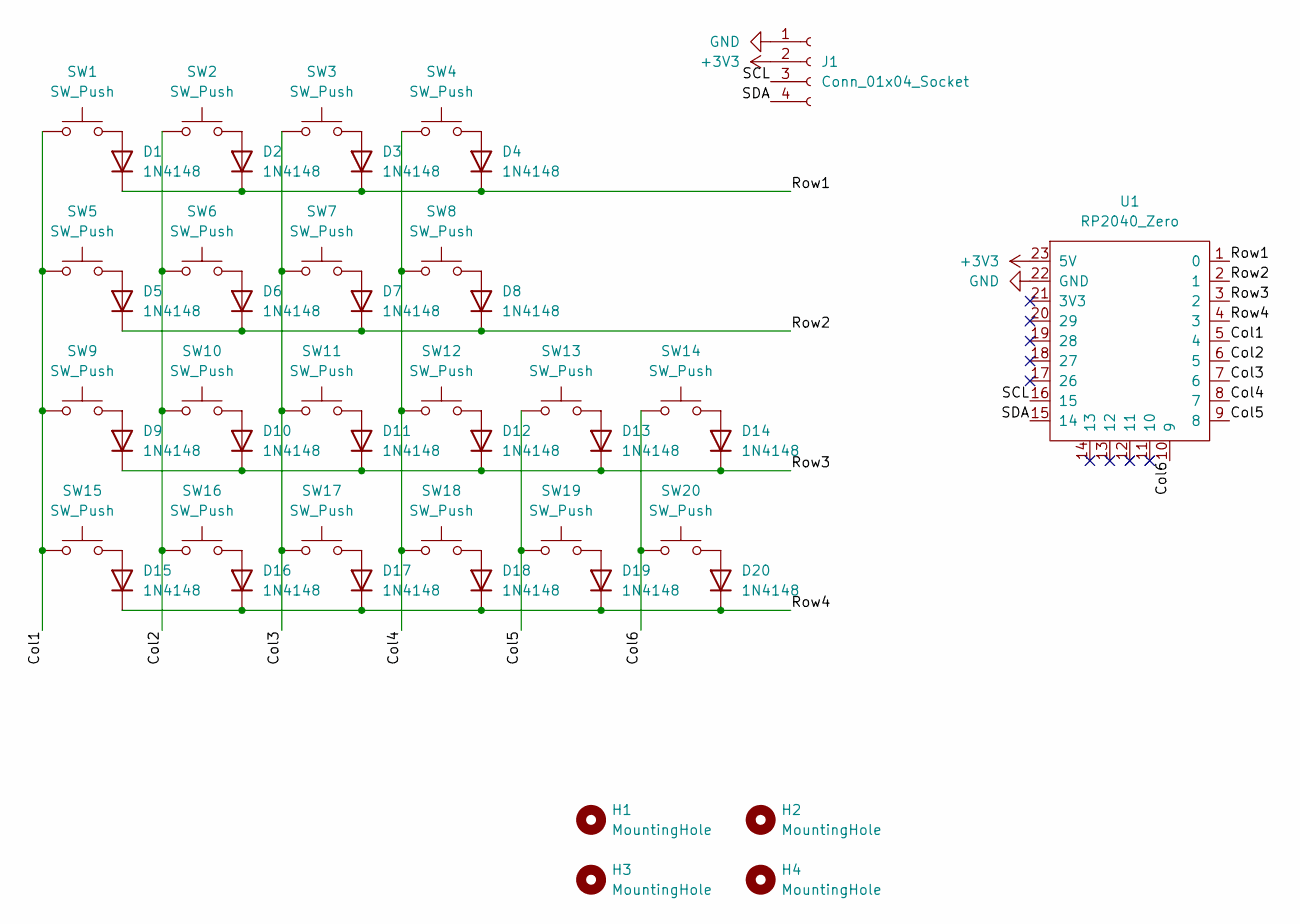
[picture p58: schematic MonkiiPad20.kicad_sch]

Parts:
D1, D2, D3, D4, D5, D6, D7, D8, D9, D10, D11, D12, D13, D14, D15, D16, D17, D18, D19, D20: 1N4148; D_DO-35_SOD27_P7.62mm_Horizontal
H1, H2, H3, H4: MountingHole; MountingHole_4mm
J1: Conn_01x04_Socket; PinHeader_1x04_P2.54mm_Vertical
SW1, SW2, SW3, SW4, SW5, SW6, SW7, SW8, SW9, SW10, SW11, SW12, SW13, SW14, SW15, SW16, SW17, SW18, SW19, SW20: SW_Push; SW_Cherry_MX_1.00u_PCB
U1: RP2040_Zero

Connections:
+3V3: J1.2, U1.23 (5V)
/Col1: SW1.1, SW5.1, SW9.1, SW15.1, U1.5 (4)
/Col2: SW2.1, SW6.1, SW10.1, SW16.1, U1.6 (5)
/Col3: SW3.1, SW7.1, SW11.1, SW17.1, U1.7 (6)
/Col4: SW4.1, SW8.1, SW12.1, SW18.1, U1.8 (7)
/Col5: SW13.1, SW19.1, U1.9 (8)
/Col6: SW14.1, SW20.1, U1.10 (9)
/Row1: D1.1 (K), D2.1 (K), D3.1 (K), D4.1 (K), U1.1 (0)
/Row2: D5.1 (K), D6.1 (K), D7.1 (K), D8.1 (K), U1.2 (1)
/Row3: D9.1 (K), D10.1 (K), D11.1 (K), D12.1 (K), D13.1 (K), D14.1 (K), U1.3 (2)
/Row4: D15.1 (K), D16.1 (K), D17.1 (K), D18.1 (K), D19.1 (K), D20.1 (K), U1.4 (3)
/SCL: J1.3, U1.16 (15)
/SDA: J1.4, U1.15 (14)
GND: J1.1, U1.22 (GND)
unnamed: D1.2 (A), SW1.2
unnamed: D2.2 (A), SW2.2
unnamed: D3.2 (A), SW3.2
unnamed: D4.2 (A), SW4.2
unnamed: D5.2 (A), SW5.2
unnamed: D6.2 (A), SW6.2
unnamed: D7.2 (A), SW7.2
unnamed: D8.2 (A), SW8.2
unnamed: D9.2 (A), SW9.2
unnamed: D10.2 (A), SW10.2
unnamed: D11.2 (A), SW11.2
unnamed: D12.2 (A), SW12.2
unnamed: D13.2 (A), SW13.2
unnamed: D14.2 (A), SW14.2
unnamed: D15.2 (A), SW15.2
unnamed: D16.2 (A), SW16.2
unnamed: D17.2 (A), SW17.2
unnamed: D18.2 (A), SW18.2
unnamed: D19.2 (A), SW19.2
unnamed: D20.2 (A), SW20.2

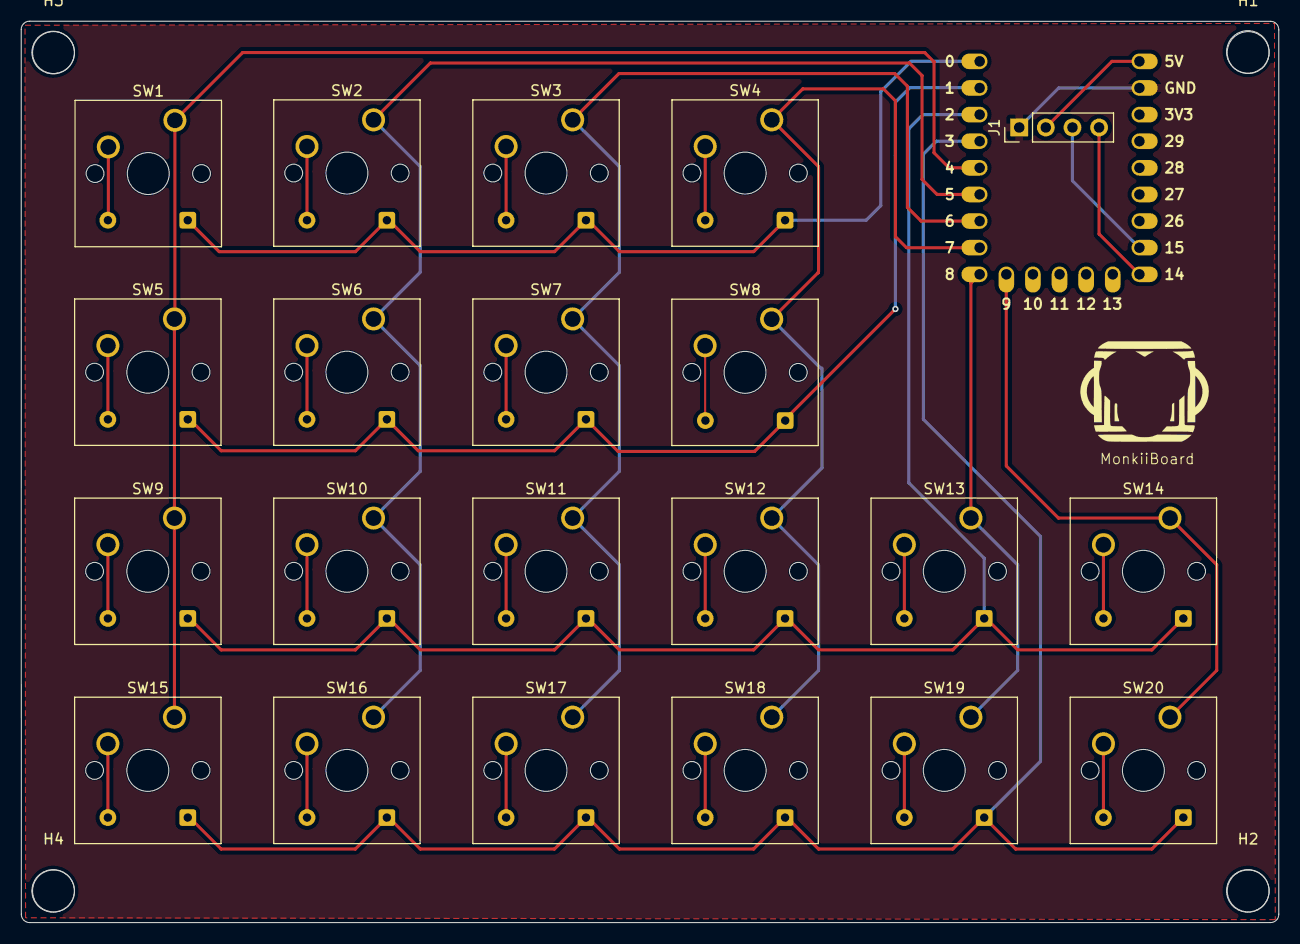
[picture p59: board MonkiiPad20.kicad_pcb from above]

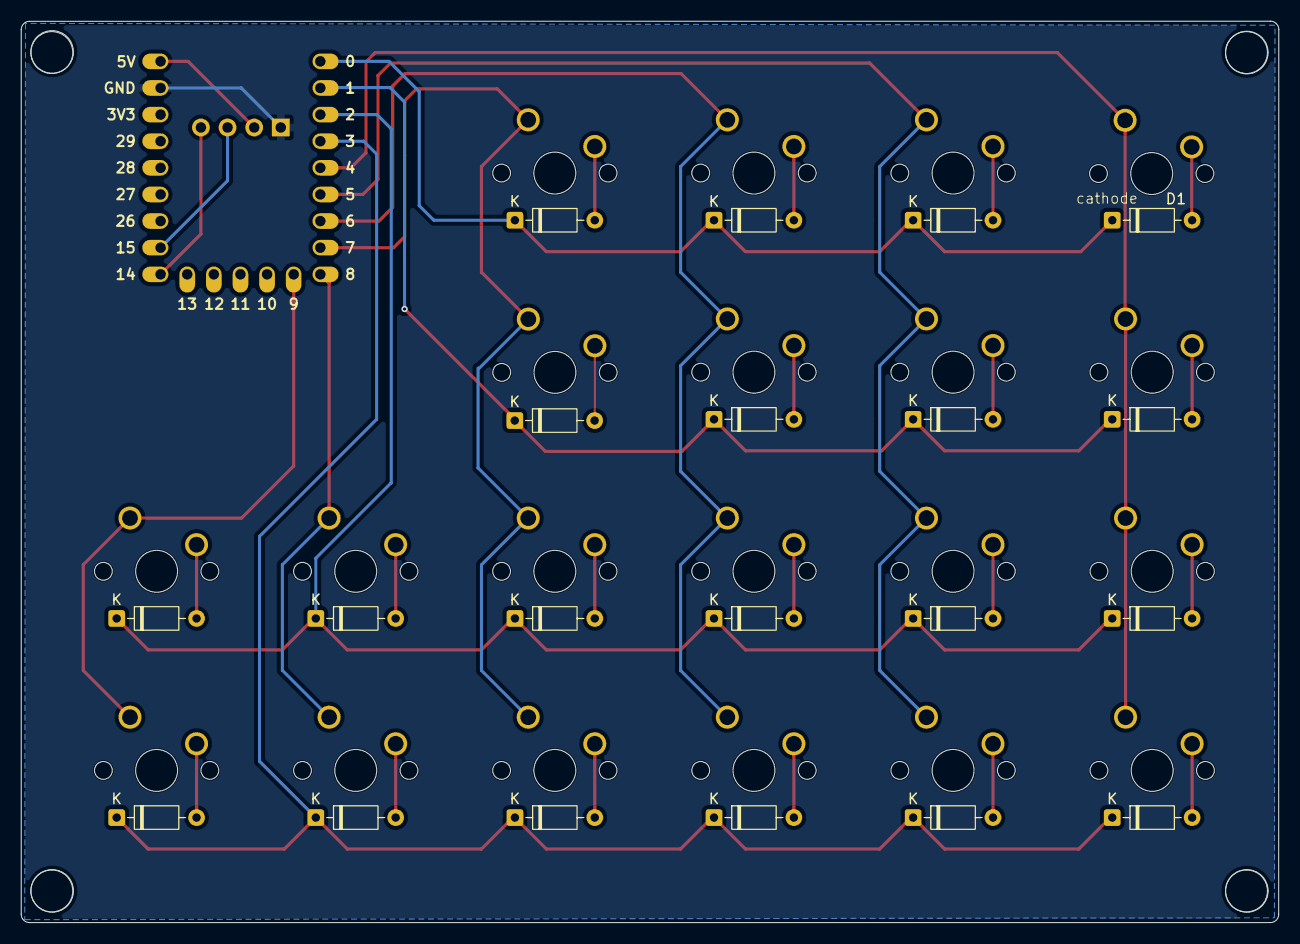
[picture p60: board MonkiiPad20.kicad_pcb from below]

Board: 2 copper layers, 120.0 x 86.0 mm, 46 parts (21 on the bottom side), 34 nets.

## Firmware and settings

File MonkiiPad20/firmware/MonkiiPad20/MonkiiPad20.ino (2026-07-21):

#include <Keyboard.h>
#include <Wire.h>
#include <Adafruit_GFX.h>
#include <Adafruit_SSD1306.h>

// 128x64 oled, I put it on Wire1 and never wired the reset pin
Adafruit_SSD1306 display(128, 64, &Wire1, -1);

// my matrix pins, rows drive and cols read
const int ROW_NUM = 4;
const int COL_NUM = 6;
const int rowPins[ROW_NUM] = {0, 1, 2, 3};
const int colPins[COL_NUM] = {4, 10, 6, 7, 8, 9};

// made up codes for the keys that arent normal ascii
#define K_EMPTY  0x00
#define K_FN     0xF1
#define K_CTRL   0xF2
#define K_DEL    0xF3

// keymap is [layer][row][col]. I kept FN and CTRL in the same spot on both
// layers so my finger doesnt have to move. only real diff is row0 col3,
// thats DEL on shortcuter and just a '4' on typist. boots on layer 0.
const uint8_t keymap[2][ROW_NUM][COL_NUM] = {
  // shortcuter
  {
    { '1',   '2',  '3',  K_DEL,  K_EMPTY, K_EMPTY },
    { 'q',   'w',  'e',  'r',    K_EMPTY, K_EMPTY },
    { 'a',   's',  'd',  'f',    'g',     K_FN    },
    { 'z',   'x',  'c',  'v',    'b',     K_CTRL  },
  },
  // typist
  {
    { '1',   '2',  '3',  '4',    K_EMPTY, K_EMPTY },
    { 'q',   'w',  'e',  'r',    K_EMPTY, K_EMPTY },
    { 'a',   's',  'd',  'f',    'g',     K_FN    },
    { 'z',   'x',  'c',  'v',    'b',     K_CTRL  },
  },
};

int           currentLayer      = 0;
char          lastKeyStr[8]     = "---";
unsigned long lastActivityTime  = 0;
bool          screensaverActive = false;
bool          oledNeedsUpdate   = true;

// fnToggled is there so one long hold doesnt flip the layer over and over
bool          fnHeld      = false;
unsigned long fnHoldStart = 0;
bool          fnToggled   = false;

// pressedKey remembers what each switch actually sent, otherwise switching
// layers mid press releases the wrong key and it sticks down
bool          keyState[ROW_NUM][COL_NUM];
bool          lastRaw[ROW_NUM][COL_NUM];
unsigned long debounceTimers[ROW_NUM][COL_NUM];
uint8_t       pressedKey[ROW_NUM][COL_NUM];
const unsigned long DEBOUNCE_MS = 20;

// screensaver eyes
float         eyePupilX        = 0.0f;   // -1 is left, 1 is right
float         eyePupilTargetX  = 0.0f;
float         eyeOpenH         = 1.0f;   // 1 open, 0 shut
float         eyeOpenTarget    = 1.0f;
int           eyeSeqIdx        = 0;
unsigned long lastEyeStateTime = 0;
unsigned long lastEyeDrawTime  = 0;

const unsigned long IDLE_TIMEOUT  = 5000;
const unsigned long EYE_STATE_DUR = 700;
const unsigned long EYE_DRAW_INTV = 33;  // ~30fps

// looks ahead, left, ahead, right, ahead, then blinks. loops forever
const float eyePupilSeq[] = { 0.0f, -1.0f,  0.0f, 1.0f, 0.0f, 0.0f };
const bool  eyeBlinkSeq[] = { false, false, false, false, false, true };
const int   EYE_SEQ_LEN   = 6;

// white rounded rects for the eyes, black ones on top for the pupils
void drawRoboEyes(float pupilNorm, float openFactor) {
  display.clearDisplay();

  const int EYE_W      = 46;
  const int EYE_H_FULL = 42;
  const int EYE_R      = 11;   // the roundness, 11 looked cutest
  const int LEFT_CX    = 32;
  const int RIGHT_CX   = 96;
  const int EYE_CY     = 34;
  const int PUPIL_W    = 20;
  const int PUPIL_H_MX = 28;
  const int PUPIL_R    = 7;
  const int MAX_MOVE   = 9;

  int eyeH   = max(2, (int)(EYE_H_FULL * openFactor));
  int eyeTopY = EYE_CY - eyeH / 2;
  int cr     = min(EYE_R, eyeH / 2);      // clamp or a squinting eye wont draw
  int pOff   = (int)(pupilNorm * MAX_MOVE);

  display.fillRoundRect(LEFT_CX  - EYE_W / 2, eyeTopY, EYE_W, eyeH, cr, SSD1306_WHITE);
  display.fillRoundRect(RIGHT_CX - EYE_W / 2, eyeTopY, EYE_W, eyeH, cr, SSD1306_WHITE);

  // hide the pupils mid blink, they just look like smudges
  if (openFactor > 0.25f) {
    int pH   = min(PUPIL_H_MX, eyeH - 10);
    int pTopY = EYE_CY - pH / 2;
    if (pH > 4) {
      display.fillRoundRect(LEFT_CX  - PUPIL_W / 2 + pOff, pTopY, PUPIL_W, pH, PUPIL_R, SSD1306_BLACK);
      display.fillRoundRect(RIGHT_CX - PUPIL_W / 2 + pOff, pTopY, PUPIL_W, pH, PUPIL_R, SSD1306_BLACK);
    }
  }

  display.display();
}

// this is the default screen for the macropad
void drawLayerScreen() {
  display.clearDisplay();
  display.setTextColor(SSD1306_WHITE);

  display.setTextSize(1);
  display.setCursor(0, 0);
  display.print("MONKIIBOARD");
  display.drawLine(0, 10, 127, 10, SSD1306_WHITE);

  display.setTextSize(2);
  display.setCursor(0, 14);
  display.print(currentLayer == 0 ? "SHORTCUTER" : "TYPIST");

  display.drawLine(0, 46, 127, 46, SSD1306_WHITE);
  display.setTextSize(1);
  display.setCursor(0, 50);
  display.print("LAST: ");
  display.print(lastKeyStr);

  display.display();
}

// runs every loop, no delays in here or typing feels laggy
void updateOLED(unsigned long now) {
  if (screensaverActive) {
    if (now - lastEyeStateTime >= EYE_STATE_DUR) {
      lastEyeStateTime = now;
      eyeSeqIdx        = (eyeSeqIdx + 1) % EYE_SEQ_LEN;
      eyePupilTargetX  = eyePupilSeq[eyeSeqIdx];
      eyeOpenTarget    = eyeBlinkSeq[eyeSeqIdx] ? 0.0f : 1.0f;
    }

    if (now - lastEyeDrawTime >= EYE_DRAW_INTV) {
      lastEyeDrawTime = now;

      const float LERP = 0.18f;
      eyePupilX += (eyePupilTargetX - eyePupilX) * LERP;
      eyeOpenH  += (eyeOpenTarget   - eyeOpenH)  * LERP;

      if (eyeOpenTarget < 0.5f && eyeOpenH < 0.06f) {
        eyeOpenTarget = 1.0f;
      }

      drawRoboEyes(eyePupilX, eyeOpenH);
    }

  } else if (oledNeedsUpdate) {
    drawLayerScreen();
    oledNeedsUpdate = false;
  }
}

void toggleLayer() {
  Keyboard.releaseAll();            // let go of everything, the map is changing
  currentLayer      = (currentLayer == 0) ? 1 : 0;
  screensaverActive = false;
  lastActivityTime  = millis();
  drawLayerScreen();
}

void onKeyPress(int r, int c) {
  lastActivityTime = millis();
  pressedKey[r][c] = K_EMPTY;

  // first press after the eyes only wakes it, i dont want a random char typed
  if (screensaverActive) {
    screensaverActive = false;
    drawLayerScreen();
    return;
  }

  uint8_t key      = keymap[currentLayer][r][c];
  pressedKey[r][c] = key;

  if (key == K_EMPTY) return;

  if (key == K_FN) {
    fnHeld      = true;
    fnHoldStart = millis();
    fnToggled   = false;
    return;
  }

  if (key == K_DEL) {
    strncpy(lastKeyStr, "DEL", sizeof(lastKeyStr));
    Keyboard.press(KEY_BACKSPACE);
    oledNeedsUpdate = true;
    return;
  }

  if (key == K_CTRL) {
    strncpy(lastKeyStr, "CTRL", sizeof(lastKeyStr));
    Keyboard.press(KEY_LEFT_CTRL);
    oledNeedsUpdate = true;
    return;
  }

  // everything else is just a normal char
  lastKeyStr[0] = (char)toupper(key);
  lastKeyStr[1] = '\0';
  Keyboard.press((char)key);
  oledNeedsUpdate = true;
}

// release what this switch sent on press, not what the layer says right now
void onKeyRelease(int r, int c) {
  lastActivityTime = millis();
  uint8_t key      = pressedKey[r][c];
  pressedKey[r][c] = K_EMPTY;

  if (key == K_EMPTY)  return;
  if (key == K_FN)     { fnHeld = false; return; }
  if (key == K_DEL)    { Keyboard.release(KEY_BACKSPACE);   return; }
  if (key == K_CTRL)   { Keyboard.release(KEY_LEFT_CTRL);   return; }

  Keyboard.release((char)key);
}

void setup() {
  for (int r = 0; r < ROW_NUM; r++) {
    pinMode(rowPins[r], OUTPUT);
    digitalWrite(rowPins[r], HIGH);
  }
  for (int c = 0; c < COL_NUM; c++) {
    pinMode(colPins[c], INPUT_PULLUP);
  }

  memset(keyState,       false, sizeof(keyState));
  memset(lastRaw,        false, sizeof(lastRaw));
  memset(debounceTimers, 0,     sizeof(debounceTimers));
  memset(pressedKey,     0,     sizeof(pressedKey));

  Keyboard.begin();

  // oled goes on Wire1 so it stays off my matrix pins
  Wire1.setSDA(14);
  Wire1.setSCL(15);
  Wire1.begin();
  display.begin(SSD1306_SWITCHCAPVCC, 0x3C);

  lastActivityTime = millis();
  drawLayerScreen();
}

void loop() {
  unsigned long now = millis();

  // scan one row at a time
  for (int r = 0; r < ROW_NUM; r++) {
    digitalWrite(rowPins[r], LOW);
    delayMicroseconds(10);          // give the line a sec to settle

    for (int c = 0; c < COL_NUM; c++) {
      bool raw = (digitalRead(colPins[c]) == LOW);

      // reset the timer every time it wobbles, only act once its held steady
      if (raw != lastRaw[r][c]) {
        debounceTimers[r][c] = now;
        lastRaw[r][c]        = raw;
      }

      if ((now - debounceTimers[r][c]) >= DEBOUNCE_MS) {
        if (raw != keyState[r][c]) {
          keyState[r][c] = raw;
          if (raw) onKeyPress(r, c);
          else     onKeyRelease(r, c);
        }
      }
    }

    digitalWrite(rowPins[r], HIGH);
  }

  // hold FN for a sec to swap layers
  if (fnHeld && !fnToggled && (now - fnHoldStart) >= 1000) {
    toggleLayer();
    fnToggled = true;
  }

  // been idle a while so give the screen to the eyes
  if (!screensaverActive && (now - lastActivityTime) >= IDLE_TIMEOUT) {
    screensaverActive = true;
    eyeSeqIdx         = 0;
    eyePupilX         = 0.0f;
    eyePupilTargetX   = 0.0f;
    eyeOpenH          = 1.0f;
    eyeOpenTarget     = 1.0f;
    lastEyeStateTime  = now;
    lastEyeDrawTime   = now;
    drawRoboEyes(0.0f, 1.0f);
  }

  updateOLED(now);
}

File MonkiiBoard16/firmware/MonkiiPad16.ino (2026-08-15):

#include <Keyboard.h>
#include <Mouse.h>
#include <Wire.h>
#include <Adafruit_GFX.h>
#include <Adafruit_SSD1306.h>

// 128x64 oled on Wire1, no reset pin wired
Adafruit_SSD1306 display(128, 64, &Wire1, -1);

// 4x4 matrix, rows drive and cols read
const int ROW_NUM = 4;
const int COL_NUM = 4;
const int rowPins[ROW_NUM] = {4, 5, 6, 7};
const int colPins[COL_NUM] = {0, 1, 2, 3};

// rotary encoder, A and B for turning plus the push switch
#define ENC_A   10
#define ENC_B   11
#define ENC_SW   8

// made up codes for the shortcut keys that arent normal ascii
#define K_EMPTY   0x00
#define K_ALL     0xEE
#define K_UNDO    0xEF
#define K_REDO    0xF0
#define K_COPY    0xF1
#define K_PASTE   0xF2
#define K_SAVE    0xF3
#define K_FIND    0xF4
#define K_BOLD    0xF5
#define K_ITAL    0xF6
#define K_UNDR    0xF7
#define K_CMNT    0xF8
#define K_DUPL    0xF9
#define K_INDL    0xFA
#define K_INDR    0xFB
#define K_ENT     0xFC

#define LAYER_NUMPAD    0
#define LAYER_SHORTCUTS 1
#define LAYER_COUNT     2

const uint8_t keymap[LAYER_COUNT][ROW_NUM][COL_NUM] = {
  // numpad
  {
    { '1',   '2',   '3',   '/'   },
    { '4',   '5',   '6',   '*'   },
    { '7',   '8',   '9',   '-'   },
    { '0',   '.',   K_ENT, '+'   },
  },
  // shortcuts
  {
    { K_UNDO,  K_REDO,  K_COPY,  K_PASTE },
    { K_SAVE,  K_FIND,  K_ALL,   K_EMPTY },
    { K_BOLD,  K_ITAL,  K_UNDR,  K_EMPTY },
    { K_CMNT,  K_DUPL,  K_INDL,  K_INDR  },
  },
};

const char* layerName[LAYER_COUNT] = { "NUMPAD", "SHORTCUTS" };

int  currentLayer = LAYER_NUMPAD;

bool          keyState[ROW_NUM][COL_NUM];
bool          lastRaw[ROW_NUM][COL_NUM];
unsigned long debounceTimers[ROW_NUM][COL_NUM];
uint8_t       pressedKey[ROW_NUM][COL_NUM];
const unsigned long DEBOUNCE_MS = 20;

int           encLastA      = HIGH;
bool          encSwState    = false;
bool          encSwLast     = HIGH;
unsigned long encSwDebounce = 0;

bool          menuActive   = false;
int           menuSelected = 0;
unsigned long menuTimeout  = 0;
const unsigned long MENU_HIDE_MS = 3000;

char lastKeyStr[16] = "---";

// the normal screen: current layer up top, last key big underneath
void drawMainScreen() {
  display.clearDisplay();
  display.setTextColor(SSD1306_WHITE);

  display.setTextSize(1);
  display.setCursor(0, 0);
  display.print("LAYER: ");
  display.print(layerName[currentLayer]);
  display.drawLine(0, 10, 127, 10, SSD1306_WHITE);

  display.setTextSize(1);
  display.setCursor(0, 16);
  display.print("LAST KEY:");

  // center it, roughly 18px per char at size 3
  display.setTextSize(3);
  int len  = strlen(lastKeyStr);
  int xPos = max(0, (128 - len * 18) / 2);
  display.setCursor(xPos, 30);
  display.print(lastKeyStr);

  display.display();
}

// the layer picker: highlights the selection, stars the active layer
void drawMenu() {
  display.clearDisplay();
  display.setTextColor(SSD1306_WHITE);

  display.setTextSize(1);
  display.setCursor(35, 0);
  display.print("SELECT LAYER");
  display.drawLine(0, 10, 127, 10, SSD1306_WHITE);

  for (int i = 0; i < LAYER_COUNT; i++) {
    int y = 16 + i * 20;

    // draw the highlighted row as white with black text
    if (i == menuSelected) {
      display.fillRoundRect(2, y - 2, 124, 18, 3, SSD1306_WHITE);
      display.setTextColor(SSD1306_BLACK);
    } else {
      display.setTextColor(SSD1306_WHITE);
    }

    display.setTextSize(1);
    display.setCursor(10, y + 4);
    if (i == currentLayer) display.print("* ");
    else display.print("  ");
    display.print(layerName[i]);
  }

  display.drawLine(0, 54, 127, 54, SSD1306_WHITE);
  display.display();
}

// fire the ctrl combo behind each shortcut code
void pressSpecial(uint8_t key) {
  switch (key) {
    case K_UNDO:  Keyboard.press(KEY_LEFT_CTRL); Keyboard.press('z'); Keyboard.releaseAll(); break;
    case K_REDO:  Keyboard.press(KEY_LEFT_CTRL); Keyboard.press('y'); Keyboard.releaseAll(); break;
    case K_COPY:  Keyboard.press(KEY_LEFT_CTRL); Keyboard.press('c'); Keyboard.releaseAll(); break;
    case K_PASTE: Keyboard.press(KEY_LEFT_CTRL); Keyboard.press('v'); Keyboard.releaseAll(); break;
    case K_SAVE:  Keyboard.press(KEY_LEFT_CTRL); Keyboard.press('s'); Keyboard.releaseAll(); break;
    case K_FIND:  Keyboard.press(KEY_LEFT_CTRL); Keyboard.press('f'); Keyboard.releaseAll(); break;
    case K_ALL:   Keyboard.press(KEY_LEFT_CTRL); Keyboard.press('a'); Keyboard.releaseAll(); break;
    case K_BOLD:  Keyboard.press(KEY_LEFT_CTRL); Keyboard.press('b'); Keyboard.releaseAll(); break;
    case K_ITAL:  Keyboard.press(KEY_LEFT_CTRL); Keyboard.press('i'); Keyboard.releaseAll(); break;
    case K_UNDR:  Keyboard.press(KEY_LEFT_CTRL); Keyboard.press('u'); Keyboard.releaseAll(); break;
    case K_CMNT:  Keyboard.press(KEY_LEFT_CTRL); Keyboard.press('/'); Keyboard.releaseAll(); break;
    case K_DUPL:  Keyboard.press(KEY_LEFT_CTRL); Keyboard.press('d'); Keyboard.releaseAll(); break;
    case K_INDL:  Keyboard.press(KEY_LEFT_SHIFT); Keyboard.press(KEY_TAB); Keyboard.releaseAll(); break;
    case K_INDR:  Keyboard.press(KEY_TAB); Keyboard.releaseAll(); break;
    case K_ENT:   Keyboard.press(KEY_RETURN); Keyboard.releaseAll(); break;
  }
}

const char* getKeyLabel(uint8_t key) {
  switch (key) {
    case K_UNDO:  return "UNDO";
    case K_REDO:  return "REDO";
    case K_COPY:  return "COPY";
    case K_PASTE: return "PASTE";
    case K_SAVE:  return "SAVE";
    case K_FIND:  return "FIND";
    case K_ALL:   return "ALL";
    case K_BOLD:  return "BOLD";
    case K_ITAL:  return "ITAL";
    case K_UNDR:  return "UNDR";
    case K_CMNT:  return "CMNT";
    case K_DUPL:  return "DUPL";
    case K_INDL:  return "IND<";
    case K_INDR:  return "IND>";
    case K_ENT:   return "ENT";
    default:      return "KEY";
  }
}

void onKeyPress(int r, int c) {
  uint8_t key      = keymap[currentLayer][r][c];
  pressedKey[r][c] = key;
  if (key == K_EMPTY) return;

  if (currentLayer == LAYER_NUMPAD) {
    if (key == K_ENT) {
      Keyboard.press(KEY_RETURN);
      strncpy(lastKeyStr, "ENT", sizeof(lastKeyStr) - 1);
    } else {
      Keyboard.press((char)key);
      char buf[4] = {(char)key, 0};
      strncpy(lastKeyStr, buf, sizeof(lastKeyStr) - 1);
    }
  } else {
    pressSpecial(key);
    strncpy(lastKeyStr, getKeyLabel(key), sizeof(lastKeyStr) - 1);
  }

  if (!menuActive) drawMainScreen();
}

void onKeyRelease(int r, int c) {
  uint8_t key      = pressedKey[r][c];
  pressedKey[r][c] = K_EMPTY;
  if (key == K_EMPTY) return;

  // only the numpad holds keys down; shortcuts already let go in pressSpecial
  if (currentLayer == LAYER_NUMPAD) {
    if (key == K_ENT) Keyboard.release(KEY_RETURN);
    else Keyboard.release((char)key);
  }
}
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

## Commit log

2026-07-15 Add three keyboard folders with firmware, cases, photos and docs
    Build out the repo for the MonkiiBoard39, MonkiiPad20 and MonkiiPad3x3.
    Each folder carries its Arduino firmware, the print ready case plates and
    a readme written in a plain, natural voice.
    - MonkiiBoard39: 4x10 ortho firmware with sticky modifiers and a double
    tap Windows key, plus top and bottom plates
    - MonkiiPad20: RP2040 macropad firmware with an OLED, Shortcuter and
    Typist layers, an FN hold layer toggle and a robot eye screensaver
    - MonkiiPad3x3: nine key firmware that toggles between a number pad and a
    macro layer on a long press, with the VOID9 case options
    - Wire product photos from Medias into every readme and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
    [4x10_bottom_plate.stl, 4x10_top_plate.stl, MonkiiPad20_bottom_plate.stl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]
2026-07-21 Rewrite the firmware comments in my own voice
    Went back through all three sketches and rewrote the comments the way I
    would actually explain the code. Cut the ascii banners and anything that
    just restated the line below it, and kept the notes that explain why
    something is the way it is.
    Also fixed two labels on the MonkiiPad3x3 that said Ctrl+C and Ctrl+V
    when the code has always sent Ctrl+Z and Ctrl+Y. Renamed them to undo
    and redo, the behaviour is unchanged.
    [MonkiiBoard39.ino, MonkiiPad20.ino, MonkiiPad3x3.ino]
2026-07-24 added PCB files for the MonkiiBoard20 as well as a readme for details
    [MonkiiPad20-B_Cu.gbr, MonkiiPad20-B_Mask.gbr, MonkiiPad20-B_Silkscreen.gbr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]
2026-07-24 update readmes: from pico boards (mistake) to rp2040 zero waveshare
2026-08-15 added guides for MonkiiPad16
    [MonkiiPad16_bottom_plate.stl, MonkiiPad16_top_plate.stl]
2026-08-23 Added official images for the MonkiiPad16 and the assembled MonkiiPad20's PCB version 1!
2026-08-23 added MonkiiPad20 PCB images in overall readme
2026-09-02 added a specific folder containing all and future PCB files
    [MonkiiPad20-B_Cu.gbr, MonkiiPad20-B_Mask.gbr, MonkiiPad20-B_Silkscreen.gbr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]
2026-09-02 added medias related to MonkiiPad20 PCB schematics
    [MonkiiPad20-B_Cu.gbr, MonkiiPad20-B_Mask.gbr, MonkiiPad20-B_Silkscreen.gbr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]
2026-09-08 added monkiipad3x3 pcb and monkiiboard39 pcb. Added kicad PCB editing files for users to customize/tune their own MonkiiBoards' PCB versions
    [MonkiiBoard39-B_Cu.gbr, MonkiiBoard39-B_Mask.gbr, MonkiiBoard39-B_Paste.gbr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]
2026-09-23 MonkiiBoard58 PCB added
    [MonkiiBoard58-B_Cu.gbr, MonkiiBoard58-B_Mask.gbr, MonkiiBoard58-B_Paste.gbr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]
2026-09-23 edit/remove battery voltage divider
